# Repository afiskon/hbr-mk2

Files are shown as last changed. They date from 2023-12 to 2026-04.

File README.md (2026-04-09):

# HBR/MK2

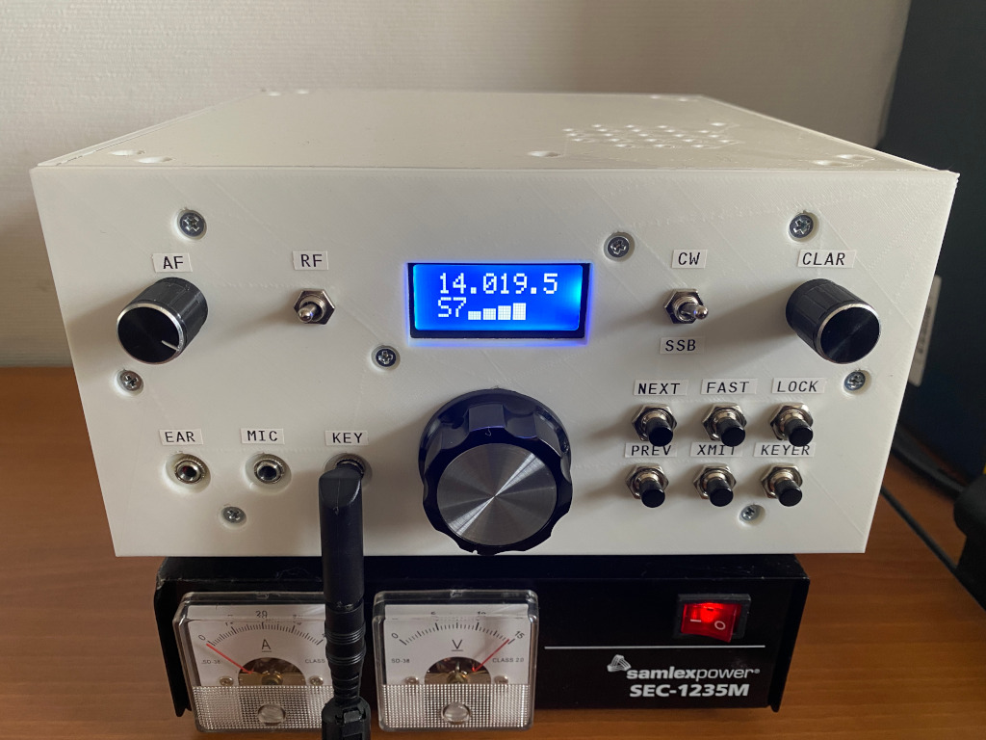
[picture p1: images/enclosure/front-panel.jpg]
HBR/MK2


All HF bands QRP CW/SSB transceiver "HomeBrew Radio, Mark 2".

* Covers 80, 40, 30, 20, 17, 15, 12 and 10 meters
* Classical single IF superheterodyne design
* Effective IF derived AGC
* Voice compression
* Supports RIT and XIT
* 10-30 WPM Elekey-B type keyer + straight key mode
* Keyer supports record and playback, programmable with paddles
* Five favorite frequencies per band (press NEXT/PREV in FAST mode)
* Class AB amplifier provides 5-10W in both CW and SSB
* Has a S-meter and a SWR meter
* Open-source firmware, schematic and 3D-printable enclosure

Links:

* Article (in Russian): https://eax.me/2024/2024-05-12-hbr-mk2-transceiver.html
* Post on Hackaday: https://hackaday.com/2024/05/13/github-hosts-ham-radio/
* Post on DXZone: https://www.dxzone.com/hbr-mk2-hf-qrp-cw-ssb-transceiver/
* Video blog on YouTube: https://www.youtube.com/playlist?list=PL6CWlCy5akj5v1Z4mPysYlqgNtCBYy-wM
* Video blog on Archive.org: https://archive.org/details/hbr-mk2-videos

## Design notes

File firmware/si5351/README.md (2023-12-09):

# stm32-si5351

HAL-based Si5351 driver for STM32.

Main respository: https://github.com/afiskon/stm32-si5351

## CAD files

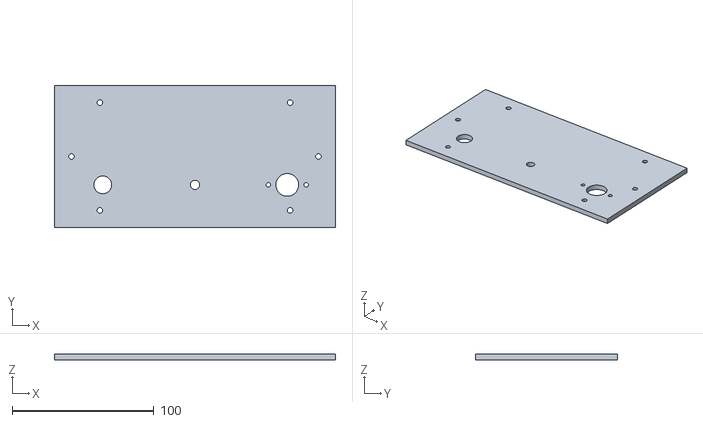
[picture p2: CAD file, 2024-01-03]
enclosure/back.stl
198.0 x 100.0 x 4.00

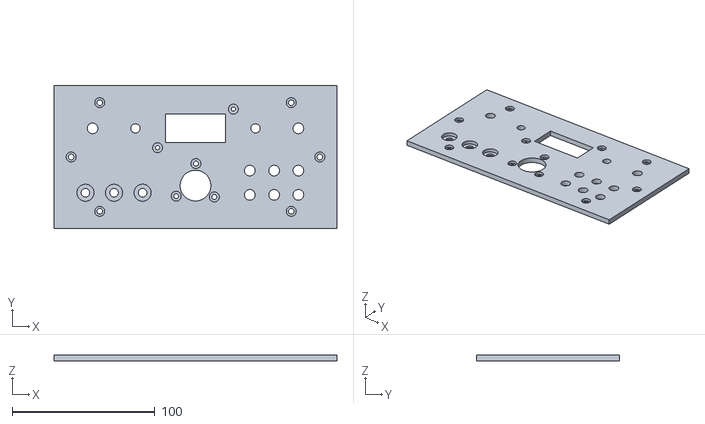
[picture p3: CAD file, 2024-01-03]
enclosure/front.stl
198.0 x 100.0 x 4.00

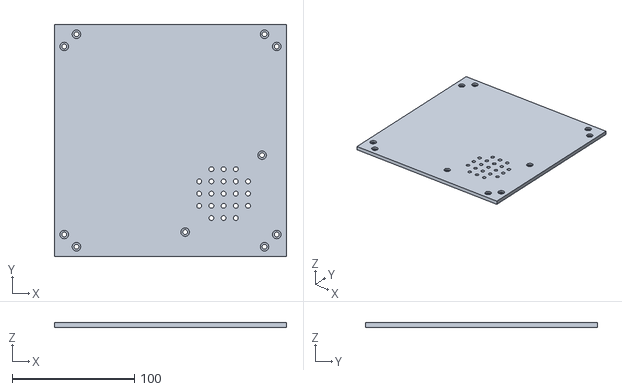
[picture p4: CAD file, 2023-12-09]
enclosure/top.stl
190.0 x 190.0 x 4.00

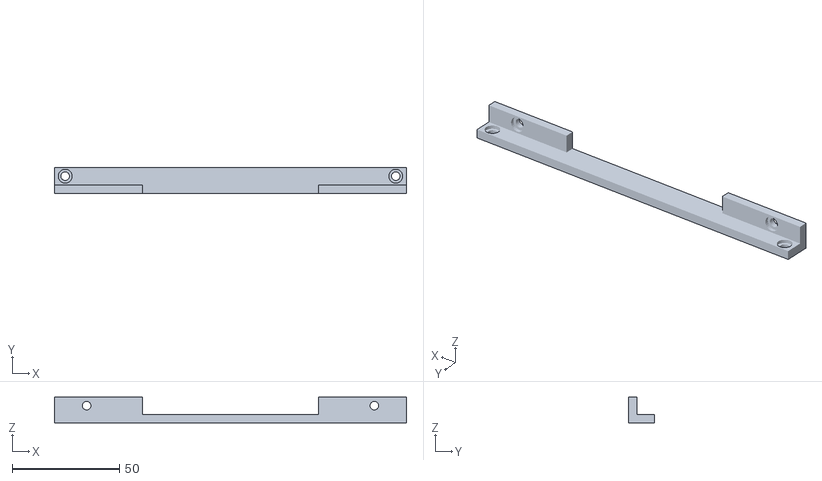
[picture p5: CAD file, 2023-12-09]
enclosure/large_angle.stl
164.0 x 12.0 x 12.0

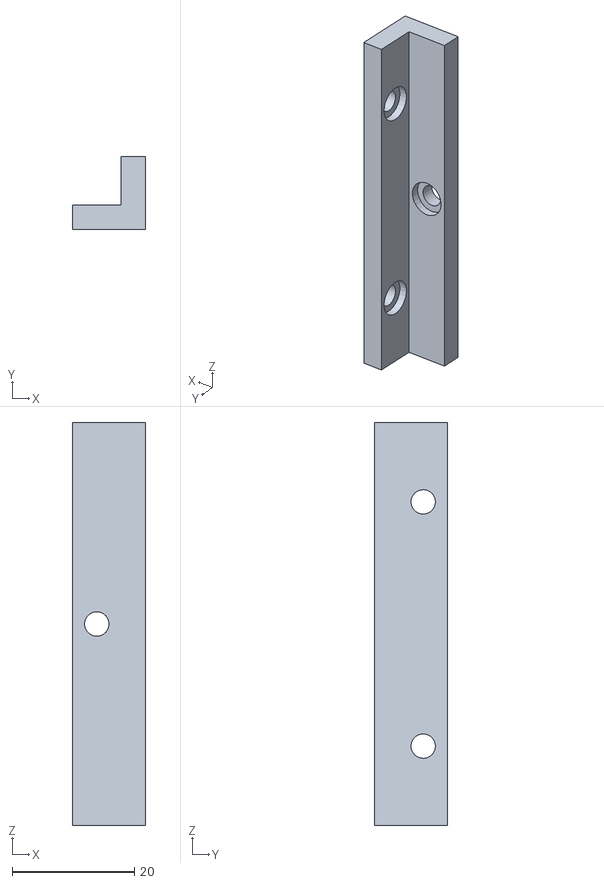
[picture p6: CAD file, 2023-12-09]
enclosure/small_angle.stl
12.0 x 12.0 x 66.0

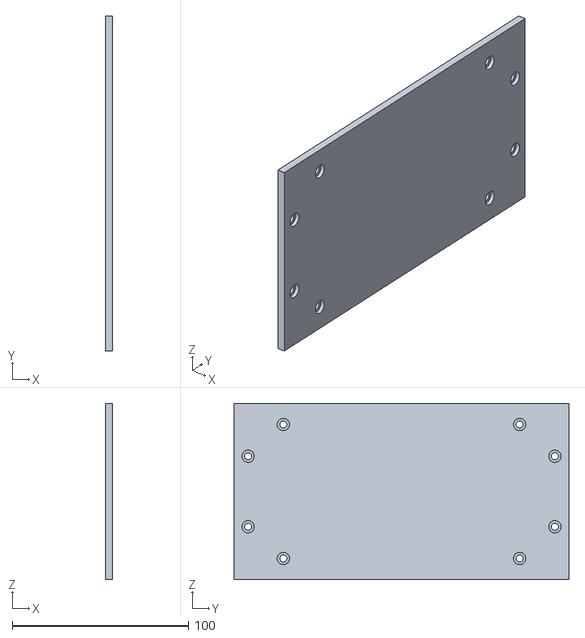
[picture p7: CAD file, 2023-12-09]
enclosure/side.stl
4.00 x 190.0 x 100.0

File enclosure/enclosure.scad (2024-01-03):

t = 4;
W = 190;
Front_W = W + t*2;
H = 100;

Angle_W = 12;
Large_Angle_L = W - 2*Angle_W - 2;
Small_Angle_L = H - 2*t - 2*Angle_W - 2;

Speaker_Dist_Between_Holes = 63;

pot_dia = 7+0.5; // volume control
jack_dia = 6; // 3.5 mm jack
jack_nut_dia = 12;
jack_nut_height = t-1.2;
button_dia = 7+0.5; // button
button_offset = 17;
toggle_dia = 6+0.5; // toggle switch
corner_dia = 7;
screw_dia = 4;
screw_offset = t*3;
screw_extra_offset = 20;
screw2_dia = 7;
screw2_height = 2;
nut_dia = 6.5;
nut_height = 1.5;
eps = 0.01;

main_enc_dia = 21+0.5;
main_enc_screws_dia = 15;
main_enc_screws_dist = 7;
main_enc_rotate_delta = 12;
main_enc_screw_dia = 3.5;
multi_enc_dia = 7+0.5; // CLAR pot

// LCD info
LCD_W = 58;
LCD_H = 32;
lcd_offset_y = 8;
lcd_offset_x = 6;
lcd_h = LCD_H - lcd_offset_x*2;
lcd_w = LCD_W - lcd_offset_y*2;

hole_dia = 3;
hole_offset_x = 1+hole_dia/2;
hole_offset_y = 1+hole_dia/2;

module so239() { // two holes
    front_d = 16;
    front_off = 18.8;
    front_hole_d = 3.2;

    rotate([0, 45, 0]) {
        translate([0, 0, 0]) rotate([90,0,0])
            cylinder(d=front_d,h=20, $fn=100, center=true);

        translate([-front_off/2, 0, -front_off/2]) rotate([90,0,0])
            cylinder(d=front_hole_d,h=20,$fn=100, center=true);

        translate([front_off/2, 0, front_off/2]) rotate([90,0,0])
            cylinder(d=front_hole_d,h=20,$fn=100, center=true);
    }
}

module speaker() {
    union() {
        translate([Speaker_Dist_Between_Holes/2, -Speaker_Dist_Between_Holes/2, 0]) {
            cylinder(d = screw_dia, h = 20, $fn = 20, center = true);
            translate([0, 0, -(t-screw2_height)/2-eps])
                cylinder(d = screw2_dia, h = screw2_height+eps, $fn = 25, center = true);
        }
                
        translate([-Speaker_Dist_Between_Holes/2, Speaker_Dist_Between_Holes/2, 0]) {
            cylinder(d = screw_dia, h = 20, $fn = 20, center = true);
            translate([0, 0, -(t-screw2_height)/2-eps])
                cylinder(d = screw2_dia, h = screw2_height+eps, $fn = 25, center = true);
        }
                
        translate([10, 20, 0]) cylinder(d = screw_dia, h = 20, $fn = 20, center = true);
        translate([0, 20, 0]) cylinder(d = screw_dia, h = 20, $fn = 20, center = true);
        translate([-10, 20, 0]) cylinder(d = screw_dia, h = 20, $fn = 20, center = true);
        
        translate([10, 10, 0]) cylinder(d = screw_dia, h = 20, $fn = 20, center = true);
        translate([10, 0, 0]) cylinder(d = screw_dia, h = 20, $fn = 20, center = true);
        translate([10, -10, 0]) cylinder(d = screw_dia, h = 20, $fn = 20, center = true);
        
        translate([20, 10, 0]) cylinder(d = screw_dia, h = 20, $fn = 20, center = true);
        translate([20, 0, 0]) cylinder(d = screw_dia, h = 20, $fn = 20, center = true);
        translate([20, -10, 0]) cylinder(d = screw_dia, h = 20, $fn = 20, center = true);

        translate([0, 0, 0]) cylinder(d = screw_dia, h = 20, $fn = 200, center = true);
        translate([0, -10, 0]) cylinder(d = screw_dia, h = 20, $fn = 20, center = true);
        translate([0, 10, 0]) cylinder(d = screw_dia, h = 20, $fn = 20, center = true);
        
        translate([-10, 10, 0]) cylinder(d = screw_dia, h = 20, $fn = 20, center = true);
        translate([-10, 0, 0]) cylinder(d = screw_dia, h = 20, $fn = 20, center = true);
        translate([-10, -10, 0]) cylinder(d = screw_dia, h = 20, $fn = 20, center = true);
        
        translate([-20, 10, 0]) cylinder(d = screw_dia, h = 20, $fn = 20, center = true);
        translate([-20, 0, 0]) cylinder(d = screw_dia, h = 20, $fn = 20, center = true);
        translate([-20, -10, 0]) cylinder(d = screw_dia, h = 20, $fn = 20, center = true); 
        
        translate([10, -20, 0]) cylinder(d = screw_dia, h = 20, $fn = 20, center = true);
        translate([0, -20, 0]) cylinder(d = screw_dia, h = 20, $fn = 20, center = true);
        translate([-10, -20, 0]) cylinder(d = screw_dia, h = 20, $fn = 20, center = true);
    }
}

module front_back_base() {
    difference() {
       cube([Front_W, H, t], center = true);
        
        // screws
        translate([-Front_W/2+screw_offset+screw_extra_offset, H/2-screw_offset, 0]) {
            cylinder(d = screw_dia, h = t*2, $fn = 25, center = true);
            translate([0, 0, (t-screw2_height)/2+eps])
                cylinder(d = screw2_dia, h = screw2_height+eps, $fn = 25, center = true);
        } 
        
        translate([-Front_W/2+screw_offset+screw_extra_offset, -H/2+screw_offset, 0]) {
            cylinder(d = screw_dia, h = t*2, $fn = 25, center = true);
            translate([0, 0, (t-screw2_height)/2+eps])
                cylinder(d = screw2_dia, h = screw2_height+eps, $fn = 25, center = true);
        }
        
        translate([Front_W/2-screw_offset-screw_extra_offset, H/2-screw_offset, 0]) {
            cylinder(d = screw_dia, h = t*2, $fn = 25, center = true);
            translate([0, 0, (t-screw2_height)/2+eps])
                cylinder(d = screw2_dia, h = screw2_height+eps, $fn = 25, center = true);
        }
        
        translate([Front_W/2-screw_offset-screw_extra_offset, -H/2+screw_offset, 0]) {
            cylinder(d = screw_dia, h = t*2, $fn = 25, center = true);
            translate([0, 0, (t-screw2_height)/2+eps])
                cylinder(d = screw2_dia, h = screw2_height+eps, $fn = 25, center = true);
        }
        
        // center screws
       translate([-Front_W/2+screw_offset, 0, 0]) {
            cylinder(d = screw_dia, h = t*2, $fn = 25, center = true);
            translate([0, 0, (t-screw2_height)/2+eps])
                cylinder(d = screw2_dia, h = screw2_height+eps, $fn = 25, center = true);
        }
        translate([Front_W/2-screw_offset, 0, 0]) {
            cylinder(d = screw_dia, h = t*2, $fn = 25, center = true);
            translate([0, 0, (t-screw2_height)/2+eps])
                cylinder(d = screw2_dia, h = screw2_height+eps, $fn = 25, center = true);
        } 
    }
}
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

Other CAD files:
enclosure/bottom.stl

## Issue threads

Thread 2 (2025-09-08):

Request for information

hanslammerts, 2025-09-08:
Hi,

Thinking of building this trx.
I'm missing some info though.

Can you please tell me what wire you used for all the coils ?
I also cannot find any info about the rotary encoder used.

Thanks, 73,
Hans
PA3CRZ

afiskon, 2025-09-09:
Thanks for your interest to the project.

Personally I used 0.3 mm thick (~ AWG 28) for small coils (e.g. BPFs) and 0.6 mm thick for larger ones (e.g. PA).

The wire gauge is not critical however.

afiskon, 2025-09-10:
@hanslammerts  If I'm not wrong, the particular model is E38S6G5-600B-G24N (took a similar one from my box of spare parts). This being said all such optical encoders are more or less the same, so there is no need to look for this particular model.

Closed 2025-09-09.

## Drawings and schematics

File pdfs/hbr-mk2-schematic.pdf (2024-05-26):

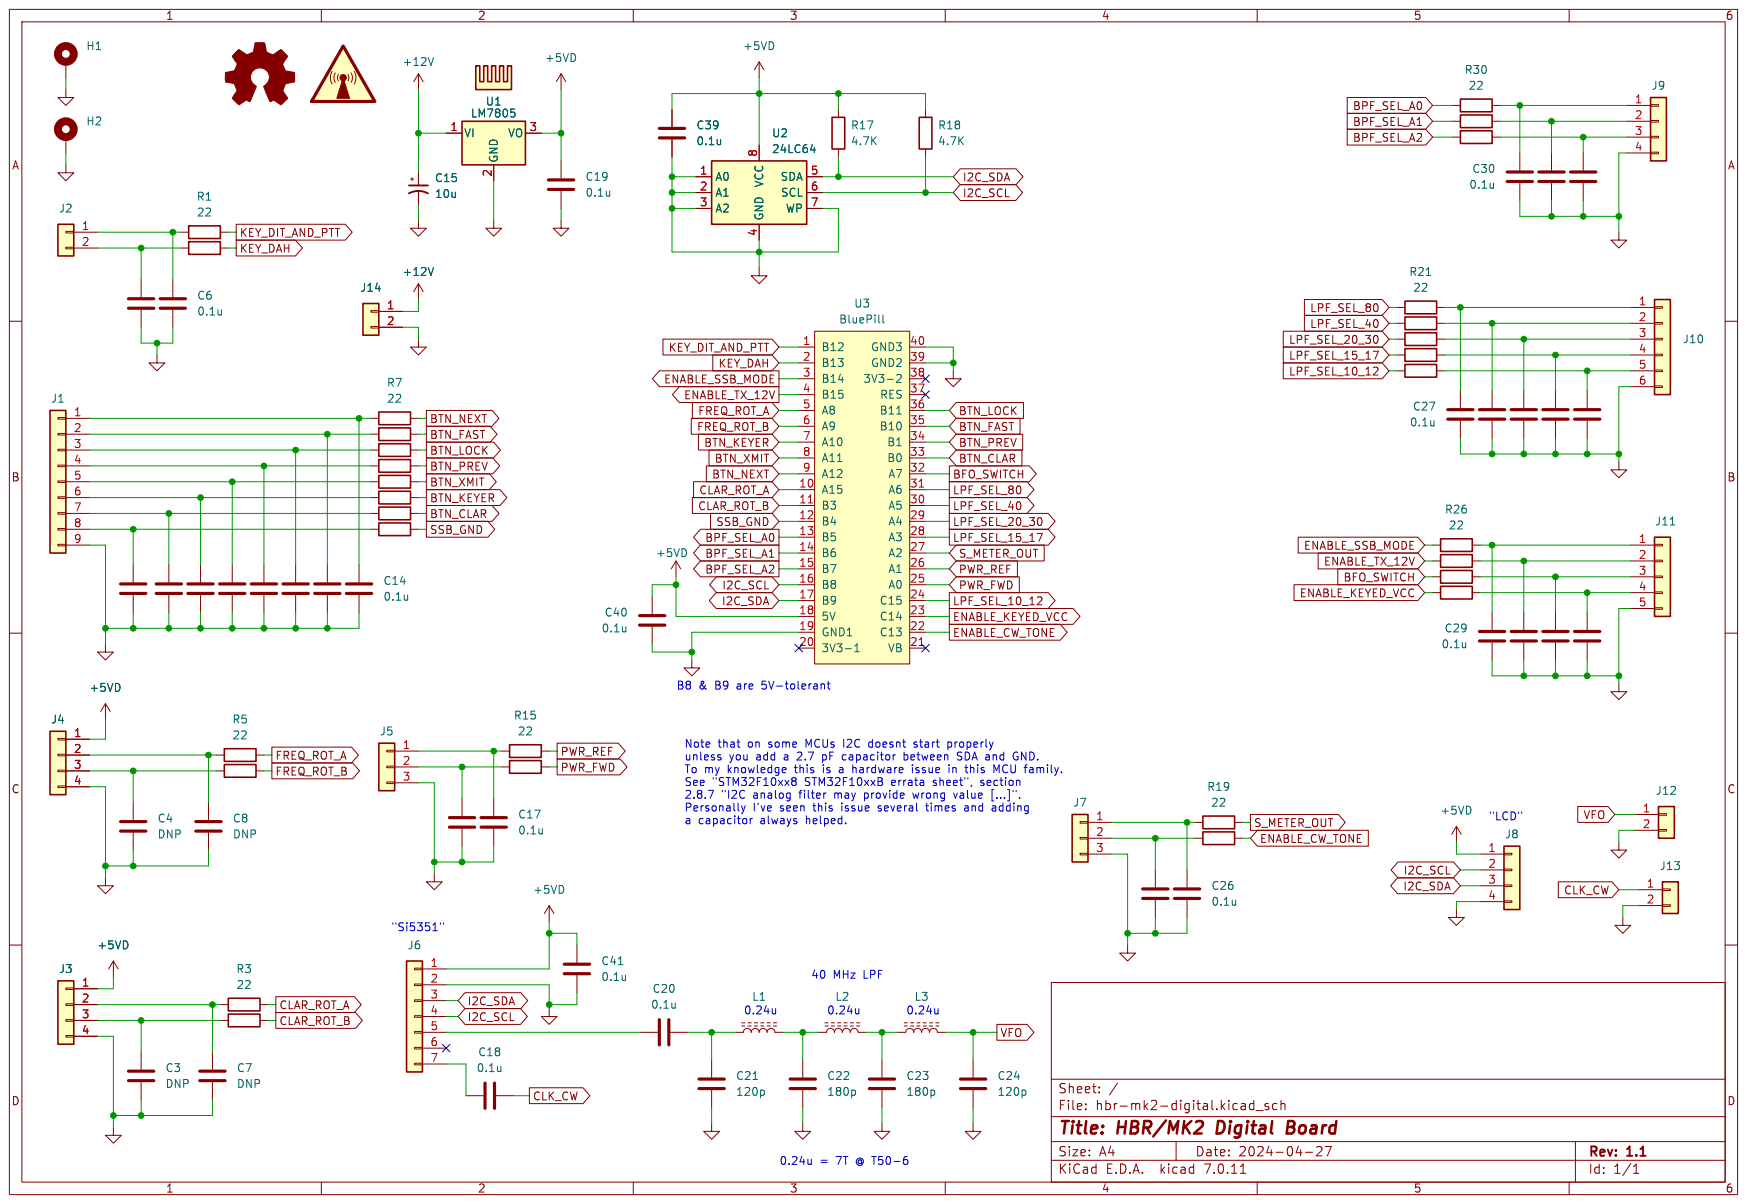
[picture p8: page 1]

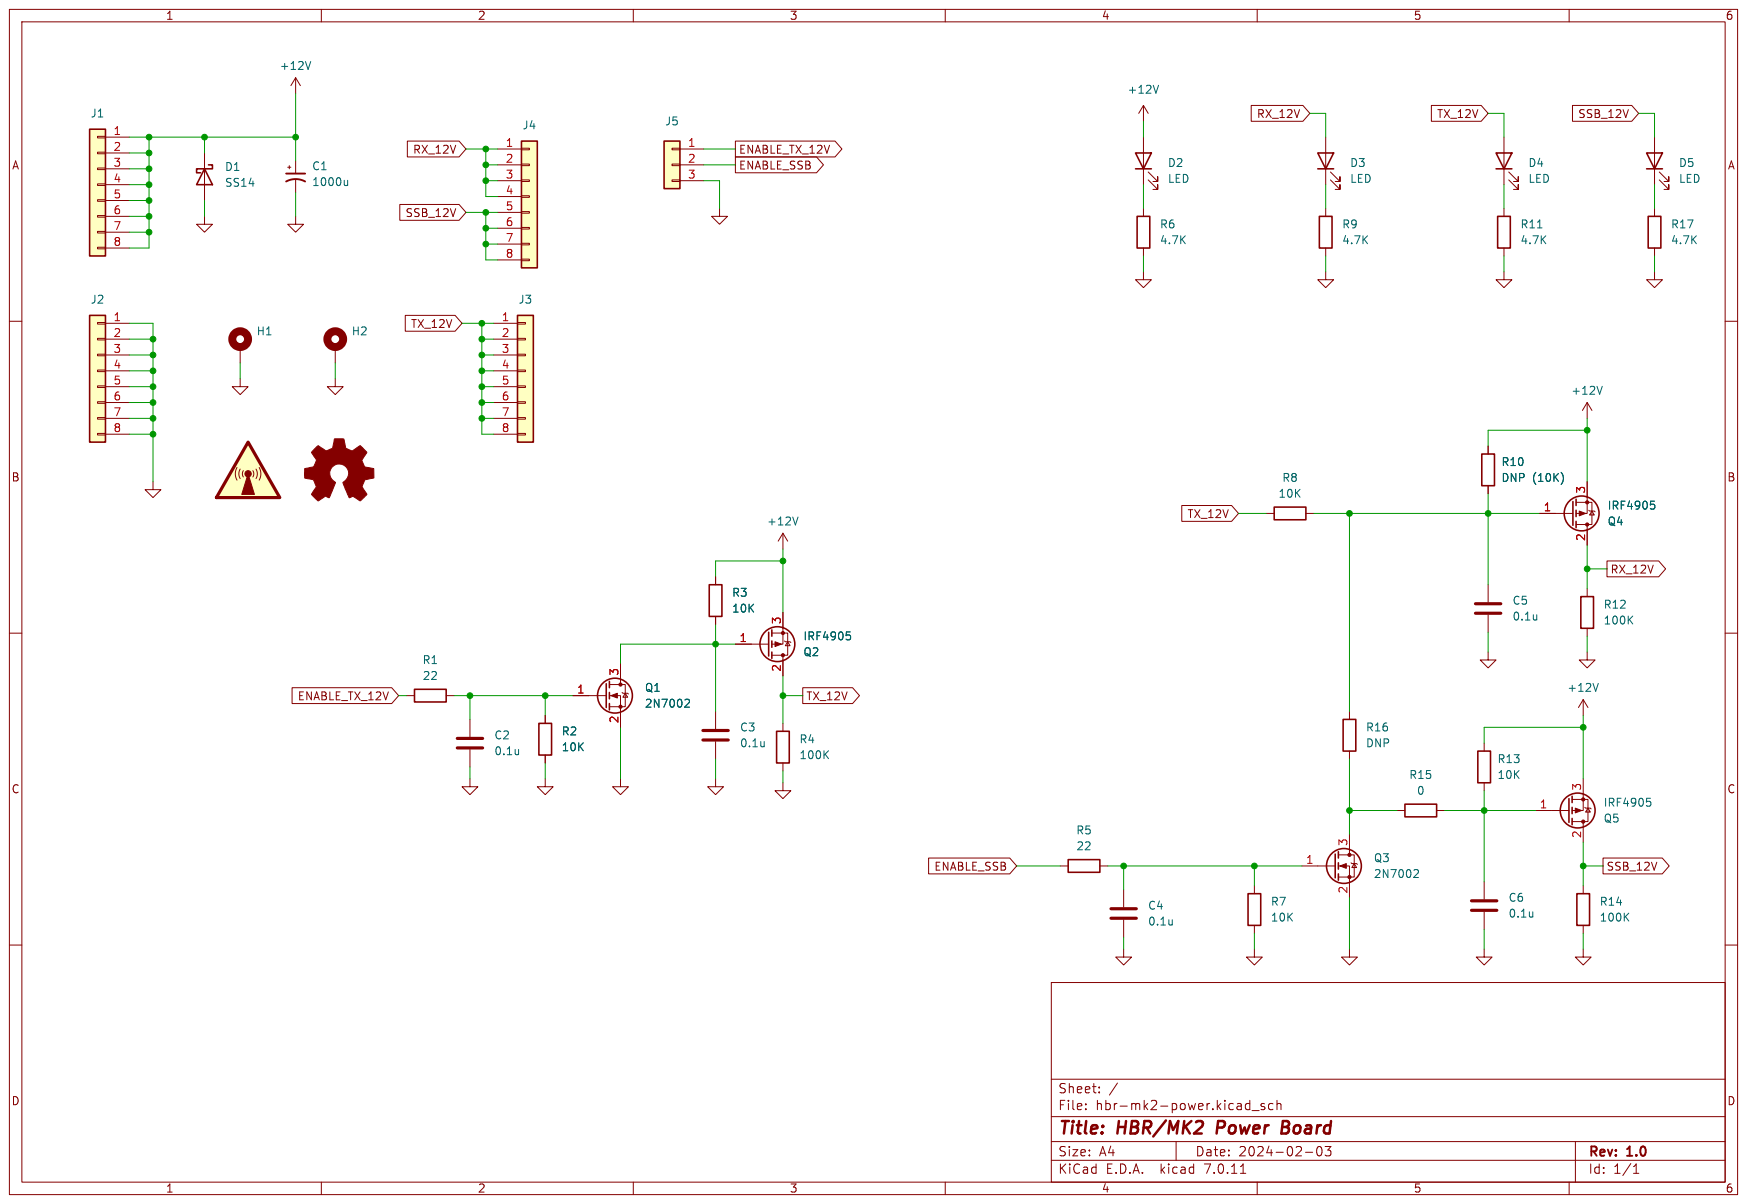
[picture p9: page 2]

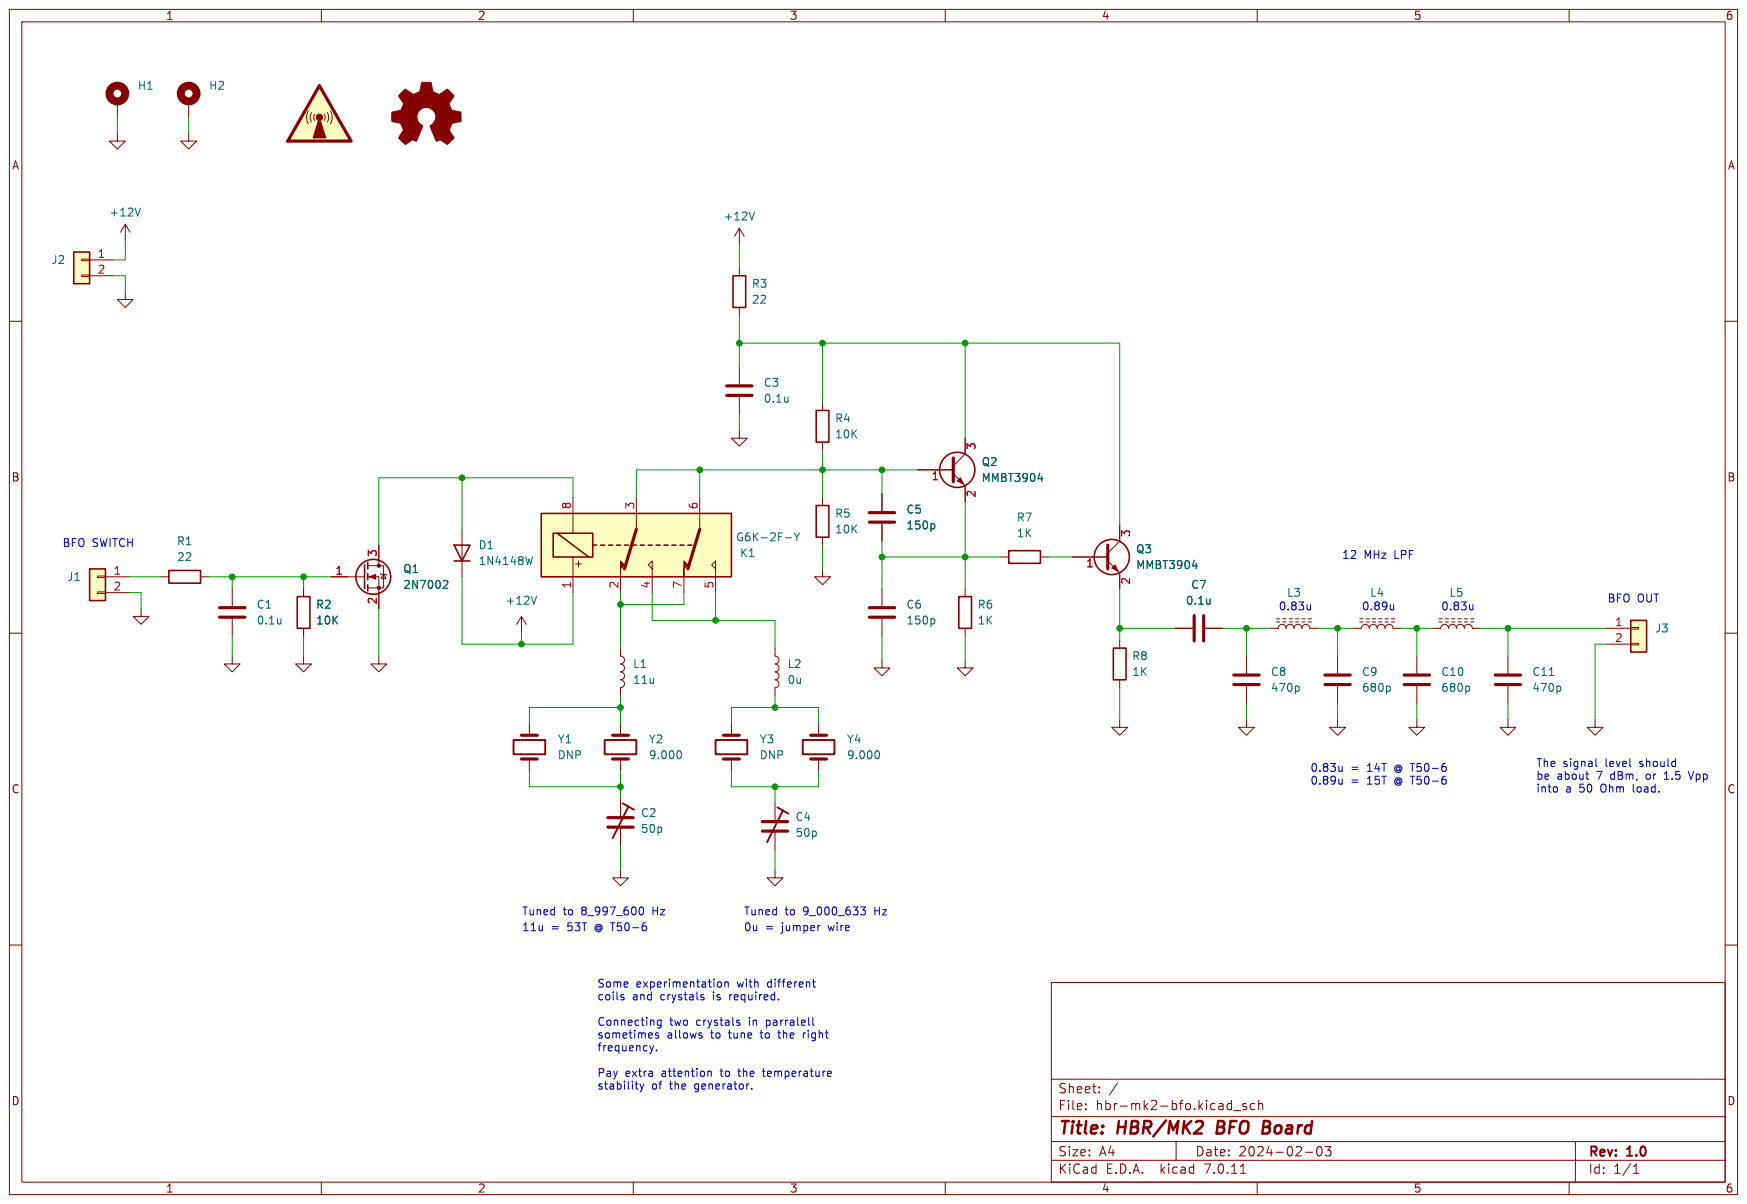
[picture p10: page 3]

be about 7 dBm, or 1.5 Vpp
into a 50 Ohm load.

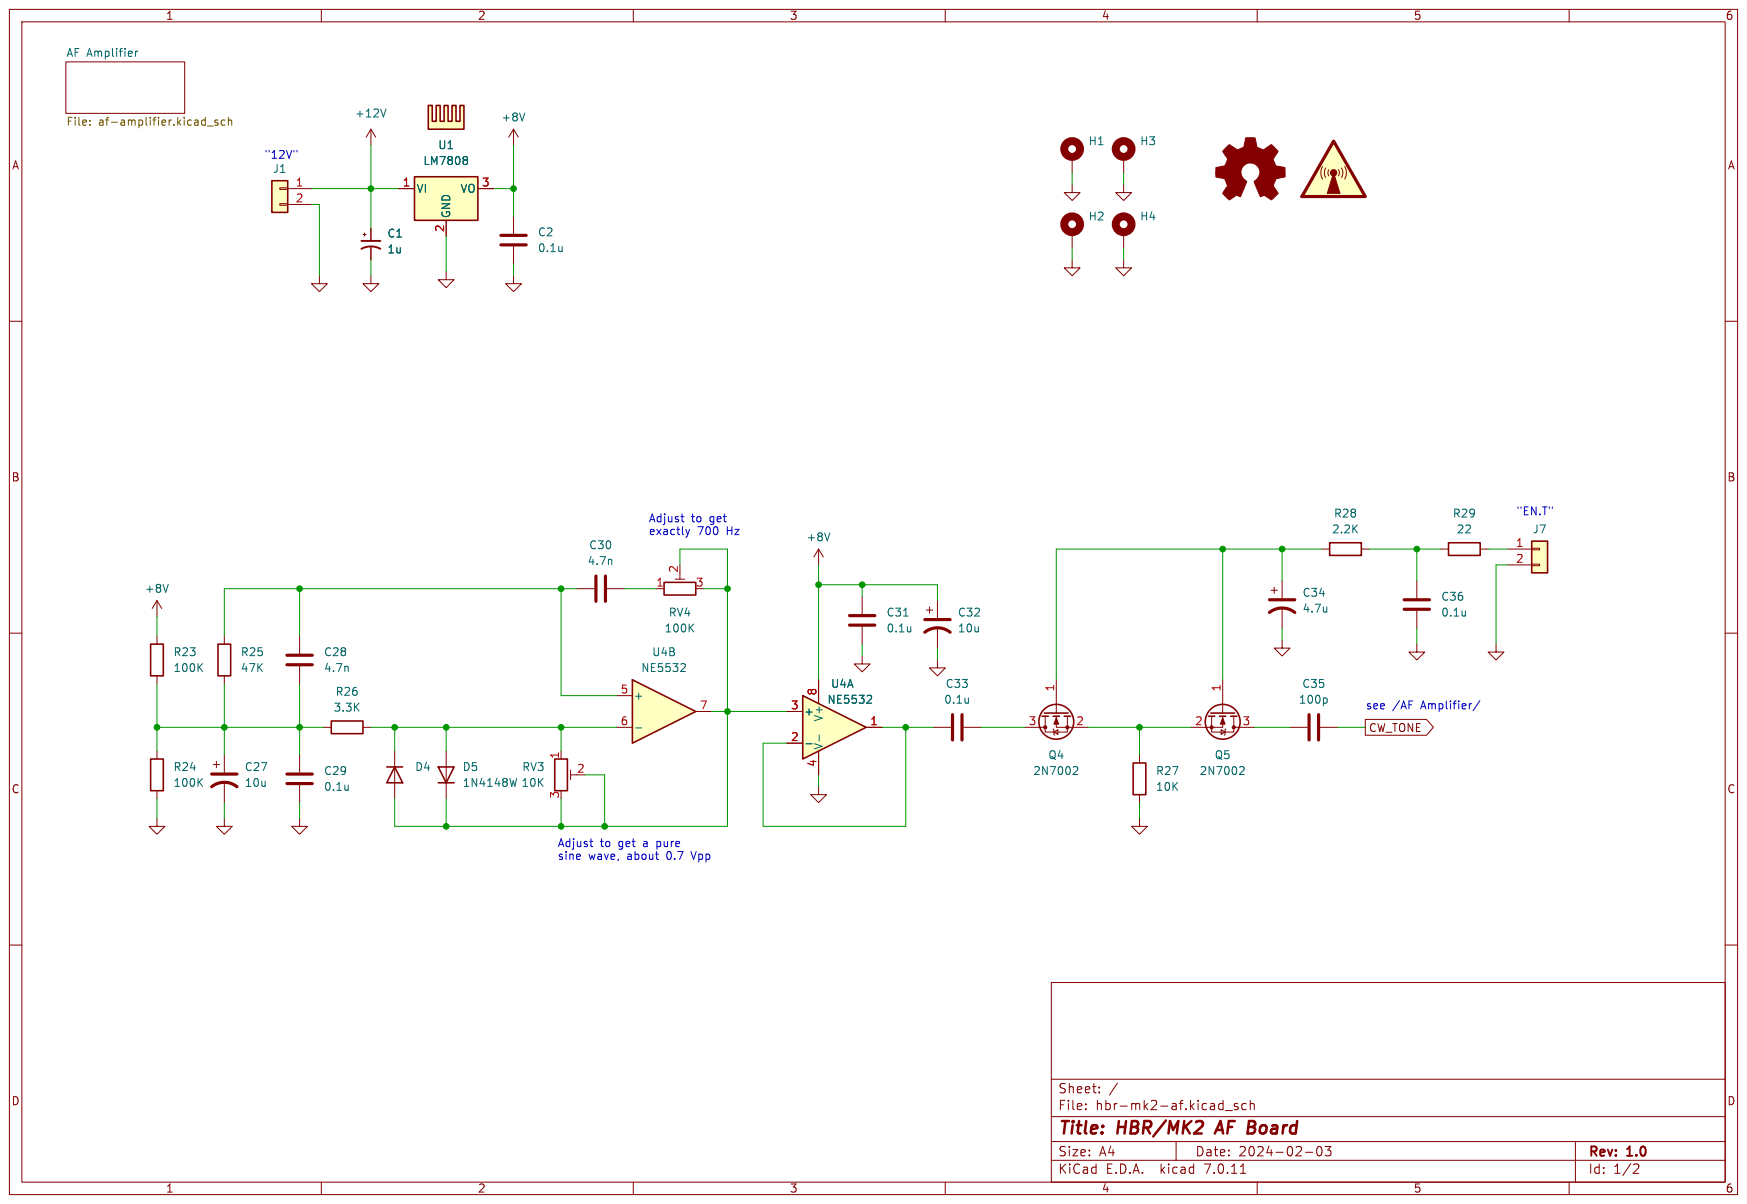
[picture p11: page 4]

Adjust to get a pure
sine wave, about 0.7 Vpp

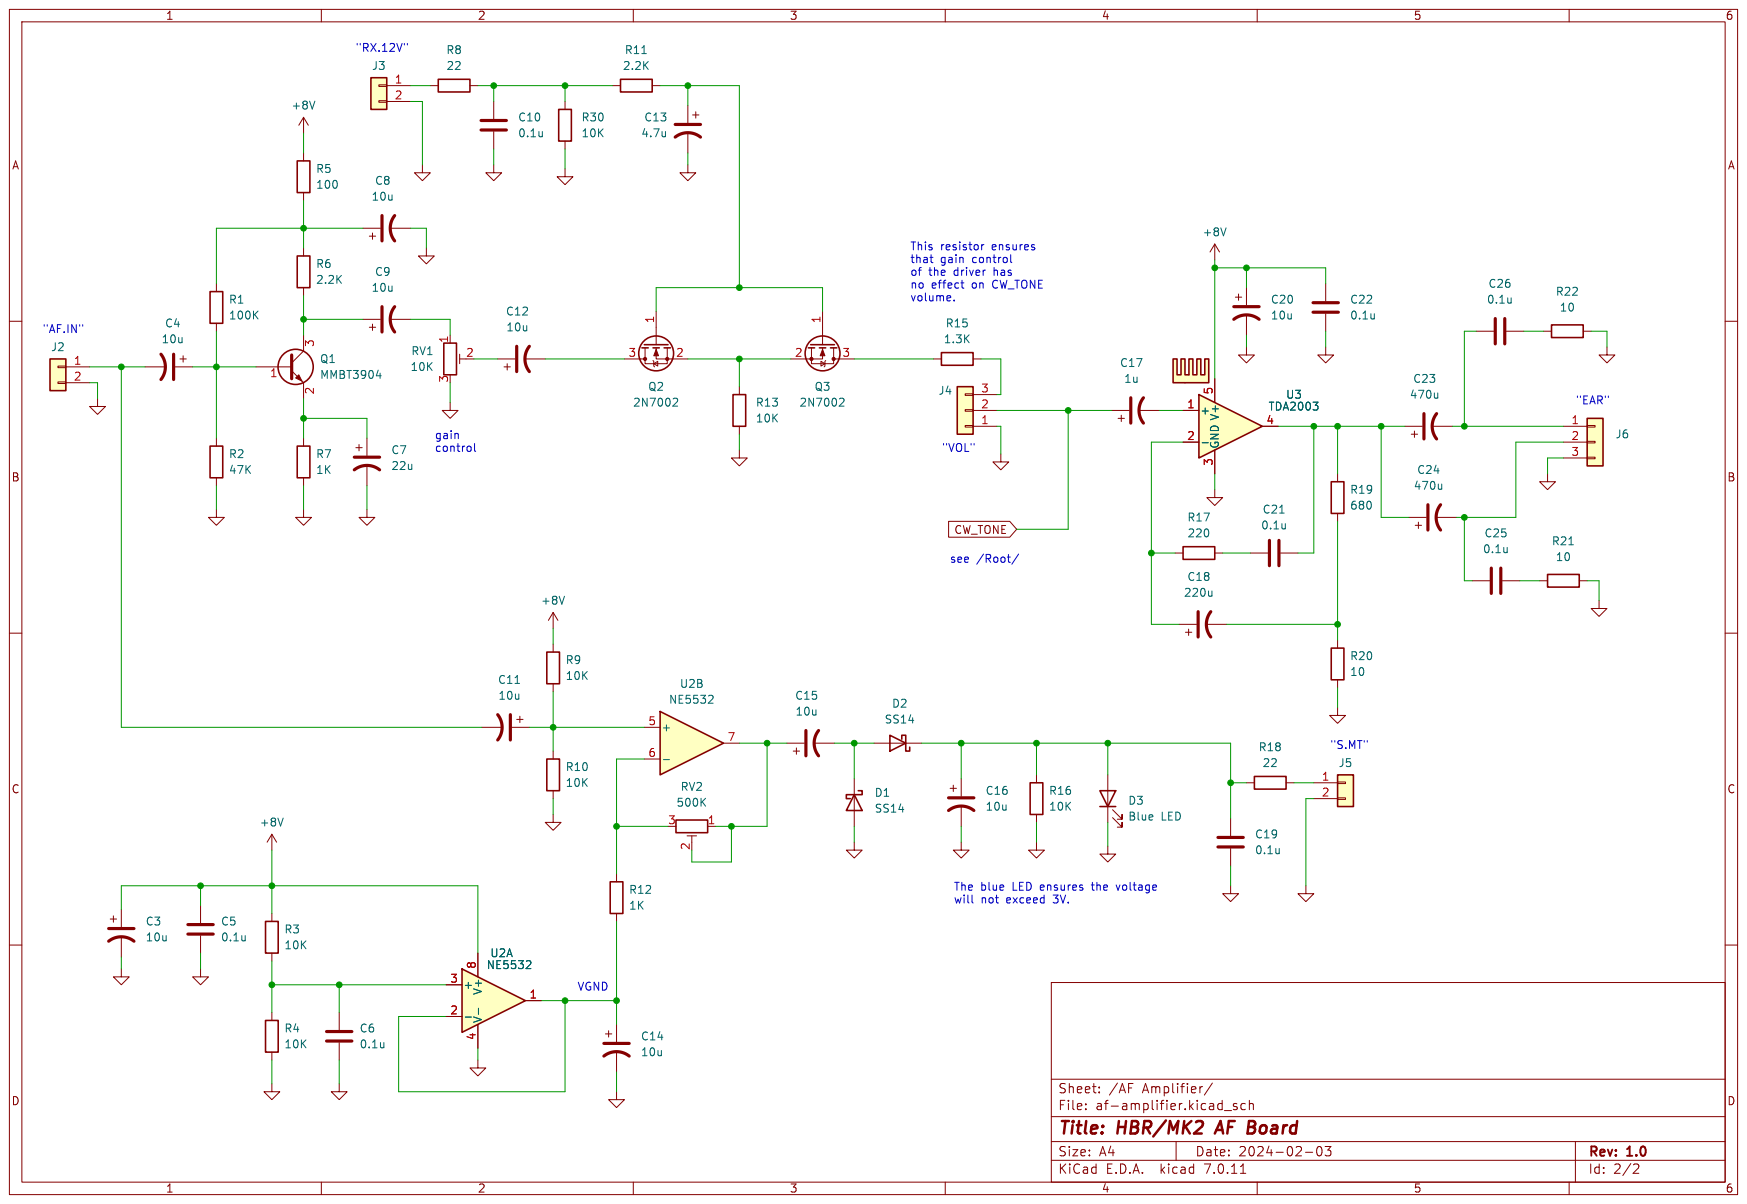
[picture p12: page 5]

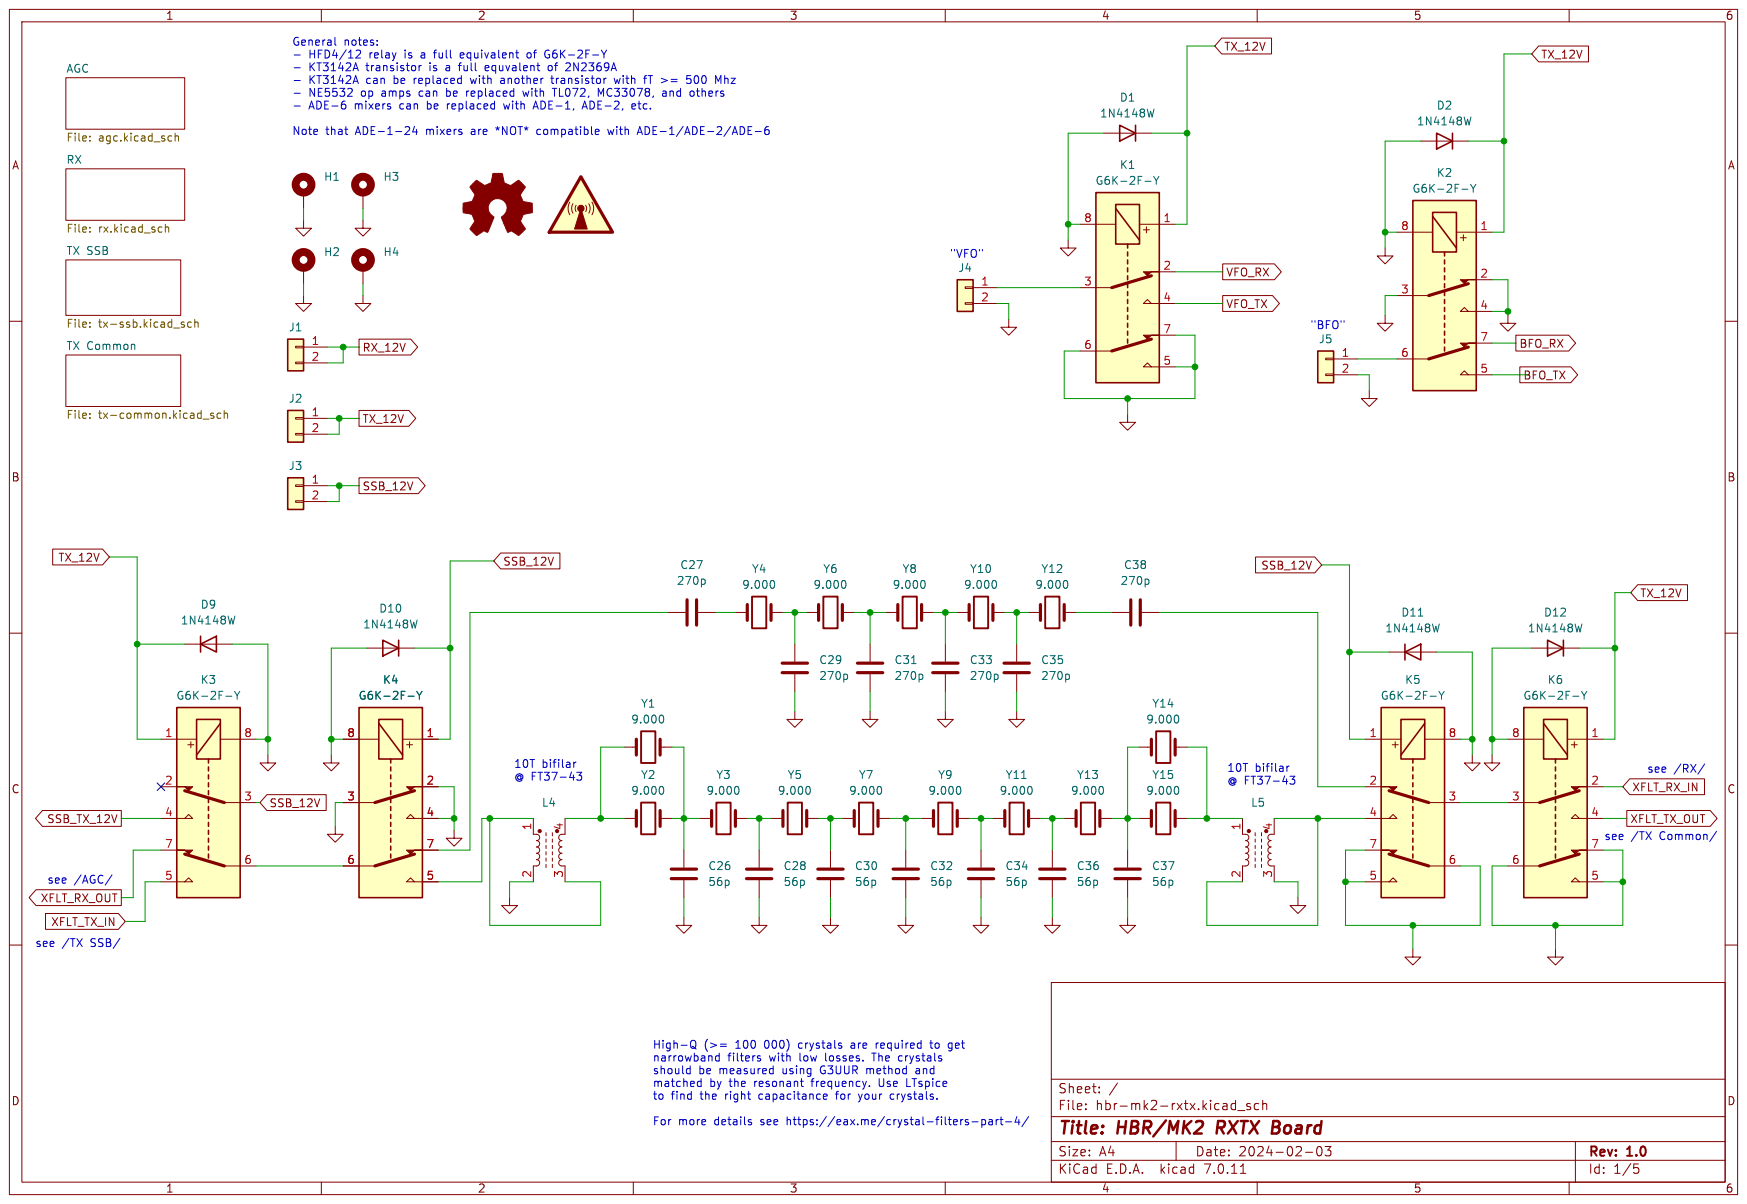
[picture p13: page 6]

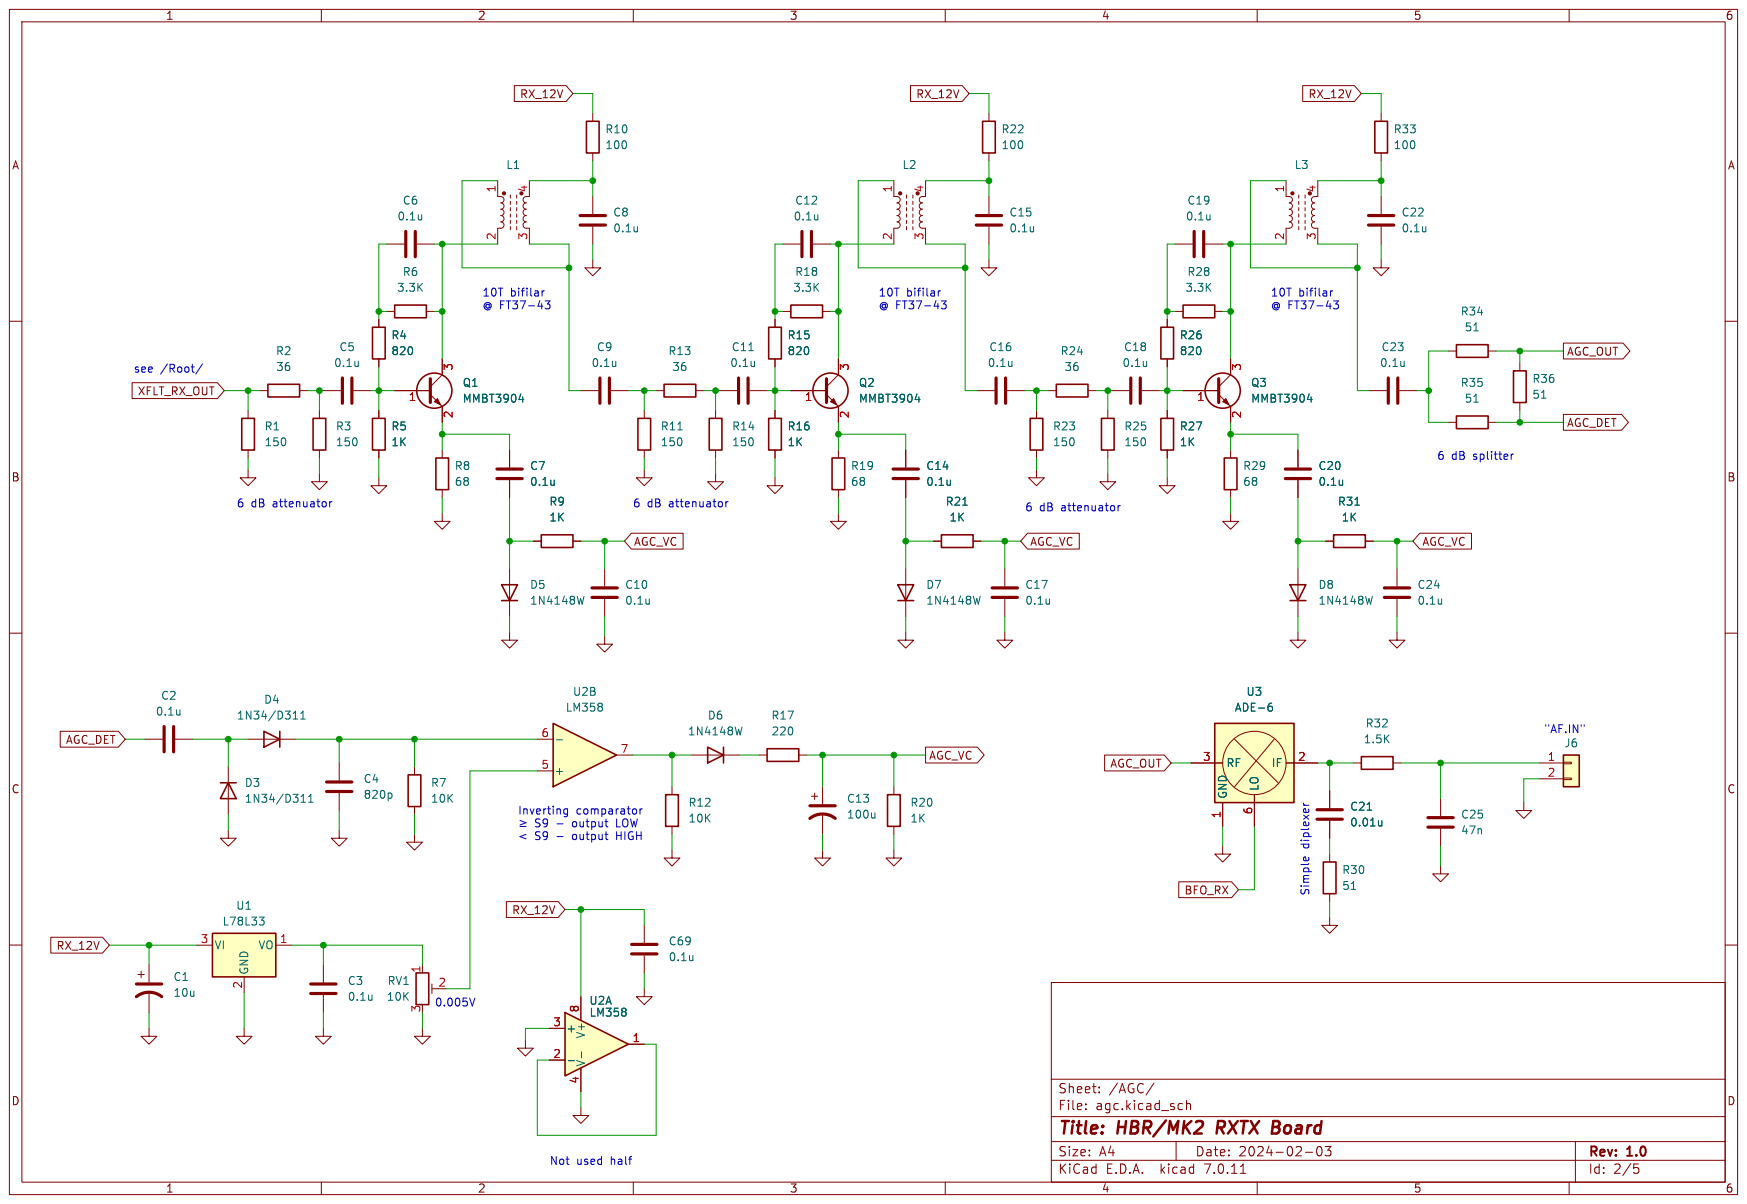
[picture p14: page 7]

6 dB attenuator

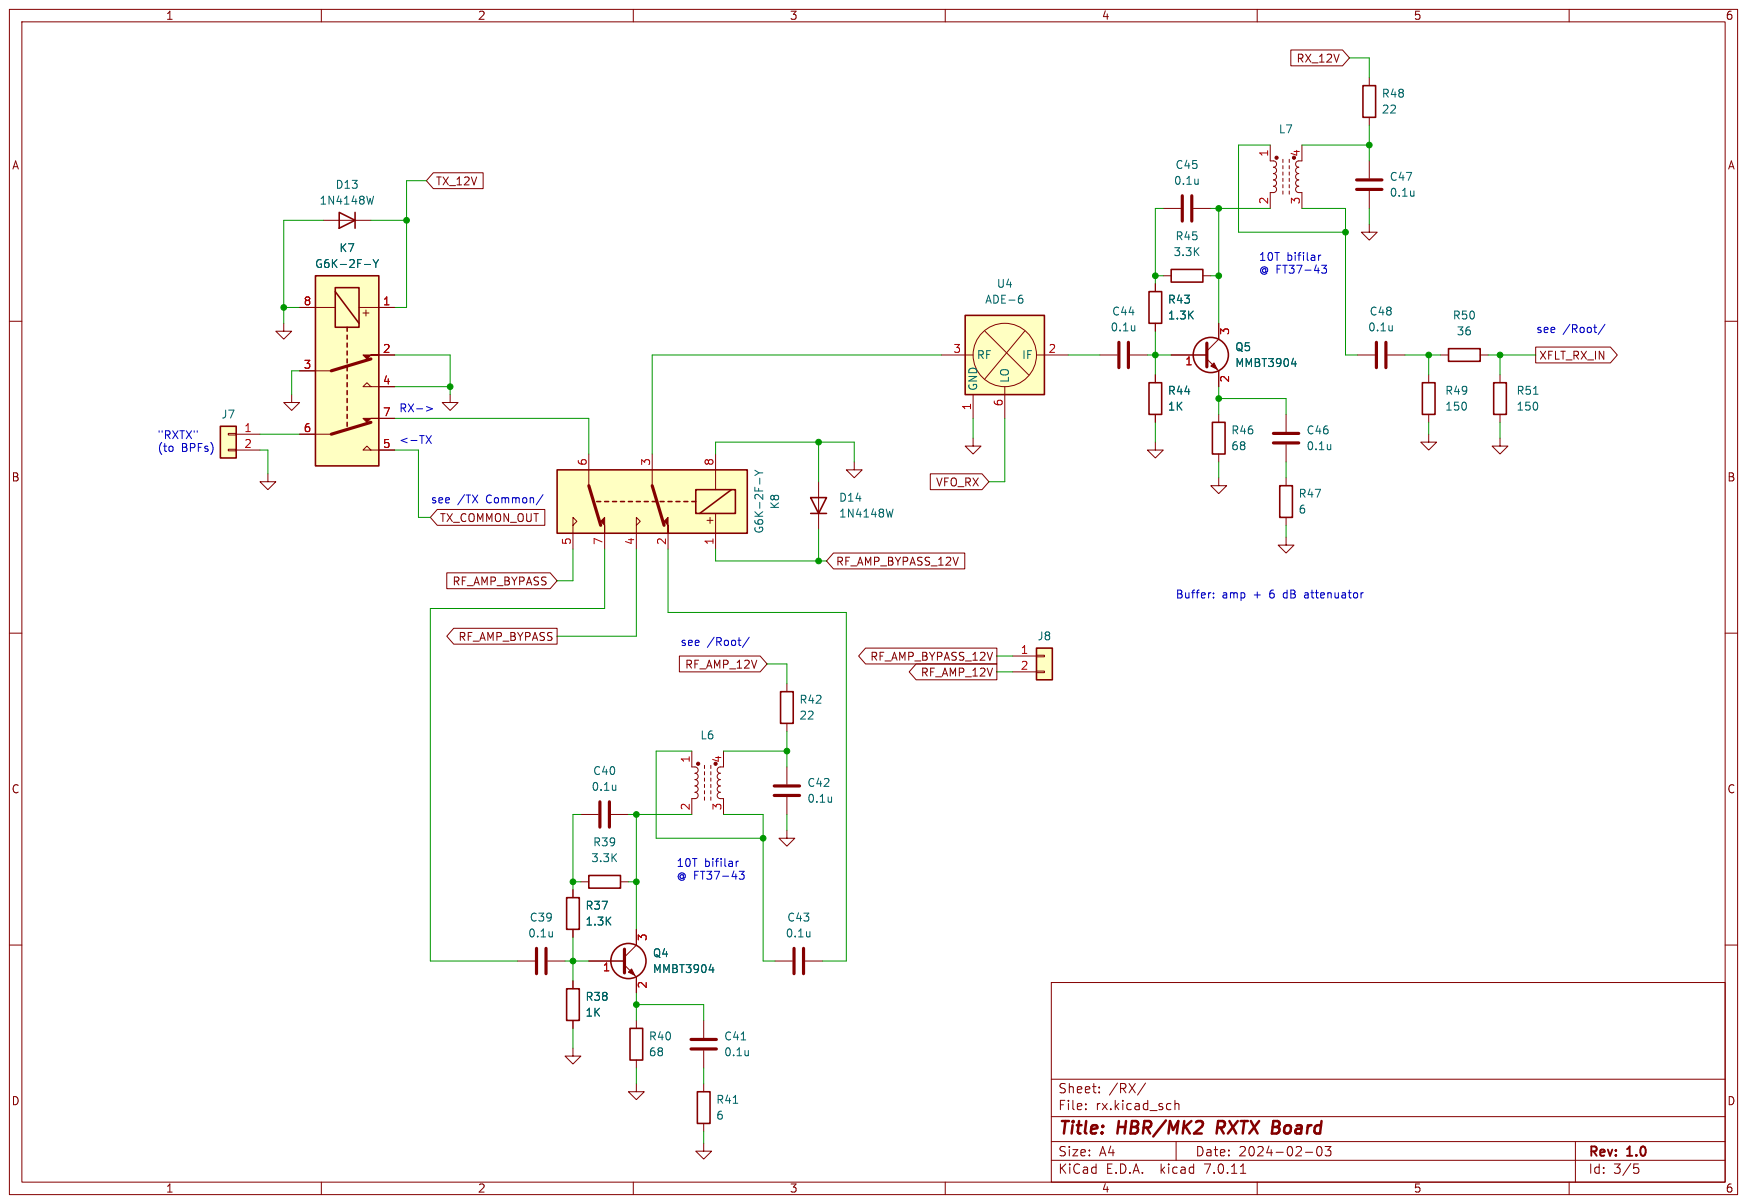
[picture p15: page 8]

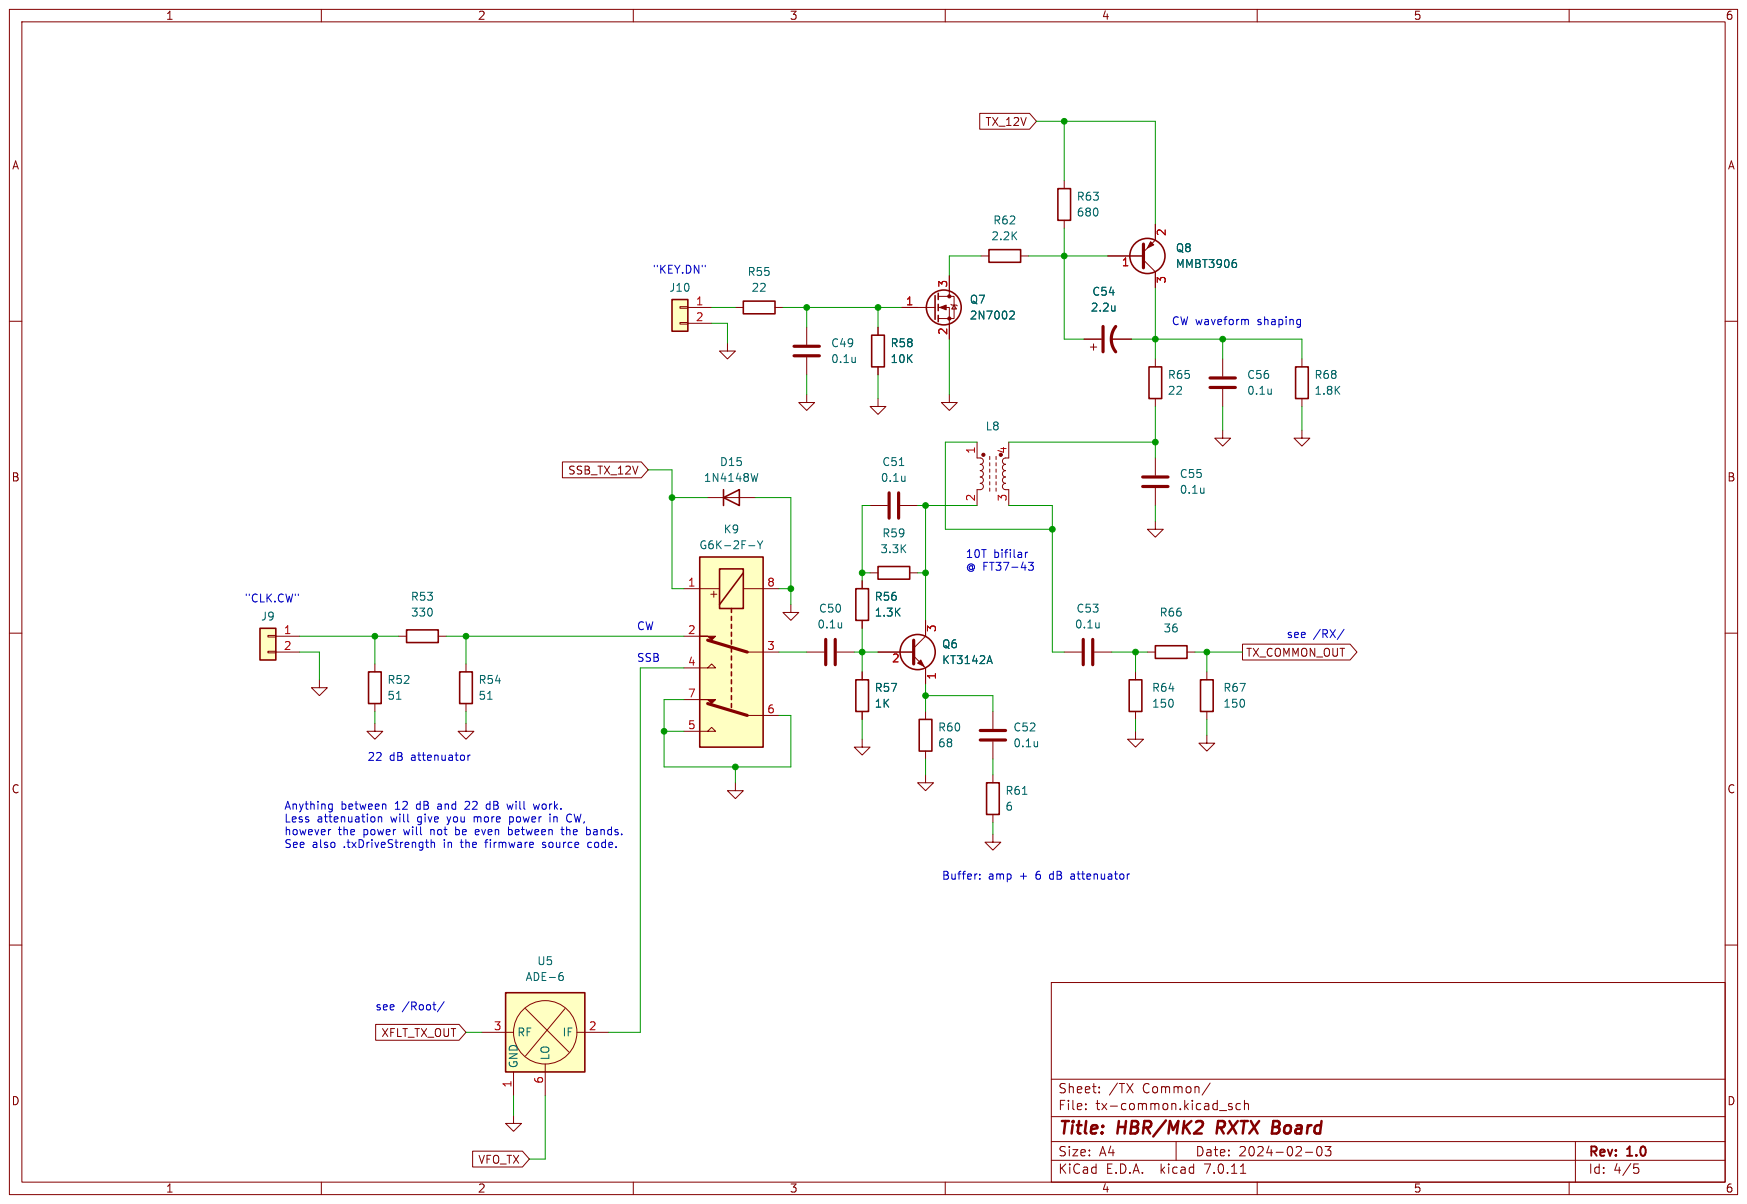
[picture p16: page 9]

however the power will not be even between the bands.

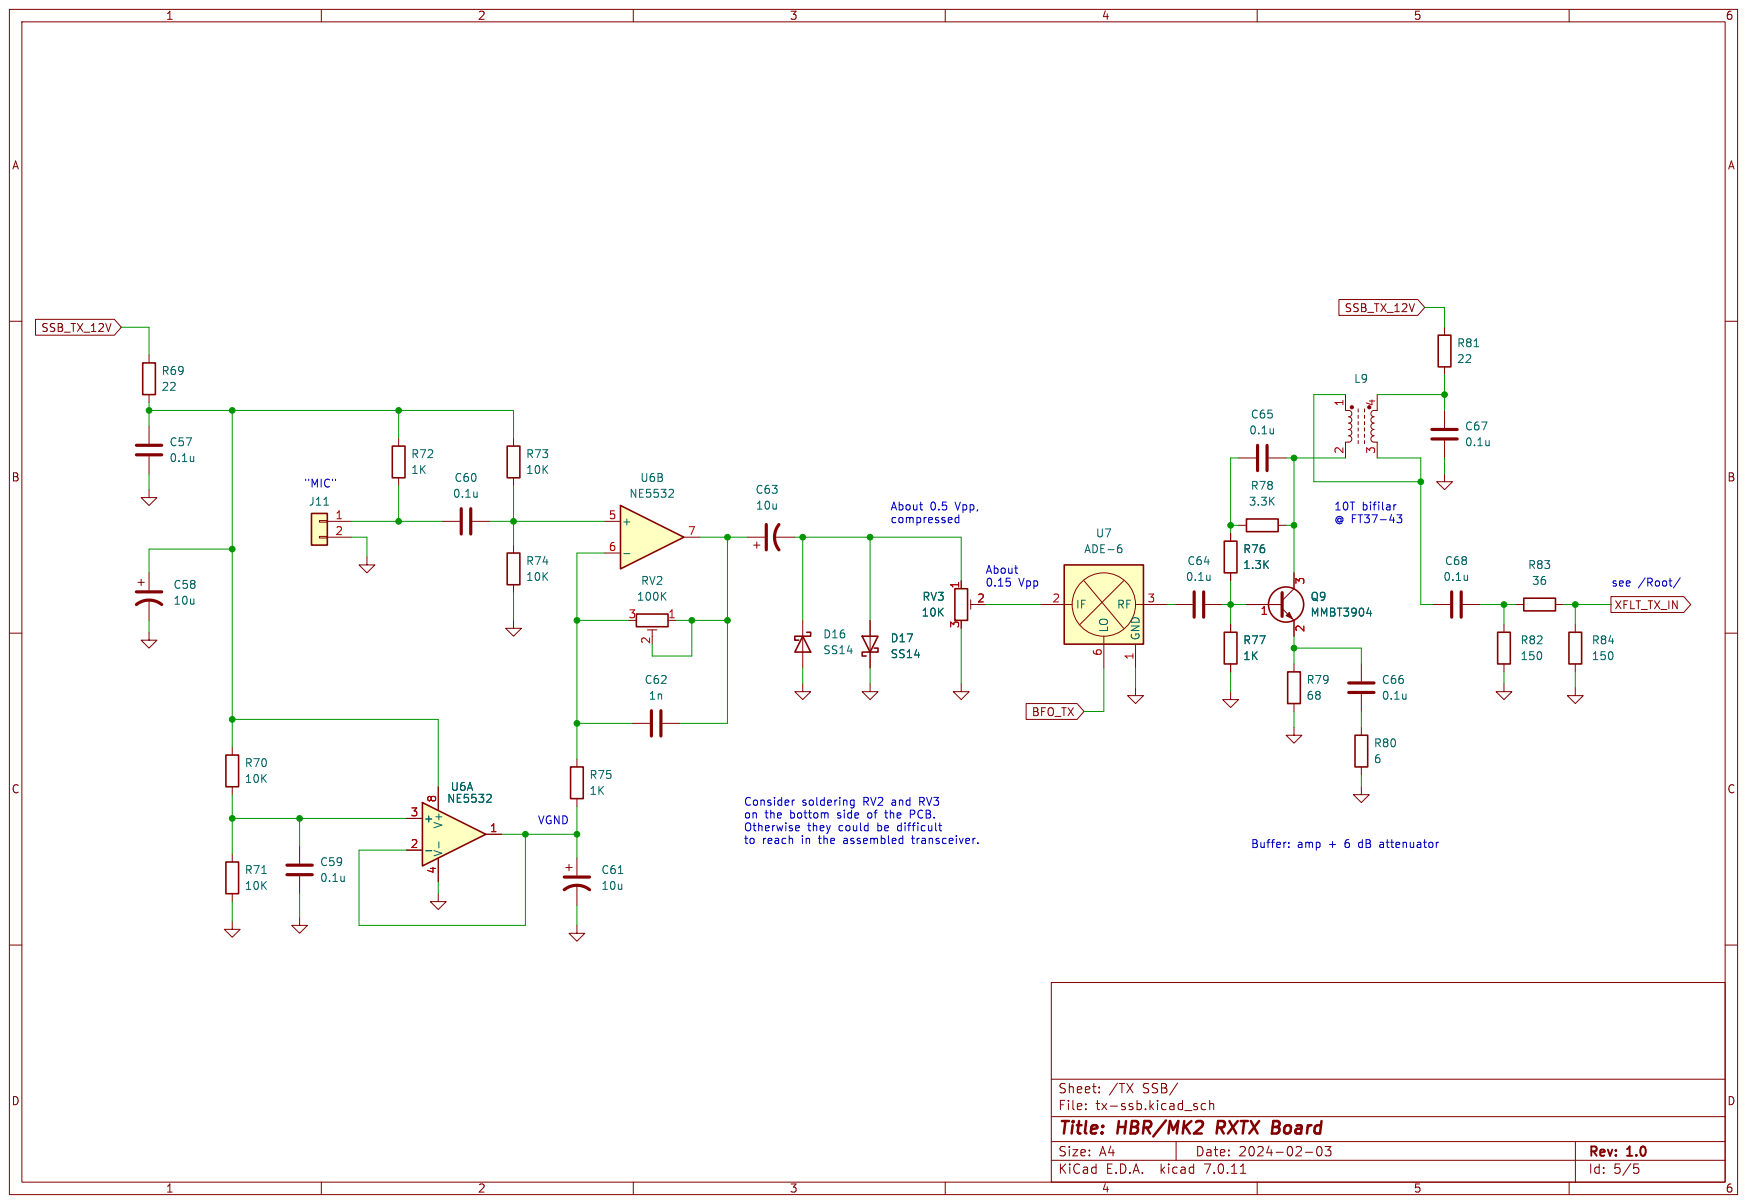
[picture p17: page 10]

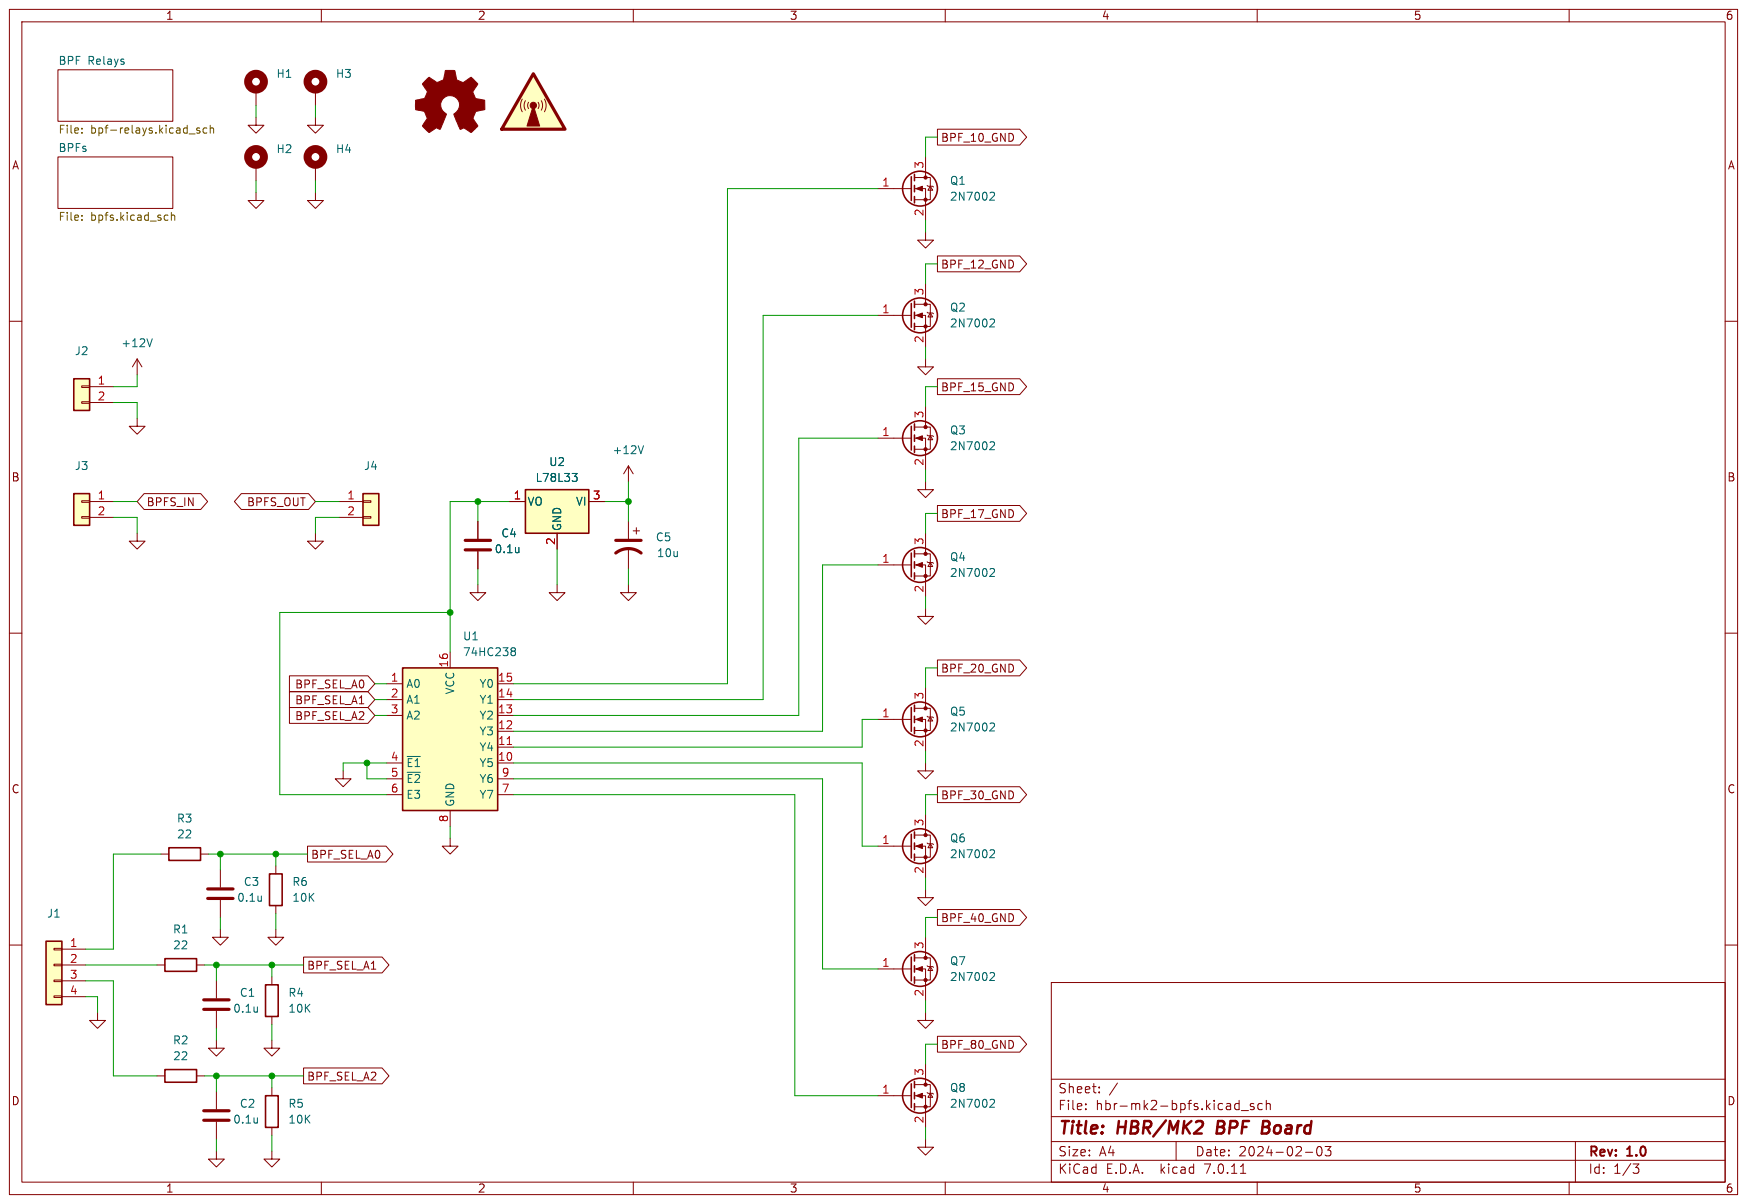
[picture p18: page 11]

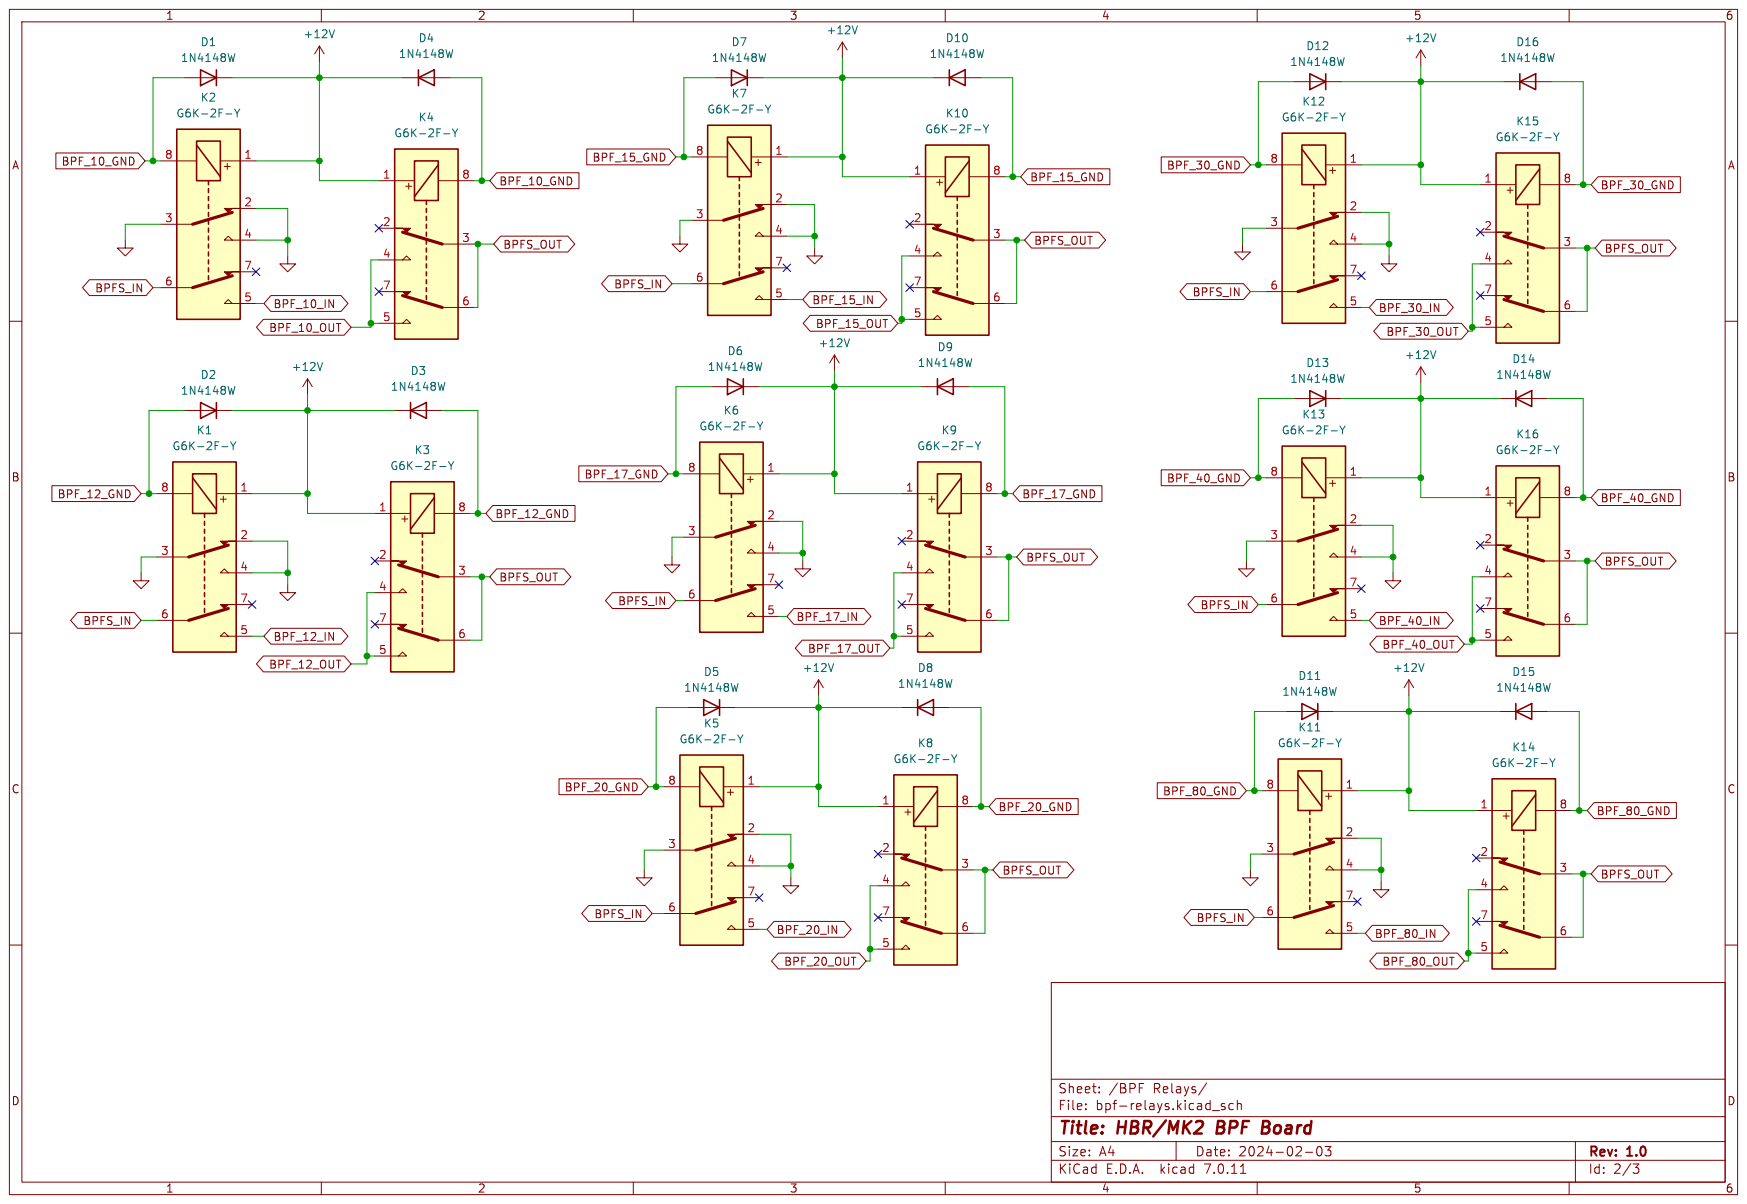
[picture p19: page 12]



RX path, PA bypass



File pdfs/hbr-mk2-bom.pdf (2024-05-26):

Qty Value; Footprint; Capacitor_SMD:CP_Elec_10x10.5; Capacitor_SMD:CP_Elec_4x5.4; Capacitor_SMD:CP_Elec_5x5.4; Capacitor_SMD:CP_Elec_6.3x7.7; Capacitor_SMD:CP_Elec_8x10.5; Capacitor_SMD:C_0805_2012Metric_Pad1.18x1.45mm_HandSolder; Capacitor_THT:CP_Radial_D13.0mm_P5.00mm; Capacitor_THT:CP_Radial_D5.0mm_P2.50mm; Si5351 Module; Connector_PinHeader_2.54mm:PinHeader_1x07_P2.54mm_Vertical; Crystal:Crystal_HC49-U_Vertical; Diode_SMD:D_SMA_Handsoldering; Diode_SMD:D_SOD-123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

My_Library:C_Trim_THD_L7.0mm_W6.5mm_P5.00mm; Package_DIP:DIP-4_W10.16mm; Package_DIP:DIP-4_W7.62mm; Package_SO:SO-16_5.3x10.2mm_P1.27mm; Package_SO:SO-8_5.3x6.2mm_P1.27mm; Package_SO:SOIC-8_5.23x5.23mm_P1.27mm; NE5532 (TL072,MC33078) Package_SO:SOIC-8_5.23x5.23mm_P1.27mm; Package_TO_SOT_SMD:SOT-23; MMBT3904; MMBT3906; Package_TO_SOT_THT:TO-18-3; RD15HVF1; Package_TO_SOT_THT:TO-220-3_Horizontal_TabDown; IRF4905; Package_TO_SOT_THT:TO-220-3_Vertical; TDA2003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


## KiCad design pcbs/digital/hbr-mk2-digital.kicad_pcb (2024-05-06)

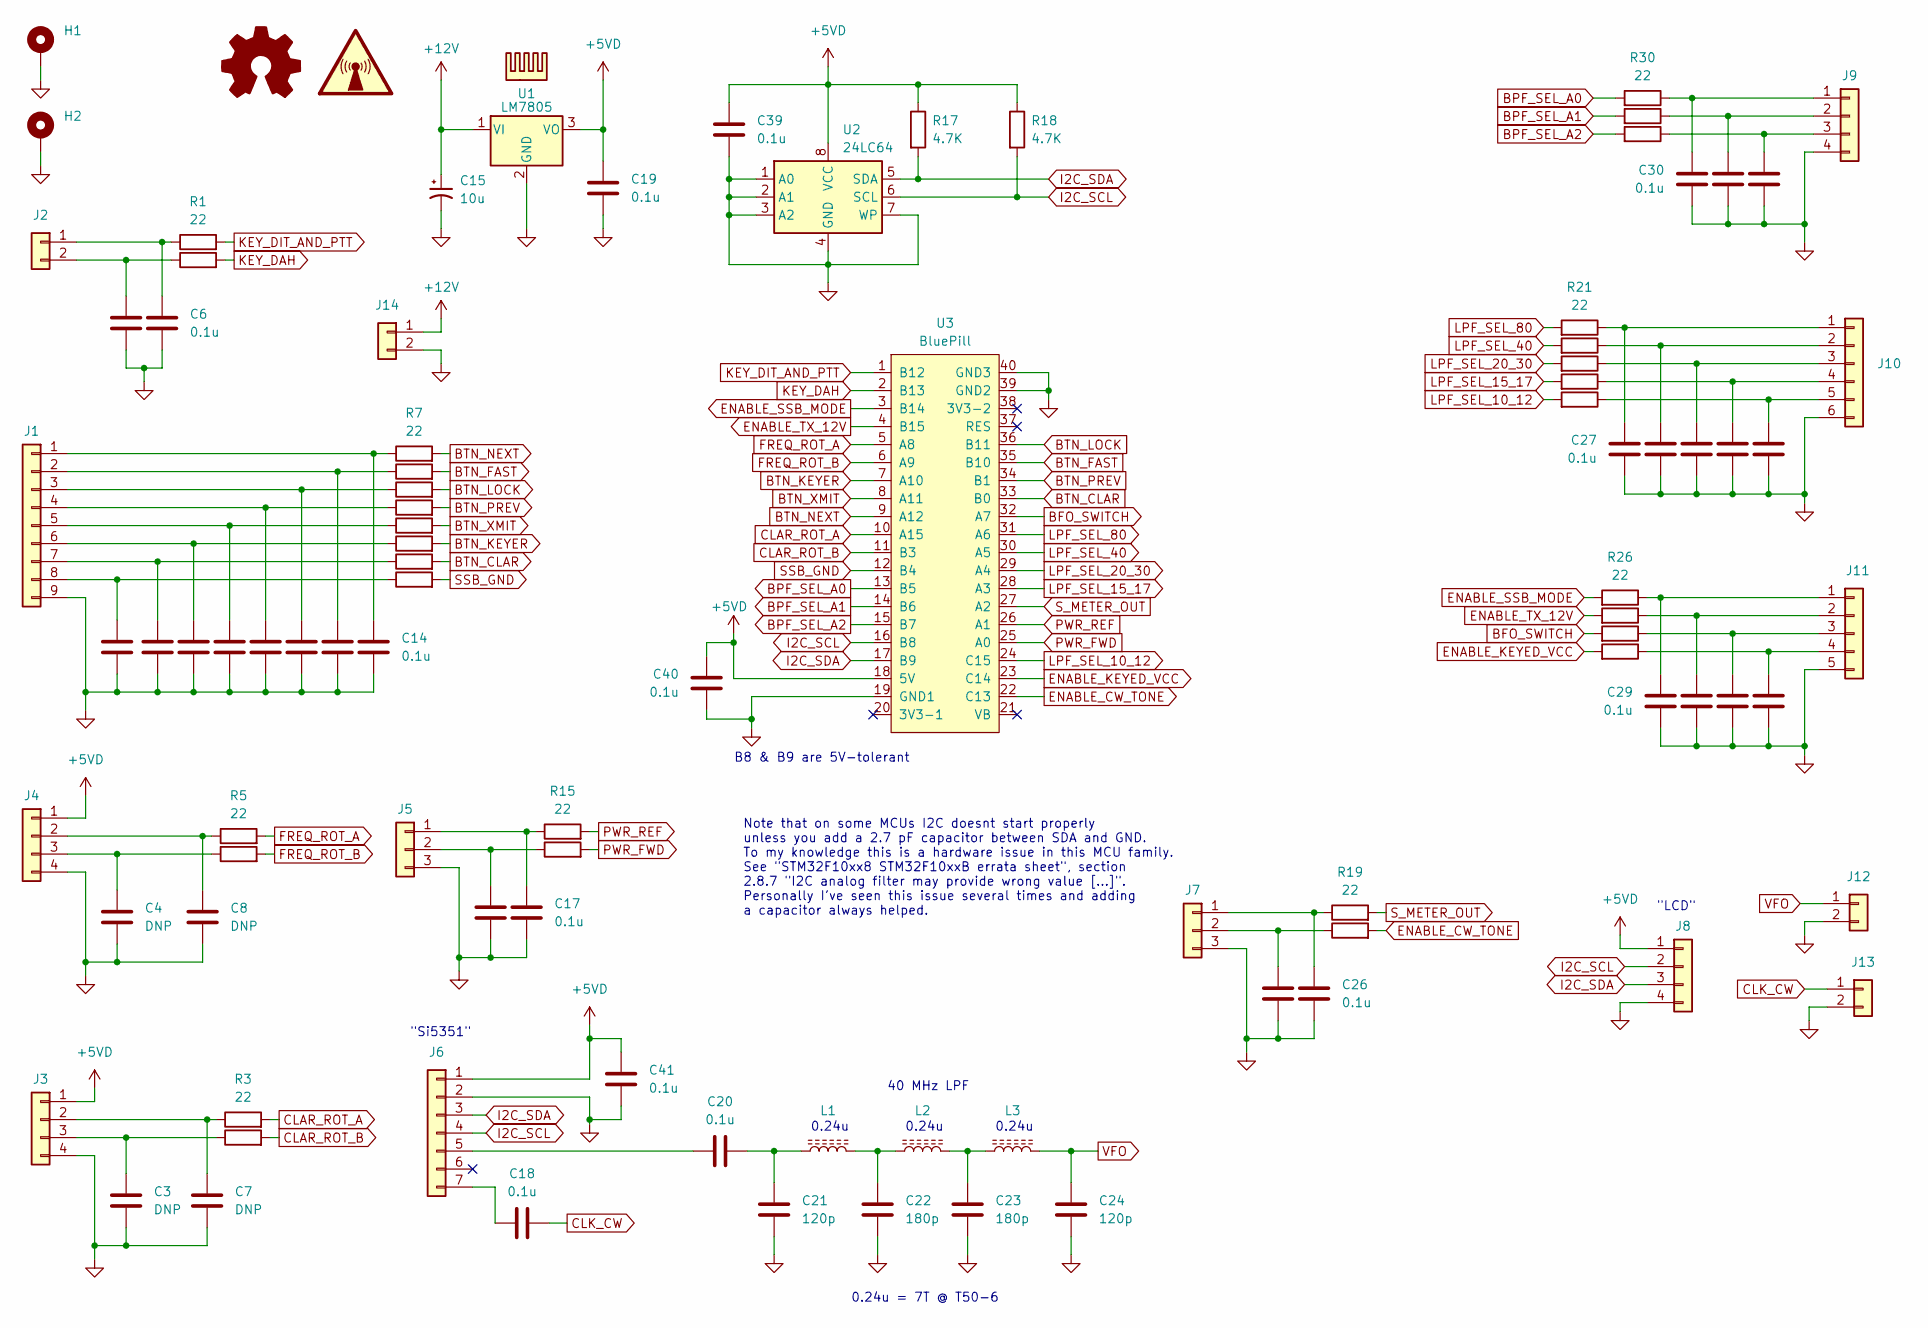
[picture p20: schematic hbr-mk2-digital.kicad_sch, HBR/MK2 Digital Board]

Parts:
C1, C2, C5, C6, C9, C10, C11, C12, C13, C14, C16, C17, C18, C19, C20, C25, C26, C27, C28, C29, C30, C31, C32, C33, C34, C35, C36, C37, C38, C39, C40, C41: 0.1u; C_0805_2012Metric_Pad1.18x1.45mm_HandSolder
C3, C4, C7, C8: DNP; C_0805_2012Metric_Pad1.18x1.45mm_HandSolder
C15: 10u; CP_Radial_D5.0mm_P2.50mm
C21, C24: 120p; C_0805_2012Metric_Pad1.18x1.45mm_HandSolder
C22, C23: 180p; C_0805_2012Metric_Pad1.18x1.45mm_HandSolder
H1, H2: MountingHole_Pad; MountingHole_3.5mm_Pad_Via
HS1: Heatsink
J1: Conn_01x09; PinHeader_1x09_P2.54mm_Vertical
J2, J12, J13, J14: Conn_01x02; PinHeader_1x02_P2.54mm_Vertical
J3, J4, J8, J9: Conn_01x04; PinHeader_1x04_P2.54mm_Vertical
J5, J7: Conn_01x03; PinHeader_1x03_P2.54mm_Vertical
J6: Conn_01x07; PinHeader_1x07_P2.54mm_Vertical
J10: Conn_01x06; PinHeader_1x06_P2.54mm_Vertical
J11: Conn_01x05; PinHeader_1x05_P2.54mm_Vertical
L1, L2, L3: T50-6; L_Toroid_Vertical_L13.0mm_W6.5mm_P5.60mm
R1, R2, R3, R4, R5, R6, R7, R8, R9, R10, R11, R12, R13, R14, R15, R16, R19, R20, R21, R22, R23, R24, R25, R26, R27, R28, R29, R30, R31, R32: 22; R_0805_2012Metric_Pad1.20x1.40mm_HandSolder
R17, R18: 4.7K; R_0805_2012Metric_Pad1.20x1.40mm_HandSolder
SYM1: Logo_Open_Hardware_Small; OSHW-Logo2_9.8x8mm_SilkScreen
SYM2: SYM_Radio_Waves_Large; KiCad-Logo2_5mm_SilkScreen
U1: LM7805; TO-220-3_Vertical
U2: 24LC64; SO-8_5.3x6.2mm_P1.27mm
U3: BluePill

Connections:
+5VD: C19.1, C39.1, C40.1, C41.1, J3.1, J4.1, J6.1, J8.1, R17.1, R18.1, U1.3 (VO), U2.8 (VCC), U3.18 (5V)
+12V: C15.1, J14.1, U1.1 (VI)
BFO_SWITCH: R28.2, U3.32 (A7)
BPF_SEL_A0: R30.2, U3.13 (B5)
BPF_SEL_A1: R31.2, U3.14 (B6)
BPF_SEL_A2: R32.2, U3.15 (B7)
BTN_CLAR: R13.2, U3.33 (B0)
BTN_FAST: R8.2, U3.35 (B10)
BTN_KEYER: R12.2, U3.7 (A10)
BTN_LOCK: R9.2, U3.36 (B11)
BTN_NEXT: R7.2, U3.9 (A12)
BTN_PREV: R10.2, U3.34 (B1)
BTN_XMIT: R11.2, U3.8 (A11)
CLAR_ROT_A: R3.2, U3.10 (A15)
CLAR_ROT_B: R4.2, U3.11 (B3)
CLK_CW: C18.2, J13.1
ENABLE_CW_TONE: R20.2, U3.22 (C13)
ENABLE_KEYED_VCC: R29.2, U3.23 (C14)
ENABLE_SSB_MODE: R26.2, U3.3 (B14)
ENABLE_TX_12V: R27.2, U3.4 (B15)
FREQ_ROT_A: R5.2, U3.5 (A8)
FREQ_ROT_B: R6.2, U3.6 (A9)
GND: C1.2, C2.2, C3.2, C4.2, C5.2, C6.2, C7.2, C8.2, C9.2, C10.2, C11.2, C12.2, C13.2, C14.2, C15.2, C16.2, C17.2, C19.2, C21.2, C22.2, C23.2, C24.2, C25.2, C26.2, C27.2, C28.2, C29.2, C30.2, C31.2, C32.2, C33.2, C34.2, C35.2, C36.2, C37.2, C38.2, C39.2, C40.2, C41.2, H1.1, H2.1, J1.9, J3.4, J4.4, J5.3, J6.2, J7.3, J8.4, J9.4, J10.6, J11.5, J12.2, J13.2, J14.2, U1.2 (GND), U2.1 (A0), U2.2 (A1), U2.3 (A2), U2.4 (GND), U2.7 (WP), U3.19 (GND1), U3.39 (GND2), U3.40 (GND3)
I2C_SCL: J6.4, J8.2, R18.2, U2.6 (SCL), U3.16 (B8)
I2C_SDA: J6.3, J8.3, R17.2, U2.5 (SDA), U3.17 (B9)
KEY_DAH: R2.2, U3.2 (B13)
KEY_DIT_AND_PTT: R1.2, U3.1 (B12)
LPF_SEL_10_12: R25.2, U3.24 (C15)
LPF_SEL_15_17: R24.2, U3.28 (A3)
LPF_SEL_20_30: R23.2, U3.29 (A4)
LPF_SEL_40: R22.2, U3.30 (A5)
LPF_SEL_80: R21.2, U3.31 (A6)
unnamed: C20.2, C21.1, L1.1
unnamed: C22.1, L1.2, L2.1
unnamed: C23.1, L2.2, L3.1
unnamed: C14.1, J1.1, R7.1
unnamed: C13.1, J1.2, R8.1
unnamed: C12.1, J1.3, R9.1
unnamed: C11.1, J1.4, R10.1
unnamed: C10.1, J1.5, R11.1
unnamed: C9.1, J1.6, R12.1
unnamed: C5.1, J1.7, R13.1
unnamed: C1.1, J1.8, R14.1
unnamed: C6.1, J2.1, R1.1
unnamed: C2.1, J2.2, R2.1
unnamed: C7.1, J3.2, R3.1
unnamed: C3.1, J3.3, R4.1
unnamed: C8.1, J4.2, R5.1
unnamed: C4.1, J4.3, R6.1
unnamed: C17.1, J5.1, R15.1
unnamed: C16.1, J5.2, R16.1
unnamed: C20.1, J6.5
unnamed: C18.1, J6.7
unnamed: C26.1, J7.1, R19.1
unnamed: C25.1, J7.2, R20.1
unnamed: C30.1, J9.1, R30.1
unnamed: C33.1, J9.2, R31.1
unnamed: C36.1, J9.3, R32.1
unnamed: C27.1, J10.1, R21.1
unnamed: C28.1, J10.2, R22.1
unnamed: C31.1, J10.3, R23.1
unnamed: C34.1, J10.4, R24.1
unnamed: C37.1, J10.5, R25.1
unnamed: C29.1, J11.1, R26.1
unnamed: C32.1, J11.2, R27.1
unnamed: C35.1, J11.3, R28.1
unnamed: C38.1, J11.4, R29.1
PWR_FWD: R16.2, U3.25 (A0)
PWR_REF: R15.2, U3.26 (A1)
SSB_GND: R14.2, U3.12 (B4)
S_METER_OUT: R19.2, U3.27 (A2)
VFO: C24.1, J12.1, L3.2

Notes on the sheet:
0.24u = 7T @ T50-6
0.24u
40 MHz LPF
"Si5351"
"LCD"
B8 & B9 are 5V-tolerant
Note that on some MCUs I2C doesnt start properly unless you add a 2.7 pF capacitor between SDA and GND. To my knowledge this is a hardware issue in this MCU family. See "STM32F10xx8 STM32F10xxB errata sheet", section 2.8.7 "I2C analog filter may provide wrong value [...]". Personally I've seen this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

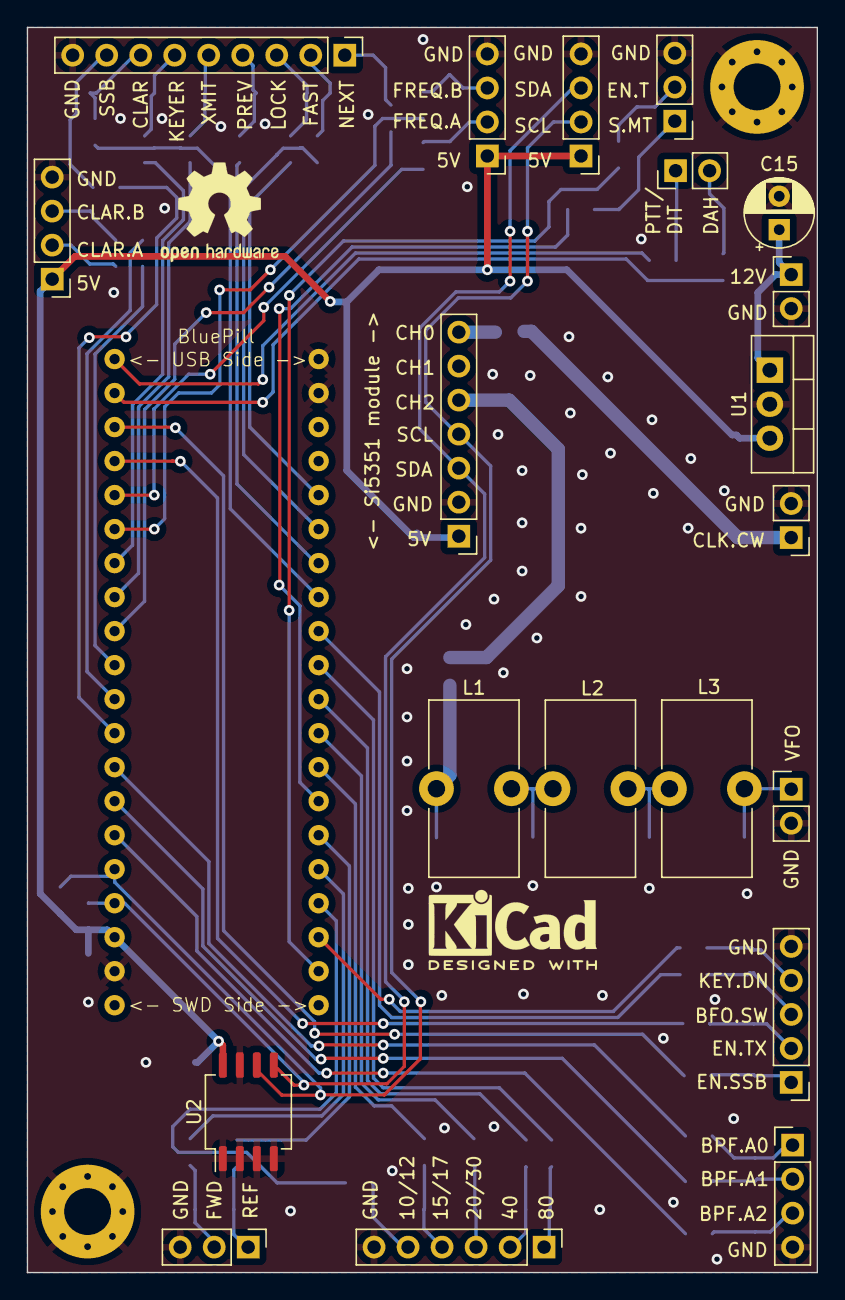
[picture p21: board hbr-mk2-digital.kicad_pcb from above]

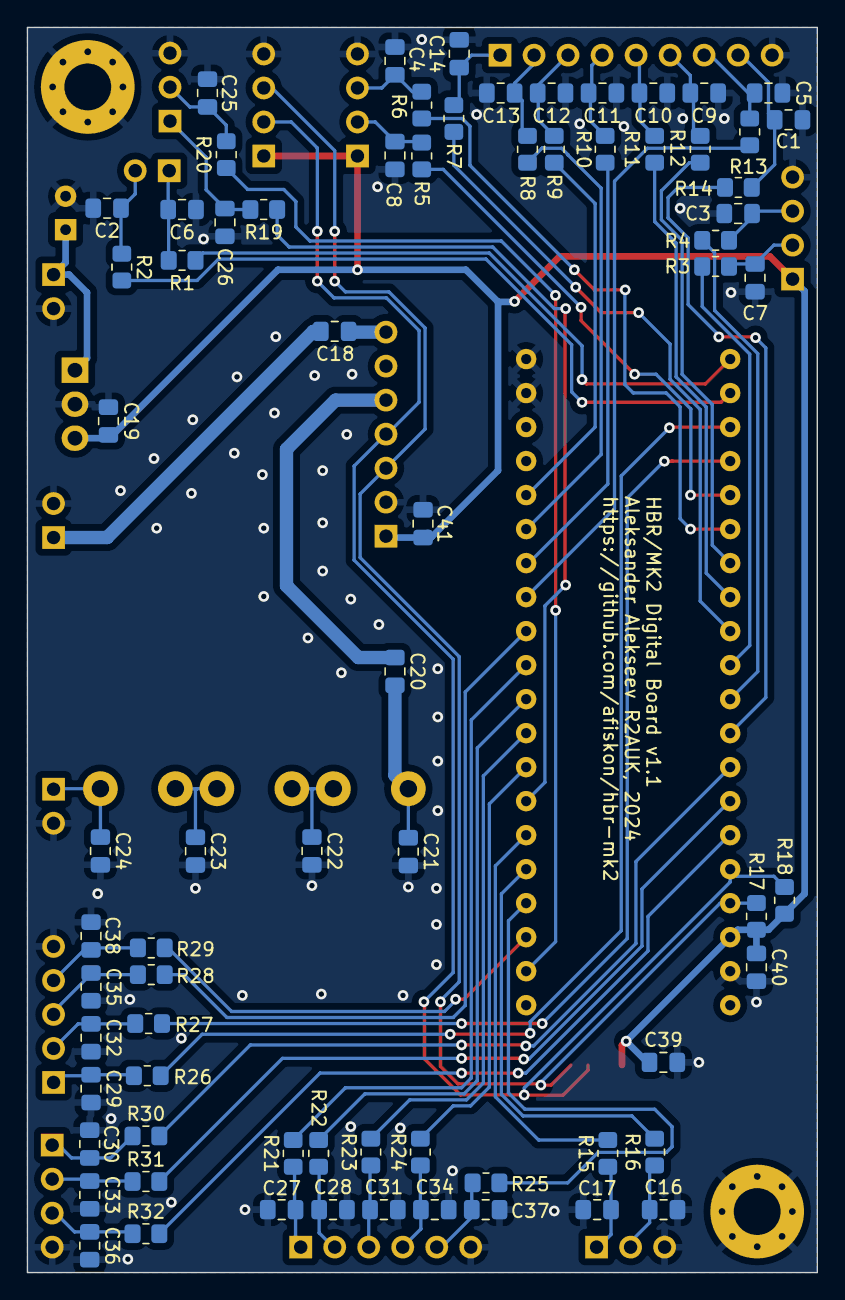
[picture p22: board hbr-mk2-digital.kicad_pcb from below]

Board: 2 copper layers, 59.0 x 93.0 mm, 97 parts (72 on the bottom side), 72 nets.

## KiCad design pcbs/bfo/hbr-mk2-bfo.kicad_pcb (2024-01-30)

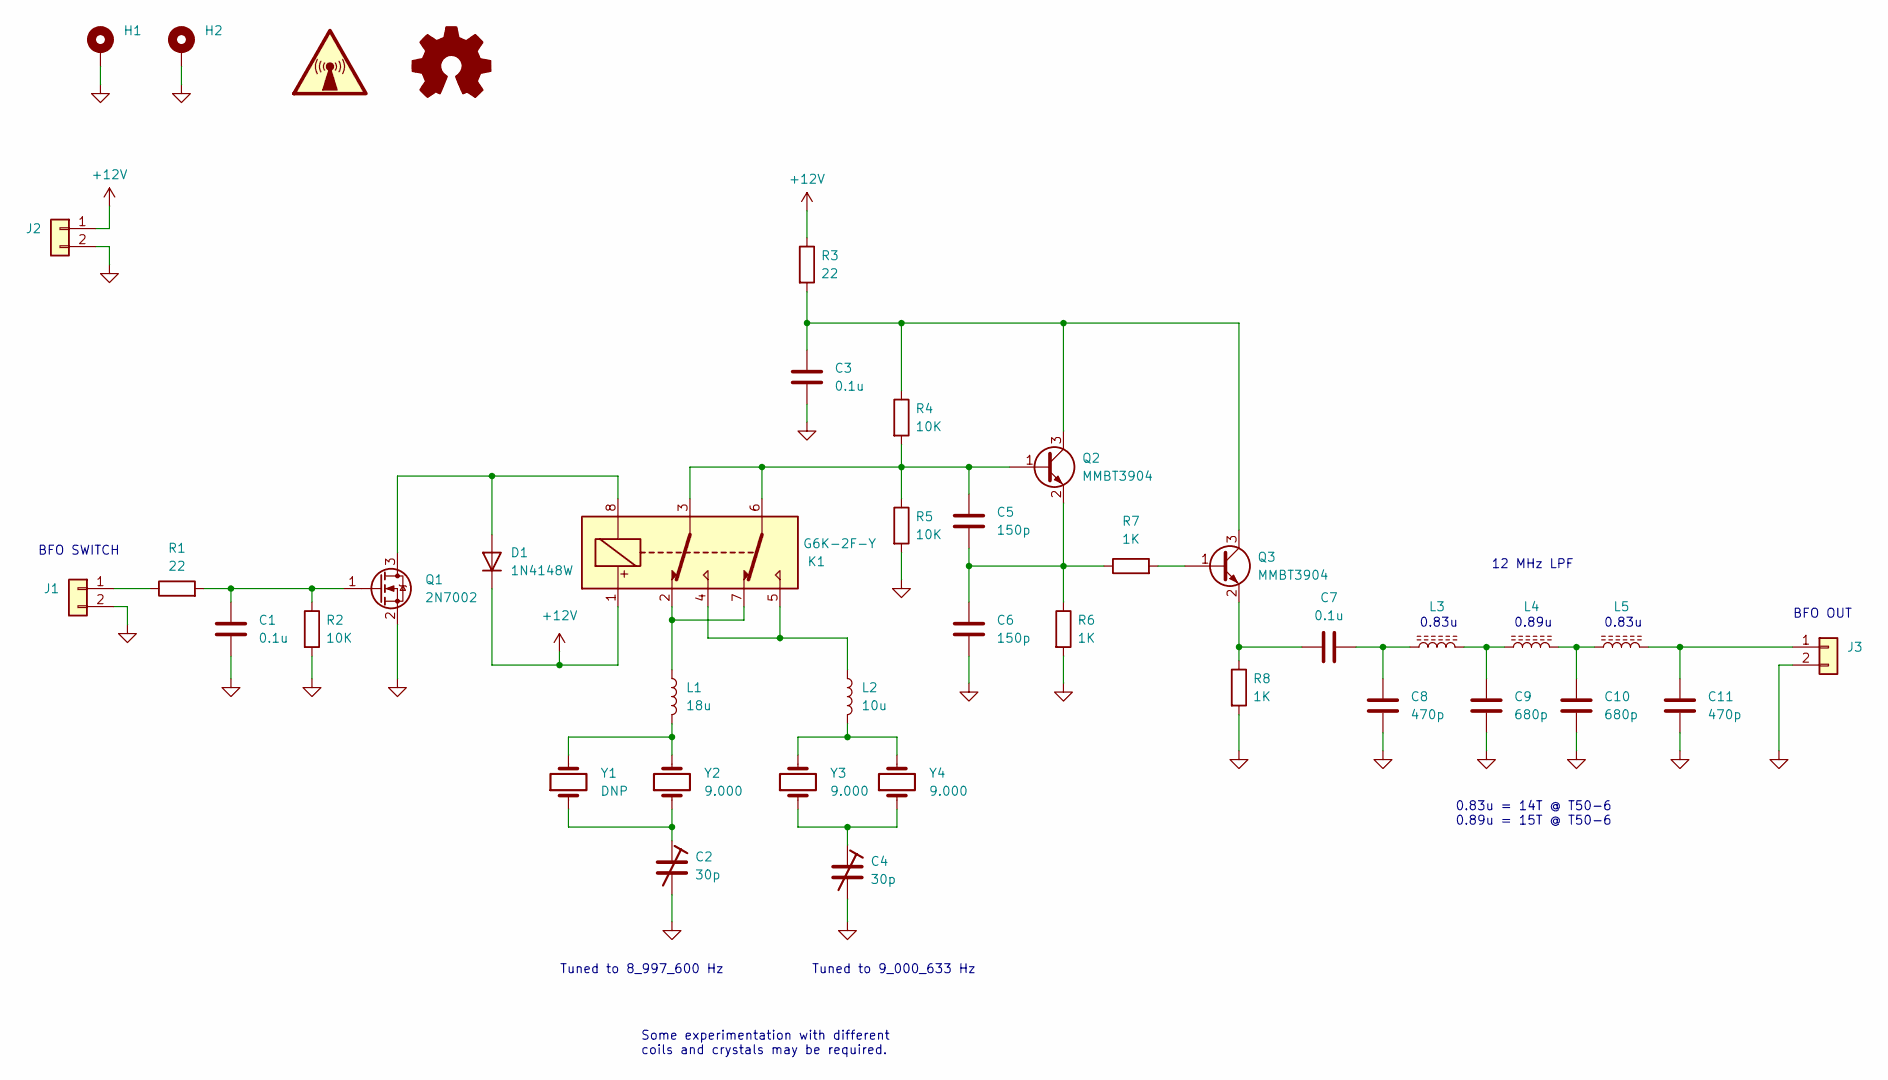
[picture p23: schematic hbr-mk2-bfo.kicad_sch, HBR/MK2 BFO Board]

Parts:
C1, C3, C7: 0.1u; C_0805_2012Metric_Pad1.18x1.45mm_HandSolder
C2, C4: 30p; C_Trim_THD_L7.0mm_W6.5mm_P5.00mm
C5, C6: 150p; C_0805_2012Metric_Pad1.18x1.45mm_HandSolder
C8, C11: 470p; C_0805_2012Metric_Pad1.18x1.45mm_HandSolder
C9, C10: 680p; C_0805_2012Metric_Pad1.18x1.45mm_HandSolder
D1: 1N4148W; D_SOD-123
H1, H2: MountingHole_Pad; MountingHole_3.5mm_Pad_Via
J1, J2, J3: Conn_01x02; PinHeader_1x02_P2.54mm_Vertical
K1: G6K-2F-Y; Relay_DPDT_Omron_G6K-2F-Y
L1: 18u; L_Axial_L7.0mm_D3.3mm_P12.70mm_Horizontal_Fastron_MICC
L2: 10u; L_Axial_L7.0mm_D3.3mm_P12.70mm_Horizontal_Fastron_MICC
L3, L4, L5: T50-6; L_Toroid_Vertical_L13.0mm_W6.5mm_P5.60mm
Q1: 2N7002; SOT-23
Q2, Q3: MMBT3904; SOT-23
R1, R3: 22; R_0805_2012Metric_Pad1.20x1.40mm_HandSolder
R2, R4, R5: 10K; R_0805_2012Metric_Pad1.20x1.40mm_HandSolder
R6, R7, R8: 1K; R_0805_2012Metric_Pad1.20x1.40mm_HandSolder
SYM1: SYM_Radio_Waves_Large; KiCad-Logo2_5mm_SilkScreen
SYM2: Logo_Open_Hardware_Small; OSHW-Logo2_9.8x8mm_SilkScreen
Y1: DNP; Crystal_HC49-U_Vertical
Y2, Y3, Y4: 9.000; Crystal_HC49-U_Vertical

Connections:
+12V: D1.1 (K), J2.1, K1.1, R3.1
GND: C1.2, C2.2, C3.2, C4.2, C6.2, C8.2, C9.2, C10.2, C11.2, H1.1, H2.1, J1.2, J2.2, J3.2, Q1.2 (S), R2.2, R5.2, R6.2, R8.2
unnamed: C2.1, Y1.1, Y2.1
unnamed: C4.1, Y3.1, Y4.1
unnamed: C7.2, C8.1, L3.1
unnamed: C9.1, L3.2, L4.1
unnamed: C10.1, L4.2, L5.1
unnamed: D1.2 (A), K1.8, Q1.3 (D)
unnamed: J1.1, R1.1
unnamed: C11.1, J3.1, L5.2
unnamed: K1.2, K1.7, L1.1
unnamed: K1.4, K1.5, L2.1
unnamed: L1.2, Y1.2, Y2.2
unnamed: L2.2, Y3.2, Y4.2
unnamed: C1.1, Q1.1 (G), R1.2, R2.1
unnamed: C5.1, K1.3, K1.6, Q2.1 (B), R4.2, R5.1
unnamed: C3.1, Q2.3 (C), Q3.3 (C), R3.2, R4.1
unnamed: C5.2, C6.1, Q2.2 (E), R6.1, R7.1
unnamed: Q3.1 (B), R7.2
unnamed: C7.1, Q3.2 (E), R8.1

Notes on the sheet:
BFO SWITCH
Some experimentation with different coils and crystals may be required.
0.83u
Tuned to 9_000_633 Hz
0.89u
Tuned to 8_997_600 Hz
12 MHz LPF
0.83u = 14T @ T50-6 0.89u = 15T @ T50-6
BFO OUT

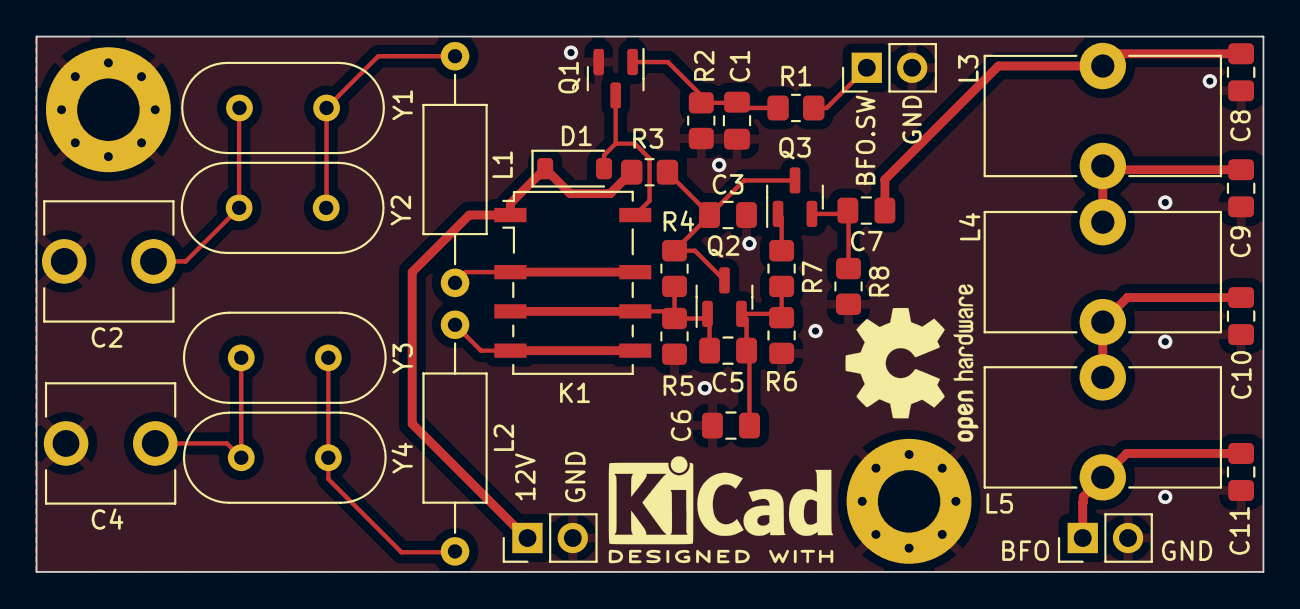
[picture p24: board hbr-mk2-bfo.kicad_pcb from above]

Board: 2 copper layers, 68.8 x 30.0 mm, 40 parts (0 on the bottom side), 20 nets.

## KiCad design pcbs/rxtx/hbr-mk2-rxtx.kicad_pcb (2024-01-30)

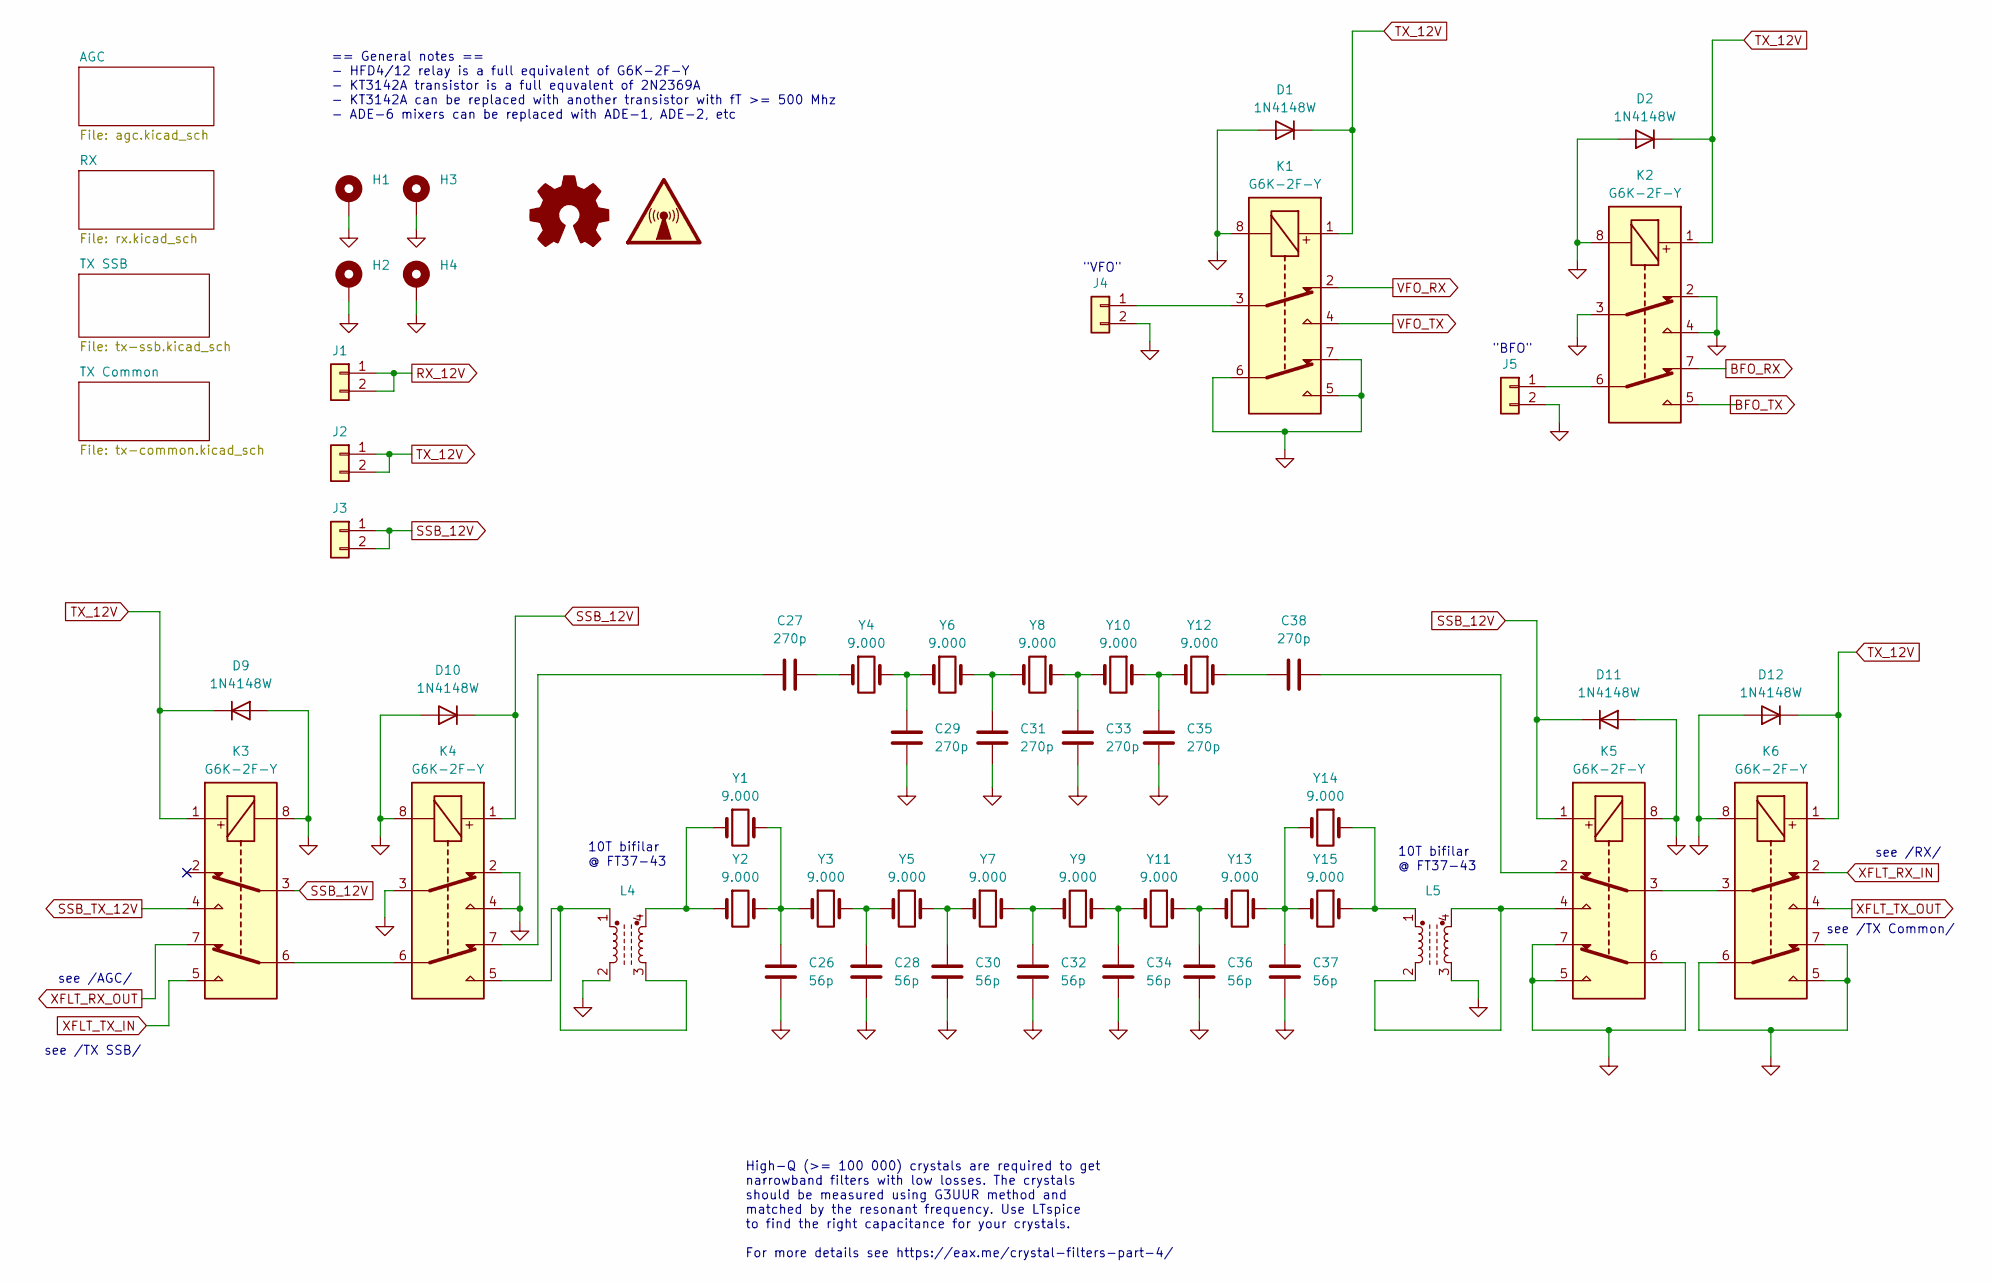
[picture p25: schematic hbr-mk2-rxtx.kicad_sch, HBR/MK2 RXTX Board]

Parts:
C26, C28, C30, C32, C34, C36, C37: 56p; C_0805_2012Metric_Pad1.18x1.45mm_HandSolder
C27, C29, C31, C33, C35, C38: 270p; C_0805_2012Metric_Pad1.18x1.45mm_HandSolder
D1, D2, D9, D10, D11, D12: 1N4148W; D_SOD-123
H1, H2, H3, H4: MountingHole_Pad; MountingHole_3.5mm_Pad_Via
J1, J2, J3, J4, J5: Conn_01x02; PinHeader_1x02_P2.54mm_Vertical
K1, K2, K3, K4, K5, K6: G6K-2F-Y; Relay_DPDT_Omron_G6K-2F-Y
L4, L5: FT37-43; DIP-4_W7.62mm
SYM1: Logo_Open_Hardware_Small; OSHW-Logo2_9.8x8mm_SilkScreen
SYM2: SYM_Radio_Waves_Large; KiCad-Logo2_5mm_SilkScreen
Y1, Y2, Y3, Y4, Y5, Y6, Y7, Y8, Y9, Y10, Y11, Y12, Y13, Y14, Y15: 9.000; Crystal_HC49-U_Vertical

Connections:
BFO_RX: K2.7; also elsewhere on the board
BFO_TX: K2.5; also elsewhere on the board
GND: C26.2, C28.2, C29.2, C30.2, C31.2, C32.2, C33.2, C34.2, C35.2, C36.2, C37.2, D1.2 (A), D2.2 (A), D9.2 (A), D10.2 (A), D11.2 (A), D12.2 (A), H1.1, H2.1, H3.1, H4.1, J4.2, J5.2, K1.5, K1.6, K1.7, K1.8, K2.2, K2.3, K2.4, K2.8, K3.8, K4.2, K4.3, K4.4, K4.8, K5.5, K5.6, K5.7, K5.8, K6.5, K6.6, K6.7, K6.8, L4.2, L5.3; also elsewhere on the board
unnamed: C26.1, Y1.2, Y2.2, Y3.1
unnamed: C27.1, K4.7
unnamed: C27.2, Y4.1
unnamed: C28.1, Y3.2, Y5.1
unnamed: C29.1, Y4.2, Y6.1
unnamed: C30.1, Y5.2, Y7.1
unnamed: C31.1, Y6.2, Y8.2
unnamed: C32.1, Y7.2, Y9.2
unnamed: C33.1, Y8.1, Y10.2
unnamed: C34.1, Y9.1, Y11.2
unnamed: C35.1, Y10.1, Y12.2
unnamed: C36.1, Y11.1, Y13.2
unnamed: C37.1, Y13.1, Y14.2, Y15.2
unnamed: C38.1, Y12.1
unnamed: C38.2, K5.2
unnamed: J4.1, K1.3
unnamed: J5.1, K2.6
unnamed: K3.6, K4.6
unnamed: K4.5, L4.1, L4.3
unnamed: K5.3, K6.3
unnamed: K5.4, L5.2, L5.4
unnamed: L4.4, Y1.1, Y2.1
unnamed: L5.1, Y14.1, Y15.1
RX_12V: J1.1, J1.2; also elsewhere on the board
SSB_12V: D10.1 (K), D11.1 (K), J3.1, J3.2, K3.3, K4.1, K5.1
SSB_TX_12V: K3.4; also elsewhere on the board
TX_12V: D1.1 (K), D2.1 (K), D9.1 (K), D12.1 (K), J2.1, J2.2, K1.1, K2.1, K3.1, K6.1; also elsewhere on the board
VFO_RX: K1.2; also elsewhere on the board
VFO_TX: K1.4; also elsewhere on the board
XFLT_RX_IN: K6.2; also elsewhere on the board
XFLT_RX_OUT: K3.7; also elsewhere on the board
XFLT_TX_IN: K3.5; also elsewhere on the board
XFLT_TX_OUT: K6.4; also elsewhere on the board

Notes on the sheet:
10T bifilar @ FT37-43
High-Q (>= 100 000) crystals are required to get narrowband filters with low losses. The crystals should be measured using G3UUR method and matched by the resonant frequency. Use LTspice to find the right capacitance for your crystals. For more details see https://eax.me/crystal-filters-part-4/
see /TX SSB/
== General notes == - HFD4/12 relay is a full equivalent of G6K-2F-Y - KT3142A transistor is a full equvalent of 2N2369A - KT3142A can be replaced with another transistor with fT >= 500 Mhz - ADE-6 mixers can be replaced with ADE-1, ADE-2, etc
see /RX/
see /AGC/
see /TX Common/
"VFO"
"BFO"

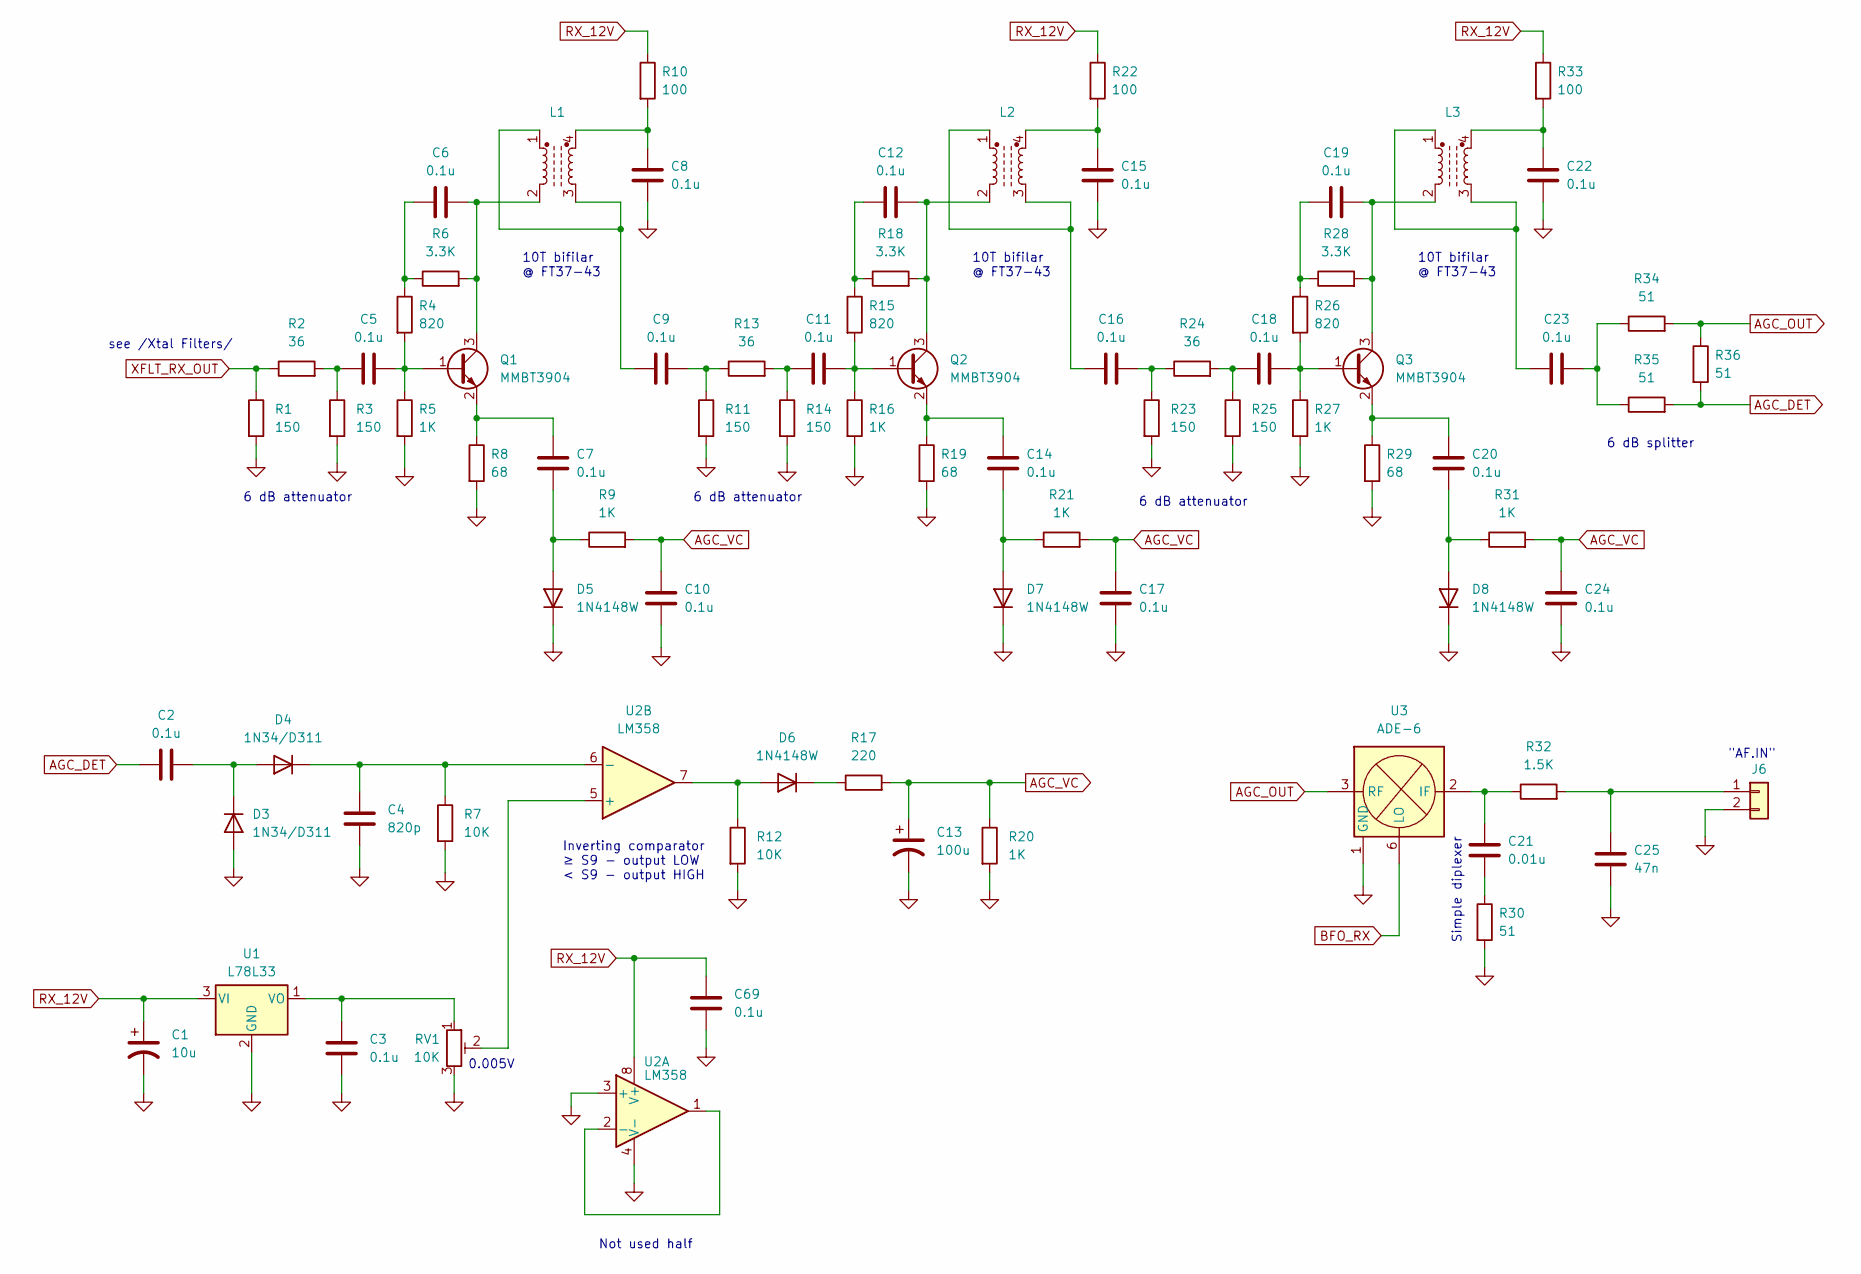
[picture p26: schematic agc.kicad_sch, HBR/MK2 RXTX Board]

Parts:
C1: 10u; CP_Elec_4x5.4
C2, C3, C5, C6, C7, C8, C9, C10, C11, C12, C14, C15, C16, C17, C18, C19, C20, C22, C23, C24, C69: 0.1u; C_0805_2012Metric_Pad1.18x1.45mm_HandSolder
C4: 820p; C_0805_2012Metric_Pad1.18x1.45mm_HandSolder
C13: 100u; CP_Elec_6.3x7.7
C21: 0.01u; C_0805_2012Metric_Pad1.18x1.45mm_HandSolder
C25: 47n; C_0805_2012Metric_Pad1.18x1.45mm_HandSolder
D3, D4: 1N34/D311; D_DO-34_SOD68_P2.54mm_Vertical_AnodeUp
D5, D6, D7, D8: 1N4148W; D_SOD-123
J6: Conn_01x02; PinHeader_1x02_P2.54mm_Vertical
L1, L2, L3: FT37-43; DIP-4_W7.62mm
Q1, Q2, Q3: MMBT3904; SOT-23
R1, R3, R11, R14, R23, R25: 150; R_0805_2012Metric_Pad1.20x1.40mm_HandSolder
R2, R13, R24: 36; R_0805_2012Metric_Pad1.20x1.40mm_HandSolder
R4, R15, R26: 820; R_0805_2012Metric_Pad1.20x1.40mm_HandSolder
R5, R9, R16, R20, R21, R27, R31: 1K; R_0805_2012Metric_Pad1.20x1.40mm_HandSolder
R6, R18, R28: 3.3K; R_0805_2012Metric_Pad1.20x1.40mm_HandSolder
R7, R12: 10K; R_0805_2012Metric_Pad1.20x1.40mm_HandSolder
R8, R19, R29: 68; R_0805_2012Metric_Pad1.20x1.40mm_HandSolder
R10, R22, R33: 100; R_0805_2012Metric_Pad1.20x1.40mm_HandSolder
R17: 220; R_0805_2012Metric_Pad1.20x1.40mm_HandSolder
R30, R34, R35, R36: 51; R_0805_2012Metric_Pad1.20x1.40mm_HandSolder
R32: 1.5K; R_0805_2012Metric_Pad1.20x1.40mm_HandSolder
RV1: 10K; Potentiometer_Bourns_3296W_Vertical
U1: L78L33; TO-92_HandSolder
U2: LM358; SOIC-8_5.23x5.23mm_P1.27mm
U3: ADE-6; Mini-Circuits_CD542_LandPatternPL-052

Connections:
AGC_DET: C2.1, R35.2, R36.2
AGC_OUT: R34.2, R36.1, U3.3 (RF)
AGC_VC: C10.2, C13.1, C17.2, C24.2, R9.2, R17.2, R20.1, R21.2, R31.2
BFO_RX: U3.6 (LO); also elsewhere on the board
GND: C1.2, C3.1, C4.1, C8.1, C10.1, C13.2, C15.1, C17.1, C22.1, C24.1, C25.1, C69.1, D3.2 (A), D5.1 (K), D7.1 (K), D8.1 (K), J6.2, R1.2, R3.2, R5.2, R7.2, R8.2, R11.2, R12.2, R14.2, R16.2, R19.2, R20.2, R23.2, R25.2, R27.2, R29.2, R30.2, RV1.3, U1.2 (GND), U2.3 (+), U2.4 (V-), U3.1 (GND), U3.4 (GND), U3.5 (GND); also elsewhere on the board
unnamed: C5.1, R2.2, R3.1
unnamed: C6.1, R4.1, R6.1
unnamed: C8.2, L1.4, R10.2
unnamed: C9.1, L1.1, L1.3
unnamed: C9.2, R11.1, R13.1
unnamed: C11.1, R13.2, R14.1
unnamed: C12.1, R15.1, R18.1
unnamed: C15.2, L2.4, R22.2
unnamed: C16.1, L2.1, L2.3
unnamed: C16.2, R23.1, R24.1
unnamed: C18.1, R24.2, R25.1
unnamed: C19.1, R26.1, R28.1
unnamed: C21.1, R30.1
unnamed: C22.2, L3.4, R33.2
unnamed: C23.1, L3.1, L3.3
unnamed: C23.2, R34.1, R35.1
unnamed: C2.2, D3.1 (K), D4.2 (A)
unnamed: C4.2, D4.1 (K), R7.1, U2.6 (-)
unnamed: C7.1, D5.2 (A), R9.1
unnamed: D6.2 (A), R12.1, U2.7
unnamed: D6.1 (K), R17.1
unnamed: C14.1, D7.2 (A), R21.1
unnamed: C20.1, D8.2 (A), R31.1
unnamed: C25.2, J6.1, R32.2
unnamed: C5.2, Q1.1 (B), R4.2, R5.1
unnamed: C6.2, L1.2, Q1.3 (C), R6.2
unnamed: C7.2, Q1.2 (E), R8.1
unnamed: C11.2, Q2.1 (B), R15.2, R16.1
unnamed: C12.2, L2.2, Q2.3 (C), R18.2
unnamed: C14.2, Q2.2 (E), R19.1
unnamed: C18.2, Q3.1 (B), R26.2, R27.1
unnamed: C19.2, L3.2, Q3.3 (C), R28.2
unnamed: C20.2, Q3.2 (E), R29.1
unnamed: C3.2, RV1.1, U1.1 (VO)
unnamed: U2.1, U2.2 (-)
unnamed: RV1.2, U2.5 (+)
unnamed: C21.2, R32.1, U3.2 (IF)
RX_12V: C1.1, C69.2, R10.1, R22.1, R33.1, U1.3 (VI), U2.8 (V+); also elsewhere on the board
XFLT_RX_OUT: R1.1, R2.1; also elsewhere on the board

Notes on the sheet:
Inverting comparator ≥ S9 - output LOW < S9 - output HIGH
6 dB attenuator
0.005V
see /Xtal Filters/
6 dB splitter
Simple diplexer
10T bifilar @ FT37-43
Not used half
"AF.IN"

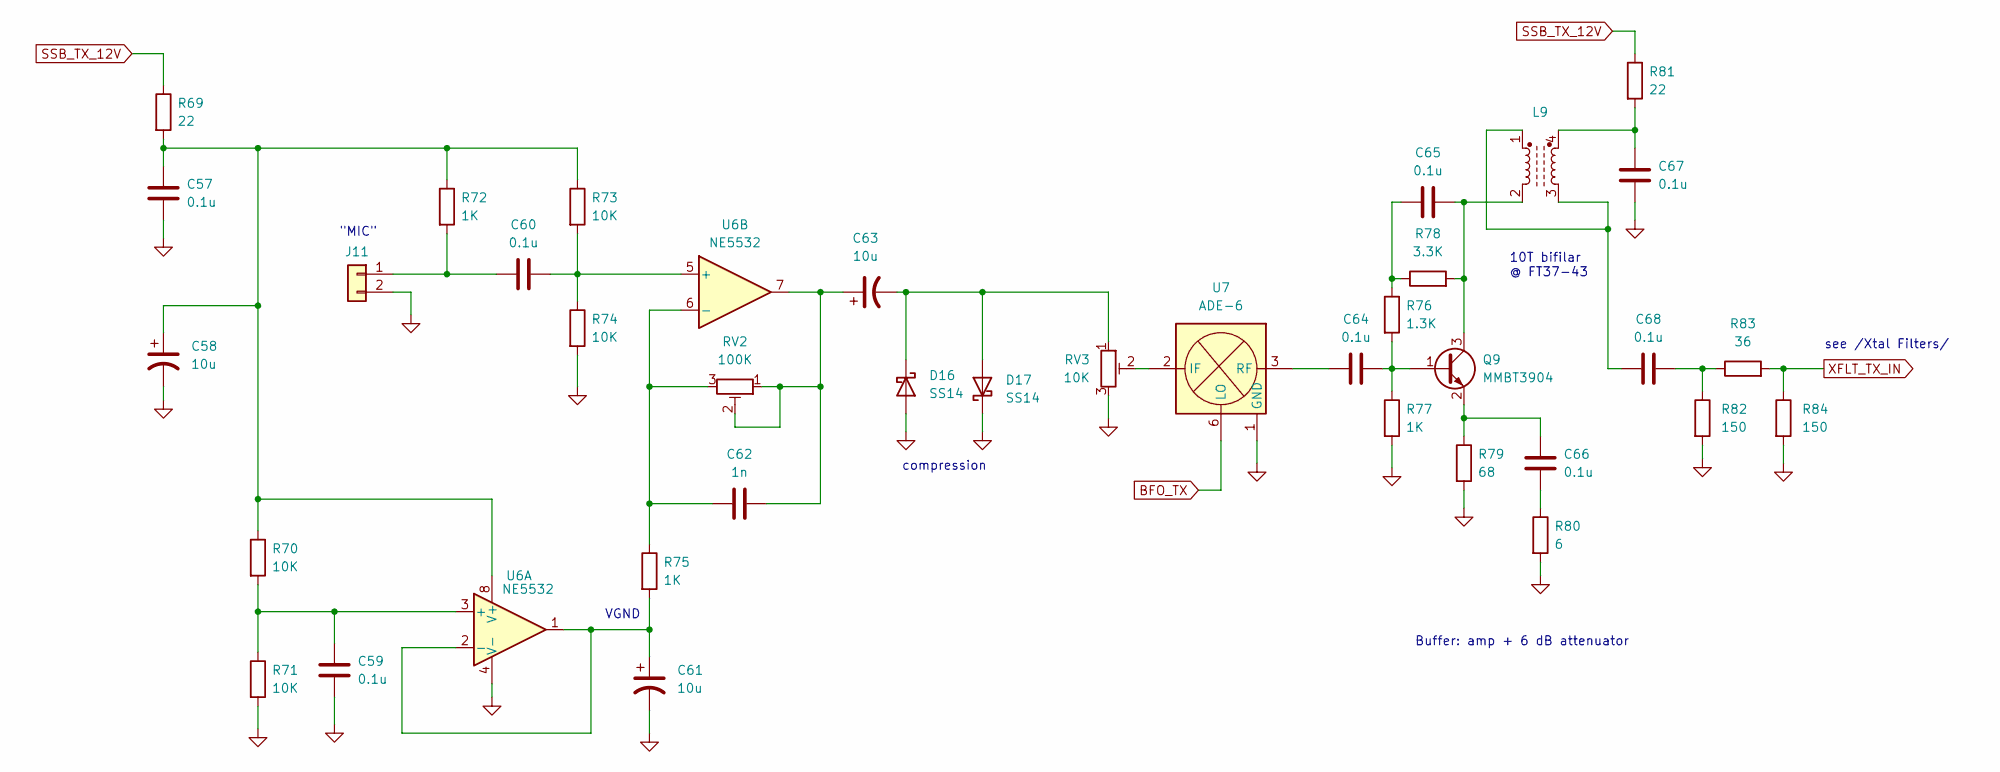
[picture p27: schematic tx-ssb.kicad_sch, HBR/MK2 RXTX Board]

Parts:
C57, C59, C60, C64, C65, C66, C67, C68: 0.1u; C_0805_2012Metric_Pad1.18x1.45mm_HandSolder
C58, C61, C63: 10u; CP_Elec_4x5.4
C62: 1n; C_0805_2012Metric_Pad1.18x1.45mm_HandSolder
D16, D17: SS14; D_SMA_Handsoldering
J11: Conn_01x02; PinHeader_1x02_P2.54mm_Vertical
L9: FT37-43; DIP-4_W7.62mm
Q9: MMBT3904; SOT-23
R69, R81: 22; R_0805_2012Metric_Pad1.20x1.40mm_HandSolder
R70, R71, R73, R74: 10K; R_0805_2012Metric_Pad1.20x1.40mm_HandSolder
R72, R75, R77: 1K; R_0805_2012Metric_Pad1.20x1.40mm_HandSolder
R76: 1.3K; R_0805_2012Metric_Pad1.20x1.40mm_HandSolder
R78: 3.3K; R_0805_2012Metric_Pad1.20x1.40mm_HandSolder
R79: 68; R_0805_2012Metric_Pad1.20x1.40mm_HandSolder
R80: 6; R_0805_2012Metric_Pad1.20x1.40mm_HandSolder
R82, R84: 150; R_0805_2012Metric_Pad1.20x1.40mm_HandSolder
R83: 36; R_0805_2012Metric_Pad1.20x1.40mm_HandSolder
RV2: 100K; Potentiometer_Bourns_3296W_Vertical
RV3: 10K; Potentiometer_Bourns_3296W_Vertical
U6: NE5532; SOIC-8_5.23x5.23mm_P1.27mm
U7: ADE-6; Mini-Circuits_CD542_LandPatternPL-052

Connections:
BFO_TX: U7.6 (LO); also elsewhere on the board
GND: C57.2, C58.2, C59.2, C61.2, C67.1, D16.2 (A), D17.1 (K), J11.2, R71.2, R74.2, R77.2, R79.2, R80.2, R82.2, R84.2, RV3.3, U6.4 (V-), U7.1 (GND), U7.4 (GND), U7.5 (GND); also elsewhere on the board
unnamed: C62.2, C63.1, RV2.1, RV2.2, U6.7
unnamed: C65.1, R76.1, R78.1
unnamed: C66.1, R80.1
unnamed: C67.2, L9.4, R81.2
unnamed: C68.1, L9.1, L9.3
unnamed: C68.2, R82.1, R83.1
unnamed: C63.2, D16.1 (K), D17.2 (A), RV3.1
unnamed: C60.1, J11.1, R72.2
unnamed: C64.2, Q9.1 (B), R76.2, R77.1
unnamed: C65.2, L9.2, Q9.3 (C), R78.2
unnamed: C66.2, Q9.2 (E), R79.1
unnamed: C59.1, R70.2, R71.1, U6.3 (+)
unnamed: C61.1, R75.2, U6.1, U6.2 (-)
unnamed: C60.2, R73.2, R74.1, U6.5 (+)
unnamed: C62.1, R75.1, RV2.3, U6.6 (-)
unnamed: C57.1, C58.1, R69.2, R70.1, R72.1, R73.1, U6.8 (V+)
unnamed: RV3.2, U7.2 (IF)
unnamed: C64.1, U7.3 (RF)
SSB_TX_12V: R69.1, R81.1; also elsewhere on the board
XFLT_TX_IN: R83.2, R84.1; also elsewhere on the board

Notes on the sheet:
see /Xtal Filters/
10T bifilar @ FT37-43
Buffer: amp + 6 dB attenuator
VGND
"MIC"
compression

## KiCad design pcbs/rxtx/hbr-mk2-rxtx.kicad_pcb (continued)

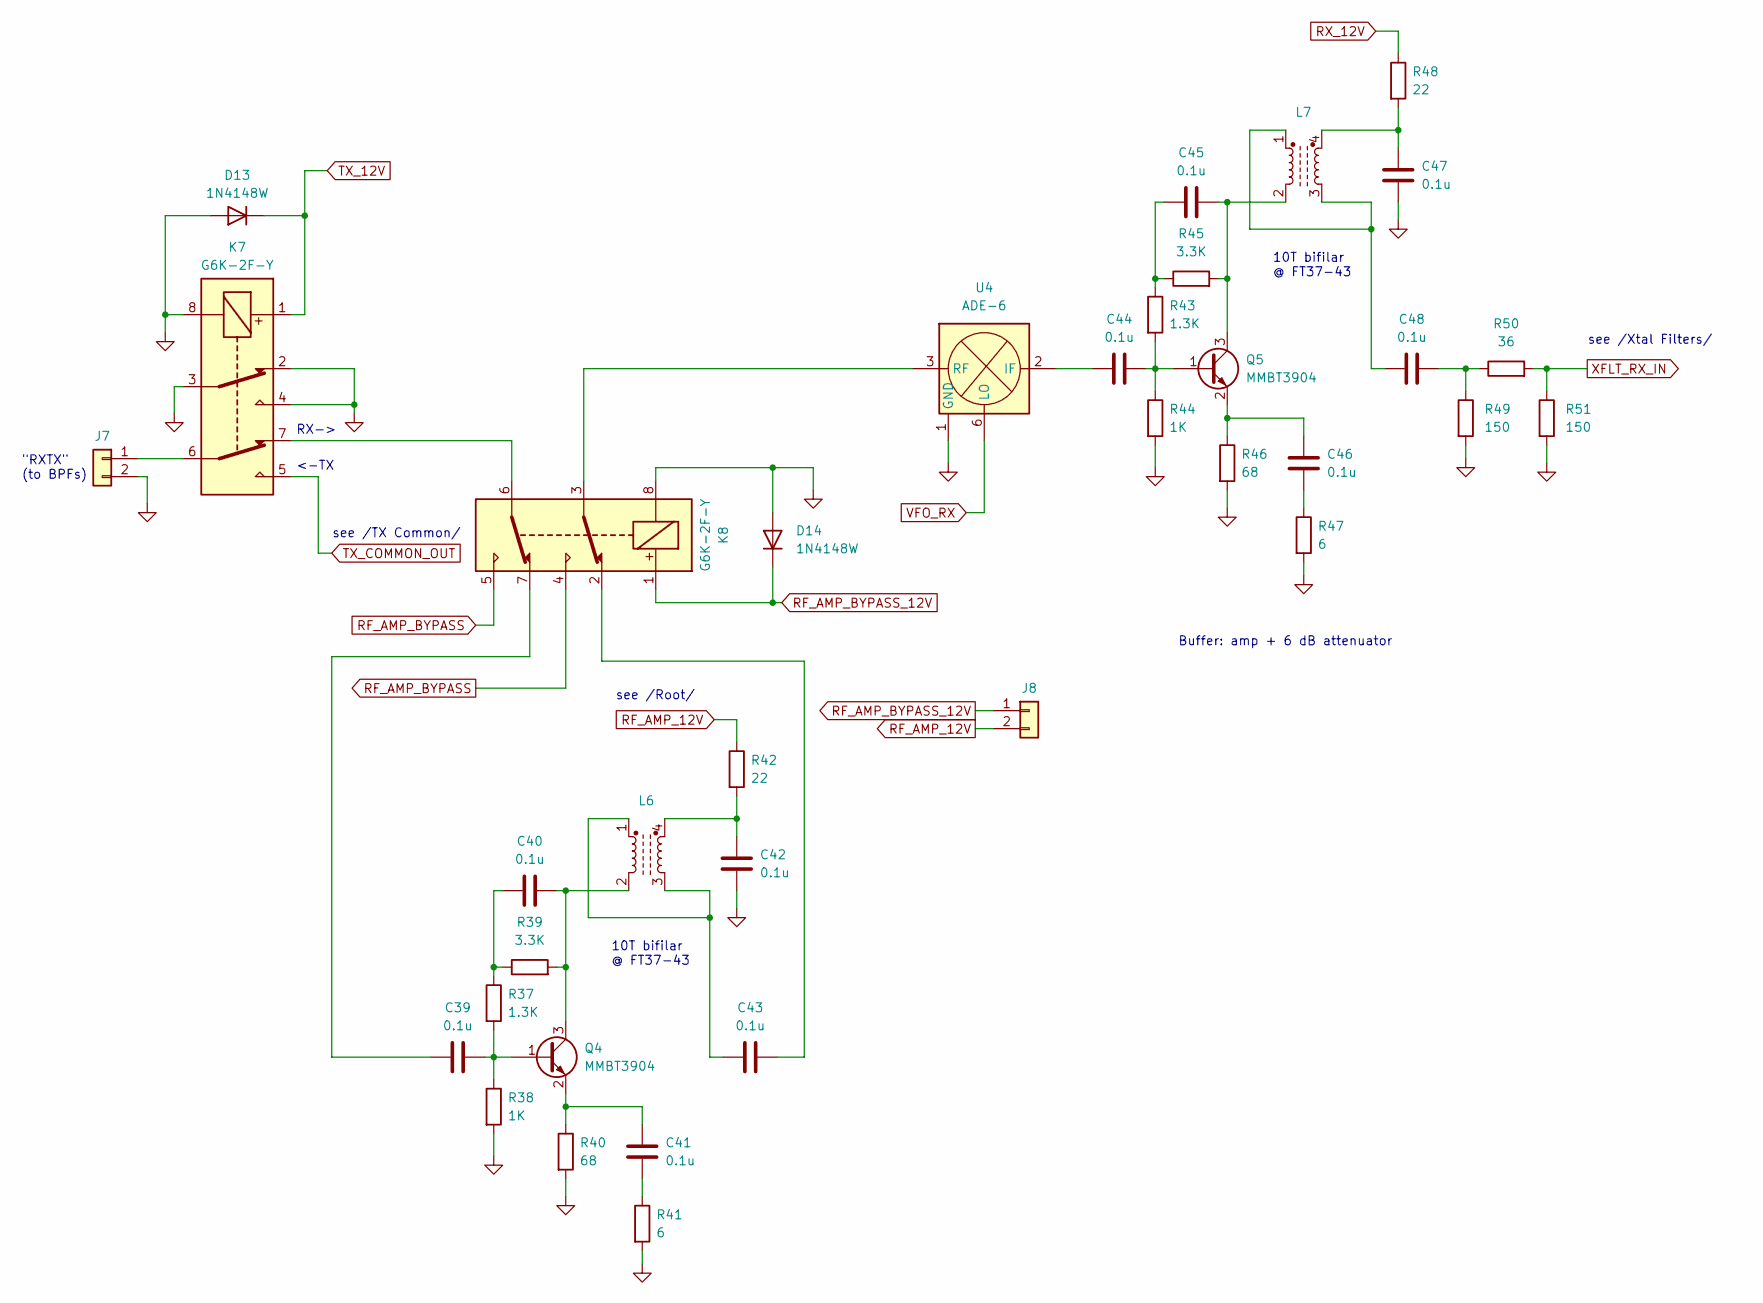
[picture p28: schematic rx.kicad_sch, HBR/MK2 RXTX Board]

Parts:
C39, C40, C41, C42, C43, C44, C45, C46, C47, C48: 0.1u; C_0805_2012Metric_Pad1.18x1.45mm_HandSolder
D13, D14: 1N4148W; D_SOD-123
J7, J8: Conn_01x02; PinHeader_1x02_P2.54mm_Vertical
K7, K8: G6K-2F-Y; Relay_DPDT_Omron_G6K-2F-Y
L6, L7: FT37-43; DIP-4_W7.62mm
Q4, Q5: MMBT3904; SOT-23
R37, R43: 1.3K; R_0805_2012Metric_Pad1.20x1.40mm_HandSolder
R38, R44: 1K; R_0805_2012Metric_Pad1.20x1.40mm_HandSolder
R39, R45: 3.3K; R_0805_2012Metric_Pad1.20x1.40mm_HandSolder
R40, R46: 68; R_0805_2012Metric_Pad1.20x1.40mm_HandSolder
R41, R47: 6; R_0805_2012Metric_Pad1.20x1.40mm_HandSolder
R42, R48: 22; R_0805_2012Metric_Pad1.20x1.40mm_HandSolder
R49, R51: 150; R_0805_2012Metric_Pad1.20x1.40mm_HandSolder
R50: 36; R_0805_2012Metric_Pad1.20x1.40mm_HandSolder
U4: ADE-6; Mini-Circuits_CD542_LandPatternPL-052

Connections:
GND: C42.1, C47.1, D13.2 (A), D14.2 (A), J7.2, K7.2, K7.3, K7.4, K7.8, K8.8, R38.2, R40.2, R41.2, R44.2, R46.2, R47.2, R49.2, R51.2, U4.1 (GND), U4.4 (GND), U4.5 (GND); also elsewhere on the board
unnamed: C39.1, K8.7
unnamed: C40.1, R37.1, R39.1
unnamed: C41.1, R41.1
unnamed: C42.2, L6.4, R42.2
unnamed: C43.1, L6.1, L6.3
unnamed: C43.2, K8.2
unnamed: C45.1, R43.1, R45.1
unnamed: C46.1, R47.1
unnamed: C47.2, L7.4, R48.2
unnamed: C48.1, L7.1, L7.3
unnamed: C48.2, R49.1, R50.1
unnamed: J7.1, K7.6
unnamed: K7.7, K8.6
unnamed: C39.2, Q4.1 (B), R37.2, R38.1
unnamed: C40.2, L6.2, Q4.3 (C), R39.2
unnamed: C41.2, Q4.2 (E), R40.1
unnamed: C44.2, Q5.1 (B), R43.2, R44.1
unnamed: C45.2, L7.2, Q5.3 (C), R45.2
unnamed: C46.2, Q5.2 (E), R46.1
unnamed: C44.1, U4.2 (IF)
unnamed: K8.3, U4.3 (RF)
RF_AMP_12V: J8.2, R42.1
RF_AMP_BYPASS: K8.4, K8.5
RF_AMP_BYPASS_12V: D14.1 (K), J8.1, K8.1
RX_12V: R48.1; also elsewhere on the board
TX_12V: D13.1 (K), K7.1; also elsewhere on the board
TX_COMMON_OUT: K7.5; also elsewhere on the board
VFO_RX: U4.6 (LO); also elsewhere on the board
XFLT_RX_IN: R50.2, R51.1; also elsewhere on the board

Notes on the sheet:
see /Xtal Filters/
10T bifilar @ FT37-43
"RXTX" (to BPFs)
RX->
see /TX Common/
see /Root/
Buffer: amp + 6 dB attenuator
<-TX

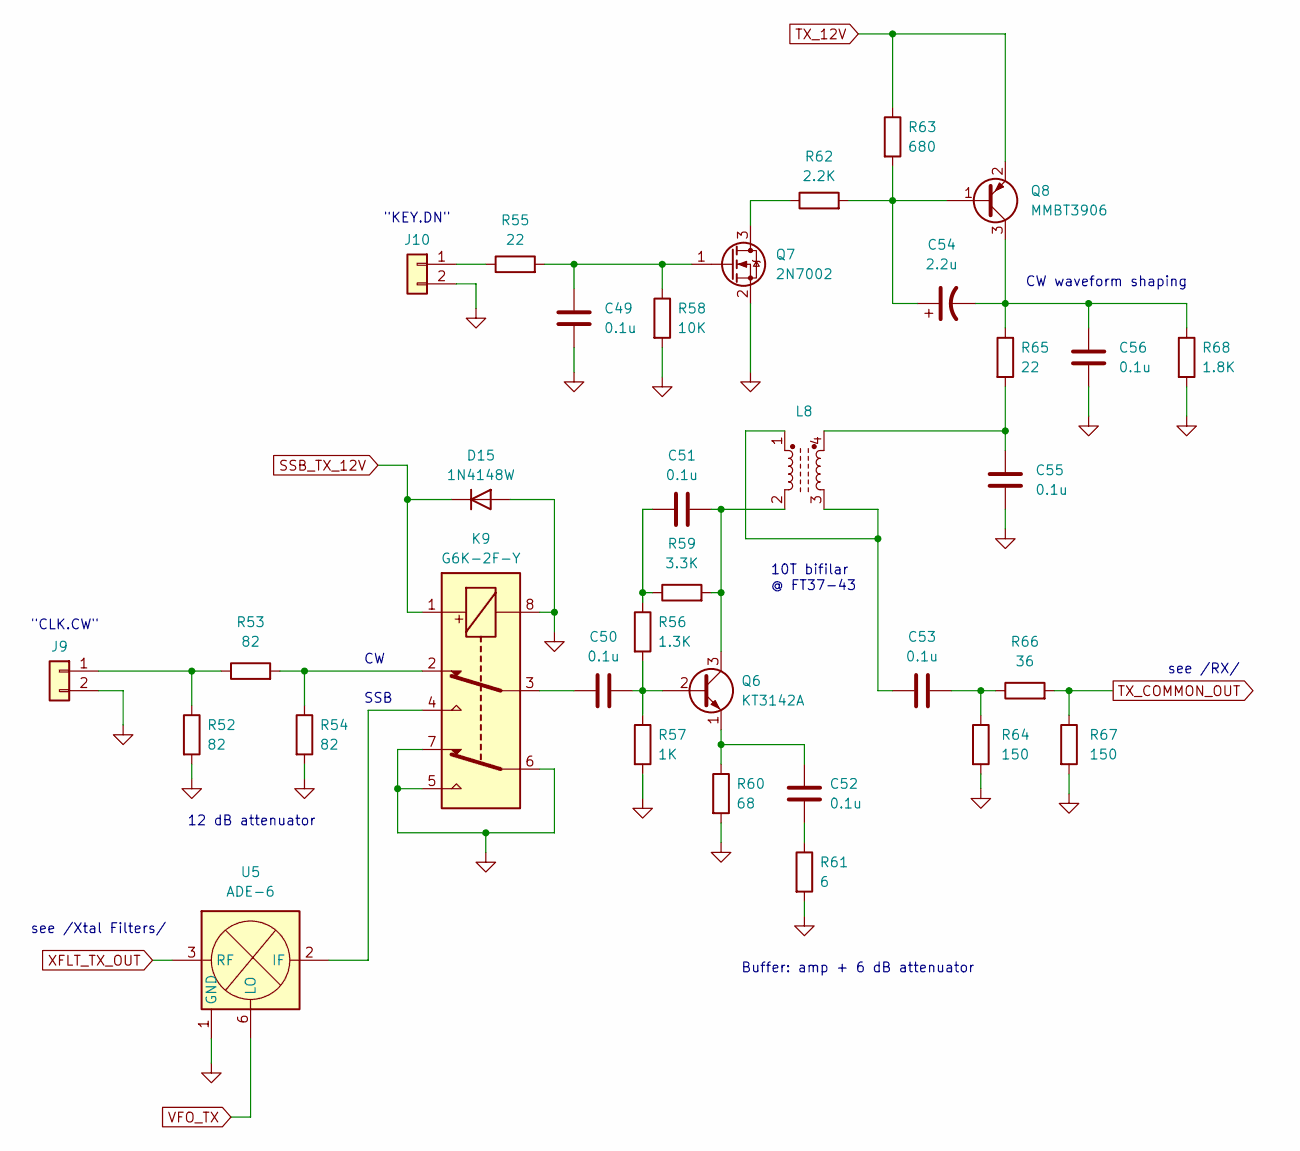
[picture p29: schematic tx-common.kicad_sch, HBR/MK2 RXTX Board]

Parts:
C49, C50, C51, C52, C53, C55, C56: 0.1u; C_0805_2012Metric_Pad1.18x1.45mm_HandSolder
C54: 2.2u; CP_Elec_4x5.4
D15: 1N4148W; D_SOD-123
J9, J10: Conn_01x02; PinHeader_1x02_P2.54mm_Vertical
K9: G6K-2F-Y; Relay_DPDT_Omron_G6K-2F-Y
L8: FT37-43; DIP-4_W7.62mm
Q6: KT3142A; TO-18-3
Q7: 2N7002; SOT-23
Q8: MMBT3906; SOT-23
R52, R53, R54: 82; R_0805_2012Metric_Pad1.20x1.40mm_HandSolder
R55, R65: 22; R_0805_2012Metric_Pad1.20x1.40mm_HandSolder
R56: 1.3K; R_0805_2012Metric_Pad1.20x1.40mm_HandSolder
R57: 1K; R_0805_2012Metric_Pad1.20x1.40mm_HandSolder
R58: 10K; R_0805_2012Metric_Pad1.20x1.40mm_HandSolder
R59: 3.3K; R_0805_2012Metric_Pad1.20x1.40mm_HandSolder
R60: 68; R_0805_2012Metric_Pad1.20x1.40mm_HandSolder
R61: 6; R_0805_2012Metric_Pad1.20x1.40mm_HandSolder
R62: 2.2K; R_0805_2012Metric_Pad1.20x1.40mm_HandSolder
R63: 680; R_0805_2012Metric_Pad1.20x1.40mm_HandSolder
R64, R67: 150; R_0805_2012Metric_Pad1.20x1.40mm_HandSolder
R66: 36; R_0805_2012Metric_Pad1.20x1.40mm_HandSolder
R68: 1.8K; R_0805_2012Metric_Pad1.20x1.40mm_HandSolder
U5: ADE-6; Mini-Circuits_CD542_LandPatternPL-052

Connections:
GND: C49.2, C55.2, C56.2, D15.2 (A), J9.2, J10.2, K9.5, K9.6, K9.7, K9.8, Q7.2 (S), R52.2, R54.2, R57.2, R58.2, R60.2, R61.2, R64.2, R67.2, R68.2, U5.1 (GND), U5.4 (GND), U5.5 (GND); also elsewhere on the board
unnamed: C50.1, K9.3
unnamed: C51.1, R56.1, R59.1
unnamed: C52.1, R61.1
unnamed: C53.1, L8.1, L8.3
unnamed: C53.2, R64.1, R66.1
unnamed: C55.1, L8.4, R65.2
unnamed: J9.1, R52.1, R53.1
unnamed: J10.1, R55.1
unnamed: K9.2, R53.2, R54.1
unnamed: C50.2, Q6.2 (B), R56.2, R57.1
unnamed: C51.2, L8.2, Q6.3 (C), R59.2
unnamed: C52.2, Q6.1 (E), R60.1
unnamed: Q7.3 (D), R62.1
unnamed: C49.1, Q7.1 (G), R55.2, R58.1
unnamed: C54.1, Q8.1 (B), R62.2, R63.2
unnamed: C54.2, C56.1, Q8.3 (C), R65.1, R68.1
unnamed: K9.4, U5.2 (IF)
SSB_TX_12V: D15.1 (K), K9.1; also elsewhere on the board
TX_12V: Q8.2 (E), R63.1; also elsewhere on the board
TX_COMMON_OUT: R66.2, R67.1; also elsewhere on the board
VFO_TX: U5.6 (LO); also elsewhere on the board
XFLT_TX_OUT: U5.3 (RF); also elsewhere on the board

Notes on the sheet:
"KEY.DN"
"CLK.CW"
SSB
12 dB attenuator
see /Xtal Filters/
see /RX/
Buffer: amp + 6 dB attenuator
10T bifilar @ FT37-43
CW waveform shaping

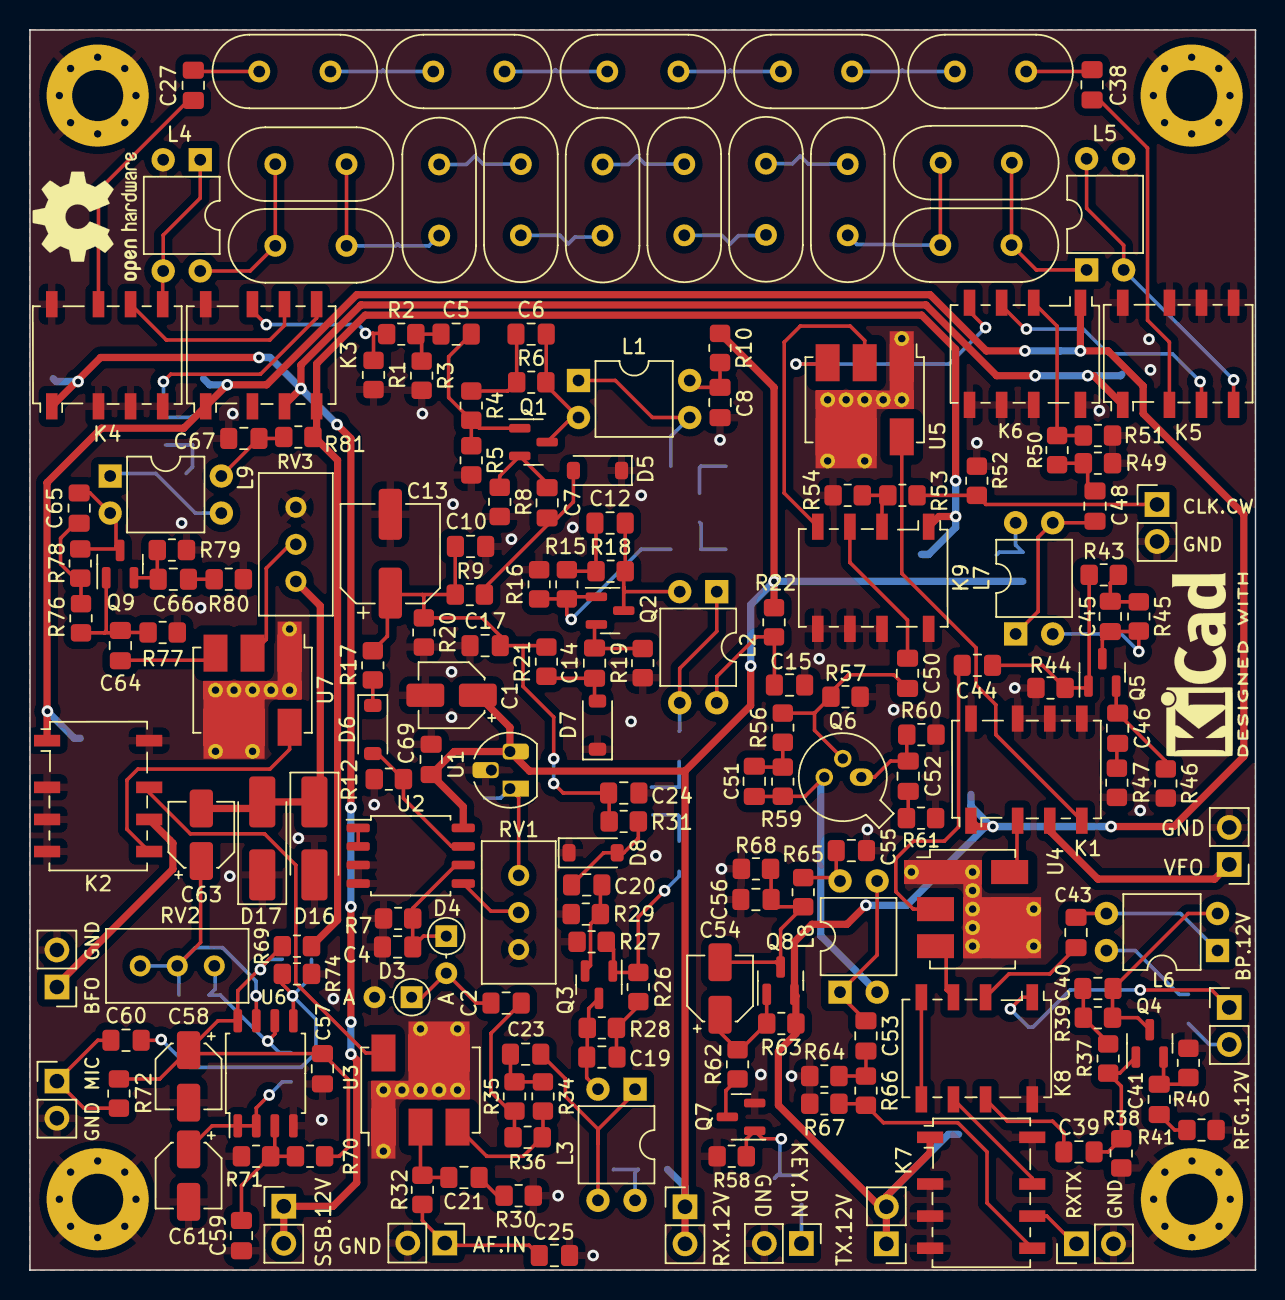
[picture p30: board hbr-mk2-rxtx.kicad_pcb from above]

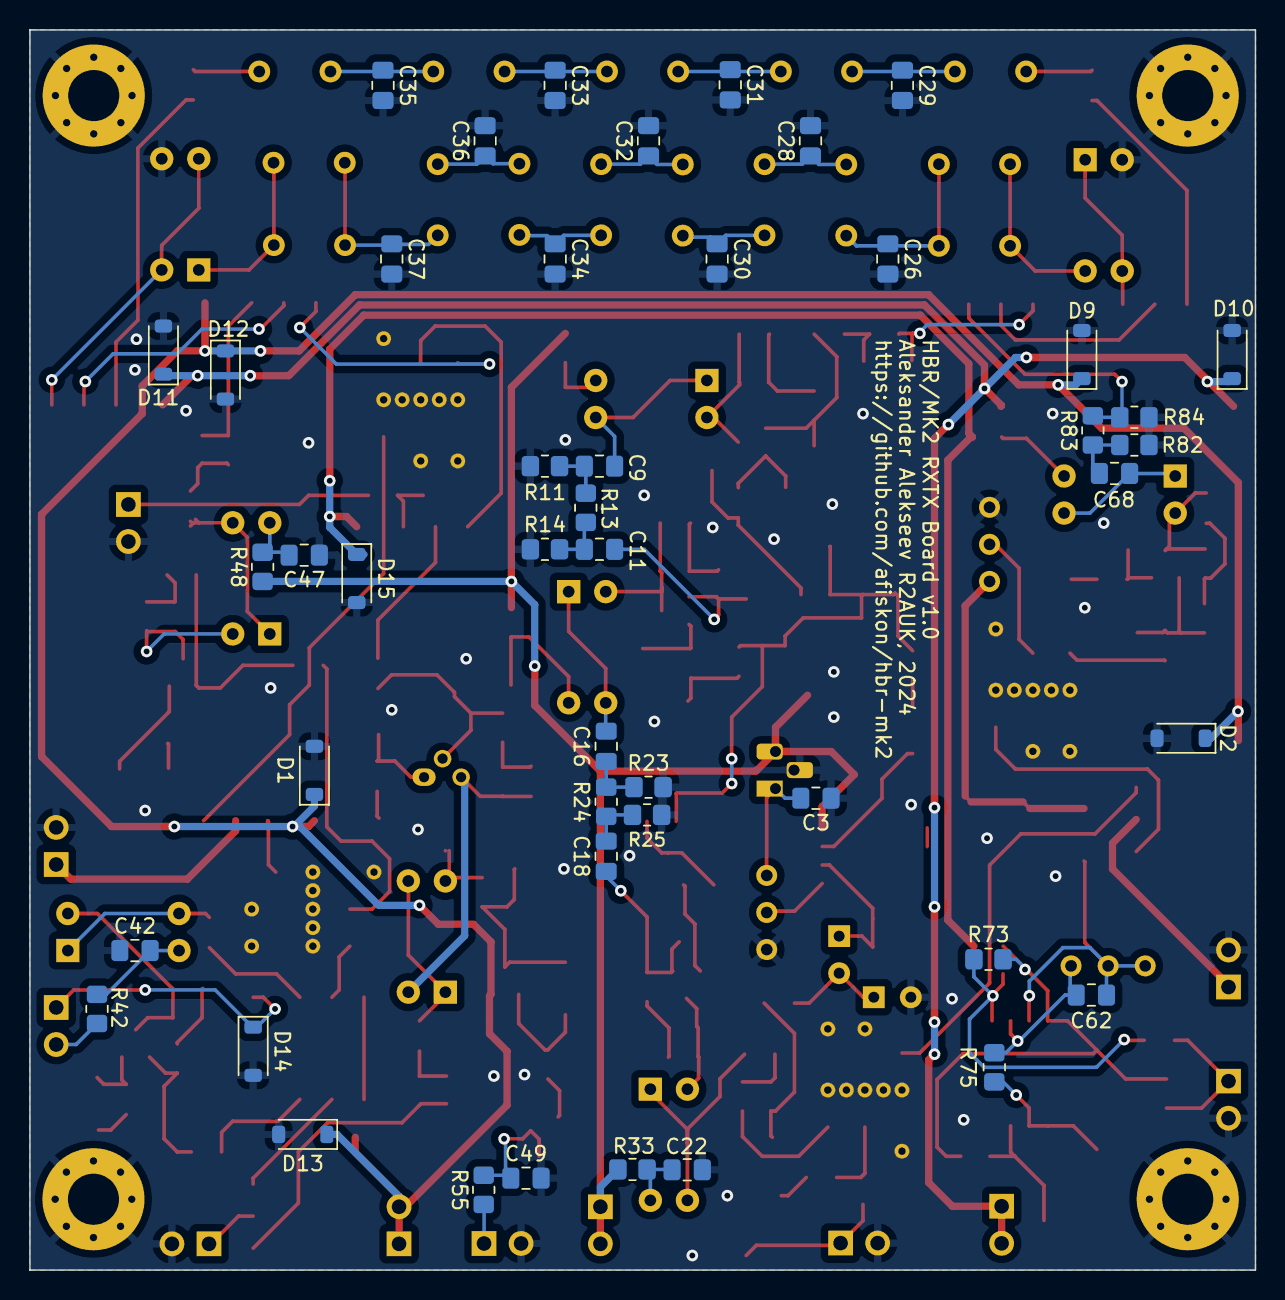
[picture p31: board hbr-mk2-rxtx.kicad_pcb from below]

Board: 2 copper layers, 84.0 x 85.0 mm, 239 parts (46 on the bottom side), 136 nets.

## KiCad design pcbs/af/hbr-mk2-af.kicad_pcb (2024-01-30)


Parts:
C1: 1u; CP_Elec_4x5.4
C2, C29, C31, C33, C36: 0.1u; C_0805_2012Metric_Pad1.18x1.45mm_HandSolder
C27, C32: 10u; CP_Elec_4x5.4
C28, C30: 4.7n; C_0805_2012Metric_Pad1.18x1.45mm_HandSolder
C34: 4.7u; CP_Elec_4x5.4
C35: 100p; C_0805_2012Metric_Pad1.18x1.45mm_HandSolder
D4, D5: 1N4148W; D_SOD-123
H1, H2, H3, H4: MountingHole_Pad; MountingHole_3.5mm_Pad_Via
HS2: Heatsink
J1, J7: Conn_01x02; PinHeader_1x02_P2.54mm_Vertical
Q4, Q5: 2N7002; SOT-23
R23, R24: 100K; R_0805_2012Metric_Pad1.20x1.40mm_HandSolder
R25: 47K; R_0805_2012Metric_Pad1.20x1.40mm_HandSolder
R26: 3.3K; R_0805_2012Metric_Pad1.20x1.40mm_HandSolder
R27: 10K; R_0805_2012Metric_Pad1.20x1.40mm_HandSolder
R28: 2.2K; R_0805_2012Metric_Pad1.20x1.40mm_HandSolder
R29: 22; R_0805_2012Metric_Pad1.20x1.40mm_HandSolder
RV3: 10K; Potentiometer_Bourns_3296W_Vertical
RV4: 100K; Potentiometer_Bourns_3296W_Vertical
SYM1: Logo_Open_Hardware_Small; OSHW-Logo2_9.8x8mm_SilkScreen
SYM2: SYM_Radio_Waves_Large; KiCad-Logo2_5mm_SilkScreen
U1: LM7808; TO-220-3_Vertical
U4: NE5532; SOIC-8_5.23x5.23mm_P1.27mm

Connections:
+8V: C2.1, C31.1, C32.1, R23.1, U1.3 (VO), U4.8 (V+); also elsewhere on the board
+12V: C1.1, J1.1, U1.1 (VI)
CW_TONE: C35.2; also elsewhere on the board
GND: C1.2, C2.2, C27.2, C29.2, C31.2, C32.2, C34.2, C36.2, H1.1, H2.1, H3.1, H4.1, J1.2, J7.2, R24.2, R27.2, U1.2 (GND), U4.4 (V-); also elsewhere on the board
unnamed: C27.1, C28.2, C29.1, R23.2, R24.1, R25.2, R26.1
unnamed: C30.2, RV4.1
unnamed: C36.1, R28.2, R29.1
unnamed: D4.2 (A), D5.1 (K), RV3.2, RV3.3, RV4.2, RV4.3, U4.3 (+), U4.7
unnamed: D4.1 (K), D5.2 (A), R26.2, RV3.1, U4.6 (-)
unnamed: J7.1, R29.2
unnamed: C33.2, Q4.3 (D)
unnamed: C34.1, Q4.1 (G), Q5.1 (G), R28.1
unnamed: Q4.2 (S), Q5.2 (S), R27.1
unnamed: C35.1, Q5.3 (D)
unnamed: C33.1, U4.1, U4.2 (-)
unnamed: C28.1, C30.1, R25.1, U4.5 (+)

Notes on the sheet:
Adjust to get a pure sine wave, about 7 Vpp
Adjust to get exactly 700 Hz
see /AF Amplifier/
"12V"
"EN.T"


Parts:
C3, C4, C8, C9, C11, C12, C14, C15, C16, C20: 10u; CP_Elec_4x5.4
C5, C6, C10, C19, C21, C22, C25, C26: 0.1u; C_0805_2012Metric_Pad1.18x1.45mm_HandSolder
C7: 22u; CP_Elec_5x5.4
C13: 4.7u; CP_Elec_4x5.4
C17: 1u; CP_Elec_4x5.4
C18: 220u; CP_Elec_8x10.5
C23, C24: 470u; CP_Elec_10x10.5
D1, D2: SS14; D_SMA_Handsoldering
D3: Blue LED; LED_0805_2012Metric_Pad1.15x1.40mm_HandSolder
HS1: Heatsink
J2, J3, J5: Conn_01x02; PinHeader_1x02_P2.54mm_Vertical
J4, J6: Conn_01x03; PinHeader_1x03_P2.54mm_Vertical
Q1: MMBT3904; SOT-23
Q2, Q3: 2N7002; SOT-23
R1: 100K; R_0805_2012Metric_Pad1.20x1.40mm_HandSolder
R2: 47K; R_0805_2012Metric_Pad1.20x1.40mm_HandSolder
R3, R4, R9, R10, R13, R16, R30: 10K; R_0805_2012Metric_Pad1.20x1.40mm_HandSolder
R5: 100; R_0805_2012Metric_Pad1.20x1.40mm_HandSolder
R6, R11: 2.2K; R_0805_2012Metric_Pad1.20x1.40mm_HandSolder
R7, R12: 1K; R_0805_2012Metric_Pad1.20x1.40mm_HandSolder
R8, R18: 22; R_0805_2012Metric_Pad1.20x1.40mm_HandSolder
R14: DNP
R15: 1.3K; R_0805_2012Metric_Pad1.20x1.40mm_HandSolder
R17: 220; R_0805_2012Metric_Pad1.20x1.40mm_HandSolder
R19: 680; R_0805_2012Metric_Pad1.20x1.40mm_HandSolder
R20, R21, R22: 10; R_0805_2012Metric_Pad1.20x1.40mm_HandSolder
RV1: 10K; Potentiometer_Bourns_3296W_Vertical
RV2: 500K; Potentiometer_Bourns_3296W_Vertical
U2: NE5532; SOIC-8_5.23x5.23mm_P1.27mm
U3: TDA2003; TO-220-5_P3.4x3.7mm_StaggerOdd_Lead3.8mm_Vertical

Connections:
+8V: C3.1, C5.1, C20.1, C22.1, R3.1, R5.1, R9.1, U2.8 (V+), U3.5 (V+); also elsewhere on the board
CW_TONE: C17.1, J4.2; also elsewhere on the board
GND: C3.2, C5.2, C6.2, C7.2, C8.2, C10.2, C13.2, C14.2, C16.2, C19.2, C20.2, C22.2, D1.2 (A), D3.1 (K), J2.2, J3.2, J4.1, J5.2, J6.3, R2.2, R4.2, R7.2, R10.2, R13.2, R16.2, R20.2, R21.2, R22.2, R30.2, RV1.3, U2.4 (V-), U3.3 (GND); also elsewhere on the board
unnamed: C8.1, R1.1, R5.2, R6.1
unnamed: C9.2, RV1.1
unnamed: C10.1, R8.1, R11.2, R30.1
unnamed: C12.1, RV1.2
unnamed: C15.1, RV2.1, RV2.2, U2.7
unnamed: C18.2, R19.2, R20.1
unnamed: C21.1, R17.2
unnamed: C21.2, C23.1, C24.1, R19.1, U3.4
unnamed: C25.2, R21.1
unnamed: C26.2, R22.1
unnamed: C15.2, D1.1 (K), D2.2 (A)
unnamed: C16.1, C19.1, D2.1 (K), D3.2 (A), R16.1, R18.1
unnamed: C4.2, C11.2, J2.1
unnamed: J3.1, R8.2
unnamed: J4.3, R15.2
unnamed: J5.1, R18.2
unnamed: C23.2, C26.1, J6.1
unnamed: C24.2, C25.1, J6.2
unnamed: C4.1, Q1.1 (B), R1.2, R2.1
unnamed: C9.1, Q1.3 (C), R6.2
unnamed: C7.1, Q1.2 (E), R7.1
unnamed: C12.2, Q2.3 (D), R14.1
unnamed: C13.1, Q2.1 (G), Q3.1 (G), R11.1
unnamed: Q2.2 (S), Q3.2 (S), R13.1
unnamed: Q3.3 (D), R14.2, R15.1
unnamed: C6.1, R3.2, R4.1, U2.3 (+)
unnamed: C14.1, R12.2, U2.1, U2.2 (-)
unnamed: C11.1, R9.2, R10.1, U2.5 (+)
unnamed: R12.1, RV2.3, U2.6 (-)
unnamed: C17.2, U3.1 (+)
unnamed: C18.1, R17.1, U3.2 (-)

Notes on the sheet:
gain control
"RX.12V"
VGND
In order to bypass mute circuit connect pins 3 of 2N7002s.
This resistor ensures that gain control of the driver has no effect on CW_TONE volume.
The blue LED ensures the voltage will not exceed 3V.
"VOL"
"S.MT"
see /CW Tone/
"EAR"
"AF.IN"



Board: 2 copper layers, 45.0 x 85.0 mm, 96 parts (5 on the bottom side), 47 nets.

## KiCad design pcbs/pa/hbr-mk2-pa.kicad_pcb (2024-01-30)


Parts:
C1, C2, C3, C4, C6, C7, C8, C9, C10, C11, C16, C17: 0.1u; C_0805_2012Metric_Pad1.18x1.45mm_HandSolder
C5: 10u; CP_Elec_4x5.4
C12, C13: 220u; CP_Elec_8x10.5
C14, C15: 2.7p; C_0805_2012Metric_Pad1.18x1.45mm_HandSolder
D1, D2: 1N4148W; D_SOD-123
H1, H2, H3, H4: MountingHole_Pad; MountingHole_3.5mm_Pad_Via
HS1, HS2: Heatsink
J1: Conn_01x04; PinHeader_1x04_P2.54mm_Vertical
J2, J3: Conn_01x02; PinHeader_1x02_P2.54mm_Vertical
K1, K2: G6K-2F-Y; Relay_DPDT_Omron_G6K-2F-Y
L1, L2: FT37-43; L_Toroid_Vertical_L10.0mm_W5.0mm_P5.08mm
L3: FT50-43; DIP-4_W10.16mm
Q1, Q2, Q3, Q4, Q5, Q6: KT3142A; TO-18-3
Q7, Q8: RD15HVF1; TO-220-3_Horizontal_TabDown
R1, R6, R8: 1K; R_0805_2012Metric_Pad1.20x1.40mm_HandSolder
R2, R7, R9: 100; R_0805_2012Metric_Pad1.20x1.40mm_HandSolder
R3, R4, R10, R11, R12, R13: 47; R_0805_2012Metric_Pad1.20x1.40mm_HandSolder
R5, R14: 22; R_0805_2012Metric_Pad1.20x1.40mm_HandSolder
R15, R16, R17, R18: 220; R_0805_2012Metric_Pad1.20x1.40mm_HandSolder
RV1, RV2: 10K; Potentiometer_Bourns_3296W_Vertical
SYM1: Logo_Open_Hardware_Small; OSHW-Logo2_9.8x8mm_SilkScreen
SYM2: SYM_Radio_Waves_Large; KiCad-Logo2_5mm_SilkScreen
T1, T2: FT37-43; DIP-6_W7.62mm
U1: L78L05; TO-92_HandSolder

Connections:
GND: C2.2, C5.2, C6.2, C7.2, C8.2, C9.2, C12.2, C13.2, C16.2, C17.2, D1.2 (A), D2.2 (A), H1.1, H2.1, H3.1, H4.1, J1.4, J2.2, J3.2, K1.5, K1.6, K1.7, K1.8, K2.5, K2.6, K2.7, K2.8, L3.3, Q7.2 (S), Q8.2 (S), R2.2, R3.2, R4.2, R7.2, R9.2, R10.2, R11.2, R12.2, R13.2, RV1.3, RV2.3, U1.2 (GND)
unnamed: C2.1, R5.1, T1.4
unnamed: C3.1, T1.1
unnamed: C4.1, T1.6
unnamed: C8.1, R15.2, RV1.2
unnamed: C9.1, R16.2, RV2.2
unnamed: C10.1, T2.1
unnamed: C11.1, T2.6
unnamed: C14.1, R17.1
unnamed: C15.1, R18.1
unnamed: J2.1, K1.3
unnamed: J3.1, K2.3
unnamed: K1.2, K2.2
unnamed: C1.2, Q1.2 (B), Q2.2 (B), R1.2, R2.1
unnamed: Q1.3 (C), Q2.3 (C), R1.1, T1.2
unnamed: Q1.1 (E), R3.1
unnamed: Q2.1 (E), R4.1
unnamed: C3.2, Q3.2 (B), Q5.2 (B), R6.2, R7.1
unnamed: Q3.3 (C), Q5.3 (C), R6.1, T2.2
unnamed: Q3.1 (E), R10.1
unnamed: C4.2, Q4.2 (B), Q6.2 (B), R8.2, R9.1
unnamed: Q4.3 (C), Q6.3 (C), R8.1, T2.4
unnamed: Q4.1 (E), R11.1
unnamed: Q5.1 (E), R12.1
unnamed: Q6.1 (E), R13.1
unnamed: L1.2, L3.1, Q7.3 (D), R17.2
unnamed: C10.2, C14.2, Q7.1 (G), R15.1
unnamed: L2.2, L3.2, Q8.3 (D), R18.2
unnamed: C11.2, C15.2, Q8.1 (G), R16.1
unnamed: R14.2, T2.3, T2.5
unnamed: T1.3, T1.5
PA_5V_REF: C6.1, RV1.1, RV2.1, U1.1 (VO)
PA_IN: C1.1, K1.4
PA_OUT: K2.4, L3.4
TX_12V: C5.1, C7.1, C12.1, C13.1, C16.1, C17.1, D1.1 (K), D2.1 (K), J1.1, J1.2, J1.3, K1.1, K2.1, L1.1, L2.1, R5.2, R14.1, U1.3 (VI)

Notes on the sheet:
10T trifilar @ FT37-43
== General notes == - HFD4/12 relay is a full equivalent of G6K-2F-Y - KT3142A transistor is a full equvalent of 2N2369A - KT3142A can be replaced with another transistor with fT >= 500 Mhz
10T bifilar @ FT50-43
10T @ FT37-43
RX path, PA bypass
Class AB power amplifier is similar to the one used in uBITX For more details see https://eax.me/rd15hvf1-qrp-power-amplifier/


Board: 2 copper layers, 63.5 x 63.5 mm, 64 parts (0 on the bottom side), 35 nets.

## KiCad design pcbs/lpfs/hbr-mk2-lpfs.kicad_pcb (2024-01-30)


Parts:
C1, C2, C3, C4, C5: 0.1u; C_0805_2012Metric_Pad1.18x1.45mm_HandSolder
C41, C42: 0.01u; C_0805_2012Metric_Pad1.18x1.45mm_HandSolder
D11, D12: 1N34 / D311 (*); D_DO-34_SOD68_P2.54mm_Vertical_AnodeUp
H1, H2, H3, H4: MountingHole_Pad; MountingHole_3.5mm_Pad_Via
J1: Conn_01x03; PinSocket_1x03_P2.54mm_Vertical
J2: Conn_01x02; PinSocket_1x02_P2.54mm_Vertical
J3: Conn_01x06; PinSocket_1x06_P2.54mm_Vertical
J4: Conn_01x04; PinSocket_1x04_P2.54mm_Vertical
J5, J10: Conn_01x01; PinSocket_1x01_P2.54mm_Vertical
J6, J7, J8, J9: Conn_Coaxial; PinSocket_1x02_P2.54mm_Vertical
L16, L17: 1 mH; L_Axial_L7.0mm_D3.3mm_P2.54mm_Vertical_Fastron_MICC
L18, L19: 6T
Q1, Q2, Q3, Q4, Q5: 2N7002; SOT-23
R1, R2, R3, R4, R5: 22; R_0805_2012Metric_Pad1.20x1.40mm_HandSolder
R6, R7, R8, R9, R10: 10K; R_0805_2012Metric_Pad1.20x1.40mm_HandSolder
R11, R12: 1K; R_0805_2012Metric_Pad1.20x1.40mm_HandSolder
R13, R14: 220; R_0805_2012Metric_Pad1.20x1.40mm_HandSolder
R15, R16, R17, R18: 100; R_0805_2012Metric_Pad1.20x1.40mm_HandSolder
SYM1: Logo_Open_Hardware_Small; OSHW-Logo2_9.8x8mm_SilkScreen
SYM2: SYM_Radio_Waves_Large; KiCad-Logo2_5mm_SilkScreen

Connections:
+12V: J4.1, J4.2, J4.3; also elsewhere on the board
ANT: J8.1 (In), L19.1
GND: C1.2, C2.2, C3.2, C4.2, C5.2, C41.2, C42.2, H1.1, H2.1, H3.1, H4.1, J1.3, J2.2, J3.6, J4.4, J5.1, J6.2 (Ext), J9.2 (Ext), J10.1, L18.1, L19.2, Q1.2 (S), Q2.2 (S), Q3.2 (S), Q4.2 (S), Q5.2 (S), R6.2, R7.2, R8.2, R9.2, R10.2, R11.1, R12.1, R15.2, R16.2, R17.2, R18.2; also elsewhere on the board
LPFS_IN: J6.1 (In); also elsewhere on the board
LPFS_OUT: J2.1; also elsewhere on the board
LPF_10_12_GND: Q5.3 (D); also elsewhere on the board
LPF_15_17_GND: Q1.3 (D); also elsewhere on the board
LPF_20_30_GND: Q2.3 (D); also elsewhere on the board
LPF_40_GND: Q3.3 (D); also elsewhere on the board
LPF_80_GND: Q4.3 (D); also elsewhere on the board
LPF_SEL_10_12: J3.1, R3.1
LPF_SEL_15_17: J3.2, R1.1
LPF_SEL_20_30: J3.3, R5.1
LPF_SEL_40: J3.4, R4.1
LPF_SEL_80: J3.5, R2.1
unnamed: D11.2 (A), J7.1 (In), L18.2, R15.1, R17.1
unnamed: C41.1, D11.1 (K), L16.2
unnamed: D12.2 (A), J9.1 (In), R16.1, R18.1
unnamed: C42.1, D12.1 (K), L17.2
unnamed: L16.1, R13.2
unnamed: L17.1, R14.2
unnamed: C1.1, Q1.1 (G), R1.2, R6.1
unnamed: C2.1, Q2.1 (G), R5.2, R7.1
unnamed: C3.1, Q3.1 (G), R4.2, R8.1
unnamed: C4.1, Q4.1 (G), R2.2, R9.1
unnamed: C5.1, Q5.1 (G), R3.2, R10.1
PWR_FWD: J1.2, R12.2, R14.1
PWR_REF: J1.1, R11.2, R13.1

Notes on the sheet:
see /LPFs/
Tandem match / Stockton bridge @ BN61-202 Primary windings: RG-174 coax cables Secondary windings: 6T enameled copper wire
(*) Matched pair


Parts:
C6, C20: 680p; C_0805_2012Metric_Pad1.18x1.45mm_HandSolder
C7, C16, C18, C22, C25, C31: 220p; C_0805_2012Metric_Pad1.18x1.45mm_HandSolder
C8, C12, C23: 330p; C_0805_2012Metric_Pad1.18x1.45mm_HandSolder
C9, C21, C28, C33, C36, C39: 100p; C_0805_2012Metric_Pad1.18x1.45mm_HandSolder
C10: 33p; C_0805_2012Metric_Pad1.18x1.45mm_HandSolder
C11, C38: 47p; C_0805_2012Metric_Pad1.18x1.45mm_HandSolder
C13, C17, C19, C26: 470p; C_0805_2012Metric_Pad1.18x1.45mm_HandSolder
C14: 820p; C_0805_2012Metric_Pad1.18x1.45mm_HandSolder
C15, C24, C27, C32, C35: 150p; C_0805_2012Metric_Pad1.18x1.45mm_HandSolder
C29: 22p; C_0805_2012Metric_Pad1.18x1.45mm_HandSolder
C30: 18p; C_0805_2012Metric_Pad1.18x1.45mm_HandSolder
C34, C37, C40: 68p; C_0805_2012Metric_Pad1.18x1.45mm_HandSolder
D1, D2, D3, D4, D5, D6, D7, D8, D9, D10: 1N4148W; D_SOD-123
K1, K2, K3, K4, K5, K6, K7, K8, K9, K10: G6K-2F-Y; Relay_DPDT_Omron_G6K-2F-Y
L1, L2, L3, L4, L5, L6, L7, L8, L9, L10, L11, L12, L13, L14, L15: T50-6; L_Toroid_Vertical_L13.0mm_W6.5mm_P5.60mm

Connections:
+12V: D1.1 (K), D2.1 (K), D3.1 (K), D4.1 (K), D5.1 (K), D6.1 (K), D7.1 (K), D8.1 (K), D9.1 (K), D10.1 (K), K1.1, K2.1, K3.1, K4.1, K5.1, K6.1, K7.1, K8.1, K9.1, K10.1; also elsewhere on the board
GND: C6.2, C7.2, C8.2, C12.2, C13.2, C14.2, C18.2, C19.2, C20.2, C24.2, C25.2, C26.2, C27.2, C28.2, C31.2, C32.2, C35.2, C36.2, C39.2, C40.2, K1.2, K1.3, K1.4, K2.2, K2.3, K2.4, K3.2, K3.3, K3.4, K4.2, K4.3, K4.4, K5.2, K5.3, K5.4, K6.2, K6.3, K6.4, K7.2, K7.3, K7.4, K8.2, K8.3, K8.4, K9.2, K9.3, K9.4, K10.2, K10.3, K10.4; also elsewhere on the board
LPFS_IN: K4.6, K5.6, K6.6, K9.6, K10.6; also elsewhere on the board
LPFS_OUT: K1.6, K2.6, K3.6, K7.6, K8.6; also elsewhere on the board
LPF_10_12_GND: D8.2 (A), D10.2 (A), K8.8, K10.8; also elsewhere on the board
LPF_15_17_GND: D7.2 (A), D9.2 (A), K7.8, K9.8; also elsewhere on the board
LPF_20_30_GND: D3.2 (A), D6.2 (A), K3.8, K6.8; also elsewhere on the board
LPF_40_GND: D2.2 (A), D5.2 (A), K2.8, K5.8; also elsewhere on the board
LPF_80_GND: D1.2 (A), D4.2 (A), K1.8, K4.8; also elsewhere on the board
unnamed: C6.1, C9.1, K1.5, L1.1
unnamed: C7.1, C10.1, K3.5, L2.1
unnamed: C10.2, C12.1, C15.1, L2.2, L4.1
unnamed: C8.1, C11.1, K2.5, L3.1
unnamed: C11.2, C13.1, C16.1, L3.2, L5.1
unnamed: C9.2, C14.1, C17.1, L1.2, L6.1
unnamed: C15.2, C18.1, C21.1, L4.2, L7.1
unnamed: C16.2, C19.1, C22.1, L5.2, L8.1
unnamed: C17.2, C20.1, C23.1, L6.2, L9.1
unnamed: C21.2, C24.1, K6.5, L7.2
unnamed: C22.2, C25.1, K5.5, L8.2
unnamed: C23.2, C26.1, K4.5, L9.2
unnamed: C27.1, C29.1, K7.5, L10.1
unnamed: C28.1, C30.1, K8.5, L11.1
unnamed: C29.2, C31.1, C33.1, L10.2, L12.1
unnamed: C30.2, C32.1, C34.1, L11.2, L13.1
unnamed: C33.2, C35.1, C37.1, L12.2, L14.1
unnamed: C34.2, C36.1, C38.1, L13.2, L15.1
unnamed: C37.2, C39.1, K9.5, L14.2
unnamed: C38.2, C40.1, K10.5, L15.2

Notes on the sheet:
0.68u
0.40u
0.59u
1.00u
0.19u
0.28u
0.40u = 9T @ T50-6 0.26u = 6T @ T50-6 0.28u = 6T @ T50-6
0.38u
0.42u
2.05u = 23T @ T50-6 1.33u = 18T @ T50-6 1.40u = 19T @ T50-6
see /SWR Bridge/
0.59u = 11T @ T50-6 0.38u = 8T @ T50-6 0.42u = 9T @ T50-6
2.05u
1.00u = 16T @ T50-6 0.65u = 13T @ T50-6 0.68u = 13T @ T50-6
1.40u
0.65u
0.29u
1.33u
0.26u
0.29u = 6T @ T50-6 0.19u = 5T @ T50-6 0.20u = 5T @ T50-6
0.20u



Board: 2 copper layers, 84.0 x 69.0 mm, 120 parts (55 on the bottom side), 47 nets.

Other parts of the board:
J11: Conn_01x01; PinSocket_1x01_P2.54mm_Vertical

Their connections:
GND: J11.1; also elsewhere on the board

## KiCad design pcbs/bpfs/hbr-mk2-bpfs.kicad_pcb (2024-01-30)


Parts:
C1, C2, C3, C4: 0.1u; C_0805_2012Metric_Pad1.18x1.45mm_HandSolder
C5: 10u; CP_Elec_4x5.4
H1, H2, H3, H4: MountingHole_Pad; MountingHole_3.5mm_Pad_Via
J1: Conn_01x04; PinHeader_1x04_P2.54mm_Vertical
J2, J3, J4: Conn_01x02; PinHeader_1x02_P2.54mm_Vertical
Q1, Q2, Q3, Q4, Q5, Q6, Q7, Q8: 2N7002; SOT-23
R1, R2, R3: 22; R_0805_2012Metric_Pad1.20x1.40mm_HandSolder
R4, R5, R6: 10K; R_0805_2012Metric_Pad1.20x1.40mm_HandSolder
SYM1: Logo_Open_Hardware_Small; OSHW-Logo2_9.8x8mm_SilkScreen
SYM2: SYM_Radio_Waves_Large; KiCad-Logo2_5mm_SilkScreen
U1: 74HC238; SO-16_5.3x10.2mm_P1.27mm
U2: L78L33; TO-92_HandSolder

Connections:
+12V: C5.1, J2.1, U2.3 (VI); also elsewhere on the board
BPFS_IN: J3.1; also elsewhere on the board
BPFS_OUT: J4.1; also elsewhere on the board
BPF_10_GND: Q1.3 (D); also elsewhere on the board
BPF_12_GND: Q2.3 (D); also elsewhere on the board
BPF_15_GND: Q3.3 (D); also elsewhere on the board
BPF_17_GND: Q4.3 (D); also elsewhere on the board
BPF_20_GND: Q5.3 (D); also elsewhere on the board
BPF_30_GND: Q6.3 (D); also elsewhere on the board
BPF_40_GND: Q7.3 (D); also elsewhere on the board
BPF_80_GND: Q8.3 (D); also elsewhere on the board
BPF_SEL_A0: C3.2, R3.1, R6.2, U1.1 (A0)
BPF_SEL_A1: C1.2, R1.1, R4.2, U1.2 (A1)
BPF_SEL_A2: C2.2, R2.1, R5.2, U1.3 (A2)
GND: C1.1, C2.1, C3.1, C4.1, C5.2, H1.1, H2.1, H3.1, H4.1, J1.4, J2.2, J3.2, J4.2, Q1.2 (S), Q2.2 (S), Q3.2 (S), Q4.2 (S), Q5.2 (S), Q6.2 (S), Q7.2 (S), Q8.2 (S), R4.1, R5.1, R6.1, U1.4 (~E1), U1.5 (~E2), U1.8 (GND), U2.2 (GND); also elsewhere on the board
unnamed: J1.1, R3.2
unnamed: J1.2, R1.2
unnamed: J1.3, R2.2
unnamed: Q1.1 (G), U1.15 (Y0)
unnamed: Q2.1 (G), U1.14 (Y1)
unnamed: Q3.1 (G), U1.13 (Y2)
unnamed: Q4.1 (G), U1.12 (Y3)
unnamed: Q5.1 (G), U1.11 (Y4)
unnamed: Q6.1 (G), U1.10 (Y5)
unnamed: Q7.1 (G), U1.9 (Y6)
unnamed: Q8.1 (G), U1.7 (Y7)
unnamed: C4.2, U1.6 (E3), U1.16 (VCC), U2.1 (VO)

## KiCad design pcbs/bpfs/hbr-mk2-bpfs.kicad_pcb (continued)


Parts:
D1, D2, D3, D4, D5, D6, D7, D8, D9, D10, D11, D12, D13, D14, D15, D16: 1N4148W; D_SOD-123
K1, K2, K3, K4, K5, K6, K7, K8, K9, K10, K11, K12, K13, K14, K15, K16: G6K-2F-Y; Relay_DPDT_Omron_G6K-2F-Y

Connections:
+12V: D1.1 (K), D2.1 (K), D3.1 (K), D4.1 (K), D5.1 (K), D6.1 (K), D7.1 (K), D8.1 (K), D9.1 (K), D10.1 (K), D11.1 (K), D12.1 (K), D13.1 (K), D14.1 (K), D15.1 (K), D16.1 (K), K1.1, K2.1, K3.1, K4.1, K5.1, K6.1, K7.1, K8.1, K9.1, K10.1, K11.1, K12.1, K13.1, K14.1, K15.1, K16.1; also elsewhere on the board
BPFS_IN: K1.6, K2.6, K5.6, K6.6, K7.6, K11.6, K12.6, K13.6; also elsewhere on the board
BPFS_OUT: K3.3, K3.6, K4.3, K4.6, K8.3, K8.6, K9.3, K9.6, K10.3, K10.6, K14.3, K14.6, K15.3, K15.6, K16.3, K16.6; also elsewhere on the board
BPF_10_GND: D1.2 (A), D4.2 (A), K2.8, K4.8; also elsewhere on the board
BPF_10_IN: K2.5; also elsewhere on the board
BPF_10_OUT: K4.4, K4.5; also elsewhere on the board
BPF_12_GND: D2.2 (A), D3.2 (A), K1.8, K3.8; also elsewhere on the board
BPF_12_IN: K1.5; also elsewhere on the board
BPF_12_OUT: K3.4, K3.5; also elsewhere on the board
BPF_15_GND: D7.2 (A), D10.2 (A), K7.8, K10.8; also elsewhere on the board
BPF_15_IN: K7.5; also elsewhere on the board
BPF_15_OUT: K10.4, K10.5; also elsewhere on the board
BPF_17_GND: D6.2 (A), D9.2 (A), K6.8, K9.8; also elsewhere on the board
BPF_17_IN: K6.5; also elsewhere on the board
BPF_17_OUT: K9.4, K9.5; also elsewhere on the board
BPF_20_GND: D5.2 (A), D8.2 (A), K5.8, K8.8; also elsewhere on the board
BPF_20_IN: K5.5; also elsewhere on the board
BPF_20_OUT: K8.4, K8.5; also elsewhere on the board
BPF_30_GND: D12.2 (A), D16.2 (A), K12.8, K15.8; also elsewhere on the board
BPF_30_IN: K12.5; also elsewhere on the board
BPF_30_OUT: K15.4, K15.5; also elsewhere on the board
BPF_40_GND: D13.2 (A), D14.2 (A), K13.8, K16.8; also elsewhere on the board
BPF_40_IN: K13.5; also elsewhere on the board
BPF_40_OUT: K16.4, K16.5; also elsewhere on the board
BPF_80_GND: D11.2 (A), D15.2 (A), K11.8, K14.8; also elsewhere on the board
BPF_80_IN: K11.5; also elsewhere on the board
BPF_80_OUT: K14.4, K14.5; also elsewhere on the board
GND: K1.2, K1.3, K1.4, K2.2, K2.3, K2.4, K5.2, K5.3, K5.4, K6.2, K6.3, K6.4, K7.2, K7.3, K7.4, K11.2, K11.3, K11.4, K12.2, K12.3, K12.4, K13.2, K13.3, K13.4; also elsewhere on the board


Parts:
C6, C22: 470p; C_0805_2012Metric_Pad1.18x1.45mm_HandSolder
C7, C23: 150p; C_0805_2012Metric_Pad1.18x1.45mm_HandSolder
C8, C24: 100p; C_0805_2012Metric_Pad1.18x1.45mm_HandSolder
C9, C25: 68p; C_0805_2012Metric_Pad1.18x1.45mm_HandSolder
C10, C11, C12, C13, C18, C19, C20, C21, C30, C31, C32, C33, C38, C39, C40, C41: 30p; C_Trim_THD_L7.0mm_W6.5mm_P5.00mm
C14: 50p; C_Trim_THD_L7.0mm_W6.5mm_P5.00mm
C15: 20p; C_Trim_THD_L7.0mm_W6.5mm_P5.00mm
C16, C17, C34: 10p; C_Trim_THD_L7.0mm_W6.5mm_P5.00mm
C26, C42: 47p; C_0805_2012Metric_Pad1.18x1.45mm_HandSolder
C27, C43: 33p; C_0805_2012Metric_Pad1.18x1.45mm_HandSolder
C28, C45: 22p; C_0805_2012Metric_Pad1.18x1.45mm_HandSolder
C29, C44: DNP; C_0805_2012Metric_Pad1.18x1.45mm_HandSolder
C35, C36, C37: 5p; C_Trim_THD_L7.0mm_W6.5mm_P5.00mm
L1, L5: T37-2; DIP-4_W7.62mm
L2, L3, L4, L6, L7, L8, L9, L10, L11, L12, L13, L14, L15, L16: T37-6; DIP-4_W7.62mm

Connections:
BPF_10_IN: L12.1; also elsewhere on the board
BPF_10_OUT: L16.4; also elsewhere on the board
BPF_12_IN: L11.1; also elsewhere on the board
BPF_12_OUT: L15.4; also elsewhere on the board
BPF_15_IN: L10.1; also elsewhere on the board
BPF_15_OUT: L14.4; also elsewhere on the board
BPF_17_IN: L9.1; also elsewhere on the board
BPF_17_OUT: L13.4; also elsewhere on the board
BPF_20_IN: L4.1; also elsewhere on the board
BPF_20_OUT: L8.4; also elsewhere on the board
BPF_30_IN: L3.1; also elsewhere on the board
BPF_30_OUT: L7.4; also elsewhere on the board
BPF_40_IN: L2.1; also elsewhere on the board
BPF_40_OUT: L6.4; also elsewhere on the board
BPF_80_IN: L1.1; also elsewhere on the board
BPF_80_OUT: L5.4; also elsewhere on the board
GND: C6.2, C7.2, C8.2, C9.2, C10.2, C11.2, C12.2, C13.2, C18.2, C19.2, C20.2, C21.2, C22.2, C23.2, C24.2, C25.2, C26.2, C27.2, C28.2, C29.2, C30.2, C31.2, C32.2, C33.2, C38.2, C39.2, C40.2, C41.2, C42.2, C43.2, C44.2, C45.2, L1.2, L1.3, L2.2, L2.3, L3.2, L3.3, L4.2, L4.3, L5.2, L5.3, L6.2, L6.3, L7.2, L7.3, L8.2, L8.3, L9.2, L9.3, L10.2, L10.3, L11.2, L11.3, L12.2, L12.3, L13.2, L13.3, L14.2, L14.3, L15.2, L15.3, L16.2, L16.3; also elsewhere on the board
unnamed: C6.1, C10.1, C14.2, L1.4
unnamed: C7.1, C11.1, C15.2, L2.4
unnamed: C8.1, C12.1, C16.2, L3.4
unnamed: C9.1, C13.1, C17.2, L4.4
unnamed: C14.1, C18.1, C22.1, L5.1
unnamed: C15.1, C19.1, C23.1, L6.1
unnamed: C16.1, C20.1, C24.1, L7.1
unnamed: C17.1, C21.1, C25.1, L8.1
unnamed: C26.1, C30.1, C34.2, L9.4
unnamed: C27.1, C31.1, C35.2, L10.4
unnamed: C28.1, C32.1, C36.2, L11.4
unnamed: C29.1, C33.1, C37.2, L12.4
unnamed: C34.1, C38.1, C42.1, L13.1
unnamed: C35.1, C39.1, C43.1, L14.1
unnamed: C36.1, C40.1, C45.1, L15.1
unnamed: C37.1, C41.1, C44.1, L16.1

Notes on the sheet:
18:3T
3:18T
6:29T
5:25T
3:16T
4:20T
29:6T
16:3T
20:4T
6:30T
30:6T
17:3T
3:17T
25:5T



Board: 2 copper layers, 79.0 x 85.0 mm, 119 parts (34 on the bottom side), 59 nets.

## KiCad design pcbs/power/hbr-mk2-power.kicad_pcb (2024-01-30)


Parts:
C1: 1000u; CP_Radial_D13.0mm_P5.00mm
C2, C3, C4, C5, C6: 0.1u; C_0805_2012Metric_Pad1.18x1.45mm_HandSolder
D1: SS14; D_SMA_Handsoldering
D2, D3, D4, D5: LED; LED_0805_2012Metric_Pad1.15x1.40mm_HandSolder
H1, H2: MountingHole_Pad; MountingHole_3.5mm_Pad_Via
J1, J2, J3, J4: Conn_01x08; PinHeader_1x08_P2.54mm_Vertical
J5: Conn_01x03; PinSocket_1x03_P2.54mm_Vertical
Q1, Q3: 2N7002; SOT-23
Q2, Q4, Q5: IRF4905; TO-220-3_Vertical
R1, R5: 22; R_0805_2012Metric_Pad1.20x1.40mm_HandSolder
R2, R3, R7, R8, R13: 10K; R_0805_2012Metric_Pad1.20x1.40mm_HandSolder
R4, R12, R14: 100K; R_0805_2012Metric_Pad1.20x1.40mm_HandSolder
R6, R9, R11, R17: 4.7K; R_0805_2012Metric_Pad1.20x1.40mm_HandSolder
R10: DNP (10K); R_0805_2012Metric_Pad1.20x1.40mm_HandSolder
R15: 0; R_0805_2012Metric_Pad1.20x1.40mm_HandSolder
R16: DNP; R_0805_2012Metric_Pad1.20x1.40mm_HandSolder
SYM1: SYM_Radio_Waves_Large; KiCad-Logo2_5mm_SilkScreen
SYM2: Logo_Open_Hardware_Small; OSHW-Logo2_9.8x8mm_SilkScreen

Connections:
+12V: C1.1, D1.1 (K), D2.2 (A), J1.1, J1.2, J1.3, J1.4, J1.5, J1.6, J1.7, J1.8, Q2.3 (S), Q4.3 (S), Q5.3 (S), R3.1, R10.1, R13.1
ENABLE_SSB: J5.2, R5.1
ENABLE_TX_12V: J5.1, R1.1
GND: C1.2, C2.2, C3.2, C4.2, C5.2, C6.2, D1.2 (A), H1.1, H2.1, J2.1, J2.2, J2.3, J2.4, J2.5, J2.6, J2.7, J2.8, J5.3, Q1.2 (S), Q3.2 (S), R2.2, R4.2, R6.2, R7.2, R9.2, R11.2, R12.2, R14.2, R17.2
unnamed: D2.1 (K), R6.1
unnamed: D3.1 (K), R9.1
unnamed: D4.1 (K), R11.1
unnamed: D5.1 (K), R17.1
unnamed: C3.1, Q1.3 (D), Q2.1 (G), R3.2
unnamed: C2.1, Q1.1 (G), R1.2, R2.1
unnamed: Q3.3 (D), R15.1, R16.1
unnamed: C4.1, Q3.1 (G), R5.2, R7.1
unnamed: C5.1, Q4.1 (G), R8.2, R10.2, R16.2
unnamed: C6.1, Q5.1 (G), R13.2, R15.2
RX_12V: D3.2 (A), J4.1, J4.2, J4.3, J4.4, Q4.2 (D), R12.1
SSB_12V: D5.2 (A), J4.5, J4.6, J4.7, J4.8, Q5.2 (D), R14.1
TX_12V: D4.2 (A), J3.1, J3.2, J3.3, J3.4, J3.5, J3.6, J3.7, J3.8, Q2.2 (D), R4.1, R8.1

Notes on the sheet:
(was: ENABLE_RX_12V)



Board: 2 copper layers, 45.5 x 30.5 mm, 42 parts (9 on the bottom side), 17 nets.

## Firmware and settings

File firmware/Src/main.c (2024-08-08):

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

/* Includes ------------------------------------------------------------------*/
#include "main.h"

/* USER CODE BEGIN Includes */
#include <string.h>
#include <stdlib.h>
#include <stdbool.h>
#include <math.h>
#include "si5351.h"
#include "lcd.h"

/* USER CODE END Includes */

ADC_HandleTypeDef hadc1;

I2C_HandleTypeDef hi2c1;

TIM_HandleTypeDef htim1;
TIM_HandleTypeDef htim2;

/* USER CODE BEGIN PV */

/* USER CODE END PV */

void SystemClock_Config(void);
static void MX_GPIO_Init(void);
static void MX_TIM1_Init(void);
static void MX_I2C1_Init(void);
static void MX_ADC1_Init(void);
static void MX_TIM2_Init(void);
/* USER CODE BEGIN PFP */

/* USER CODE END PFP */

/* USER CODE BEGIN 0 */

#define CH_CW   0
#define CH_CAL  1
#define CH_VFO  2

#define LOOP_DELAY 5

const int32_t CWFilterCenterFrequency = 8998300;
const int32_t SSBFilterLowFrequency  = 8997600;
const int32_t SSBFilterHighFrequency = 9000670;

const int32_t si5351_correction = 11014;
const si5351DriveStrength_t VFODriveStrength = SI5351_DRIVE_STRENGTH_4MA;

/* Adjust for used rotary encoders */
#define MAIN_DELTA_DIV 20
#define MAIN_DELTA_MULT 1
#define CLAR_DELTA_DIV 1
#define CLAR_DELTA_MULT -1

int32_t Fvfo = 1000000; // dummy value, will be changed below

const uint8_t eeprom_i2c_addr = (0x50 << 1);
#define EEPROM_PAGE_SIZE 32
#define KEYER_CONFIG_EEPROM_ADDR        0x0000
#define KEYER_MESSAGE_EEPROM_ADDR       0x0400

typedef enum {
    CLAR_MODE_DISABLED = 0,
    CLAR_MODE_RIT = 1,
    CLAR_MODE_XIT = 2,
} ClarMode_t;

bool lockMode = false;
bool fastMode = false;
ClarMode_t clarMode = CLAR_MODE_DISABLED;

int32_t clarOffset = 0;

typedef enum {
    CW_SEND_NONE = 0,
    CW_SEND_DIT = 1,
    CW_SEND_DAH = 2,
} CwSend_t;

CwSend_t lastSent = CW_SEND_NONE;
CwSend_t nextSend = CW_SEND_NONE;

typedef enum {
    KEYER_SETINGS_PAGE_SPEED = 0,
    KEYER_SETINGS_PAGE_SAVE = 1,
    KEYER_SETINGS_PAGE_PLAY = 2,
} KeyerSettingsPage_t;

typedef struct {
    uint16_t checksum;
    bool straightKey;
    int32_t speedWPM;
    int32_t ditTimeMs;
    KeyerSettingsPage_t settingsPage;
} KeyerConfig_t;

KeyerConfig_t keyerConfig = {
    .checksum = 0,
    .straightKey = false,
    .speedWPM = 19,

    // ditTimeMs = 60*1000/(50*WPM)
    // where 50 is the length in dits of "PARIS "
    // see https://morsecode.world/international/timing.html
    .ditTimeMs = 63,
    .settingsPage = KEYER_SETINGS_PAGE_SPEED,
};

#define MAX_KEYER_MESSAGE_LENGTH 500

typedef struct {
    uint16_t checksum;
    uint16_t length;
    char message[MAX_KEYER_MESSAGE_LENGTH];
} KeyerMessage_t;

KeyerMessage_t keyerMessage = {
    .checksum = 0,
    .length = 0,
};

bool inTransmitMode = false;
bool transmittingSSB = false;

#define BUTTON_DEBOUNCE_TIME_MS 200
typedef enum {
    BUTTON_STATUS_PRESSED = 0,
    BUTTON_STATUS_RELEASED = 1,
    BUTTON_STATUS_DEBOUNCE = 2,
} ButtonStatus_t;

typedef enum {
    USE_LPF_80 = 0,
    USE_LPF_40 = 1,
    USE_LPF_20_30 = 2,
    USE_LPF_15_17 = 3,
    USE_LPF_10_12 = 4,
} UseLPF_t;

typedef enum {
    USE_BPF_80 = 0,
    USE_BPF_40 = 1,
    USE_BPF_30 = 2,
    USE_BPF_20 = 3,
    USE_BPF_17 = 4,
    USE_BPF_15 = 5,
    USE_BPF_12 = 6,
    USE_BPF_10 = 7,
} UseBPF_t;

#define FAST_FREQUENCIES_NUMBER 5

typedef struct {
    int32_t minFreq;
    int32_t maxFreq;
    int32_t lastFreq;
    /* The array of FAST frequencies should be sorted */
    int32_t fastFreqs[FAST_FREQUENCIES_NUMBER];
    UseLPF_t lpf;
    UseBPF_t bpf;
    /*
     * Compensate for losses in RG-174, frequency response of the given
     * PA depending on the used transistor, imperfections of the LPFs, etc.
     * This works only for CW.
     */
    si5351DriveStrength_t txDriveStrength;
} BandInfo_t;

int32_t currentBand = 3; // default: 20m

BandInfo_t bands[] = {
    {
        .minFreq  = 3500000,
        .maxFreq  = 3800000,
        .lastFreq = 3560000,
        .fastFreqs = { 3500000, 3560000, 3570000, 3600000, 3800000 },
        .lpf = USE_LPF_80,
        .bpf = USE_BPF_80,
        .txDriveStrength = SI5351_DRIVE_STRENGTH_2MA,
    },
    {
        .minFreq  = 7000000,
        .maxFreq  = 7200000,
        .lastFreq = 7030000,
        .fastFreqs = { 7000000, 7030000, 7040000, 7050000, 7200000 },
        .lpf = USE_LPF_40,
        .bpf = USE_BPF_40,
        .txDriveStrength = SI5351_DRIVE_STRENGTH_2MA,
    },
    {
        .minFreq  = 10100000,
        .maxFreq  = 10150000,
        .lastFreq = 10116000,
        .fastFreqs = { 10100000, 10116000, 10130000, -1, -1 },
        .lpf = USE_LPF_20_30,
        .bpf = USE_BPF_30,
        .txDriveStrength = SI5351_DRIVE_STRENGTH_2MA,
    },
    {
        .minFreq  = 14000000,
        .maxFreq  = 14350000,
        .lastFreq = 14060000,
        .fastFreqs = { 14000000, 14060000, 14070000, 14101000, 14350000 },
        .lpf = USE_LPF_20_30,
        .bpf = USE_BPF_20,
        .txDriveStrength = SI5351_DRIVE_STRENGTH_2MA,
    },
    {
        .minFreq  = 18068000,
        .maxFreq  = 18168000,
        .lastFreq = 18086000,
        .fastFreqs = { 18068000, 18086000, 18095000, 18111000, 18168000 },
        .lpf = USE_LPF_15_17,
        .bpf = USE_BPF_17,
        .txDriveStrength = SI5351_DRIVE_STRENGTH_4MA,
    },
    {
        .minFreq  = 21000000,
        .maxFreq  = 21450000,
        .lastFreq = 21060000,
        .fastFreqs = { 21000000, 21060000, 21070000, 21151000, 21450000 },
        .lpf = USE_LPF_15_17,
        .bpf = USE_BPF_15,
        .txDriveStrength = SI5351_DRIVE_STRENGTH_8MA,
    },
    {
        .minFreq  = 24890000,
        .maxFreq  = 24990000,
        .lastFreq = 24906000,
        .fastFreqs = { 24890000, 24906000, 24915000, 24931000, 24990000 },
        .lpf = USE_LPF_10_12,
        .bpf = USE_BPF_12,
        .txDriveStrength = SI5351_DRIVE_STRENGTH_8MA,
    },
    {
        .minFreq  = 28000000,
        .maxFreq  = 29700000,
        .lastFreq = 28060000,
        .fastFreqs = { 28000000, 28060000, 28070000, 28225000, 29000000 },
        .lpf = USE_LPF_10_12,
        .bpf = USE_BPF_10,
        .txDriveStrength = SI5351_DRIVE_STRENGTH_8MA,
    },
};

void ADC_Select_Channel(uint32_t ch) {
    ADC_ChannelConfTypeDef conf = {
        .Channel = ch,
        .Rank = 1,
        .SamplingTime = ADC_SAMPLETIME_28CYCLES_5,
    };
    if (HAL_ADC_ConfigChannel(&hadc1, &conf) != HAL_OK) {
        Error_Handler();
    }

    /*
     * Without this delay the next call of ADC_ReadVoltage()
     * may get a value from the previously used channel.
     * As a result updateSWRMeter() will see equal v_fwd
     * and v_ref, which results in a false high SWR value.
     * So keep the delay!
     */
    HAL_Delay(1);
} 

double ADC_ReadVoltage(uint32_t ch) {
    ADC_Select_Channel(ch);
    HAL_ADC_PollForConversion(&hadc1, HAL_MAX_DELAY);
    return ((double)HAL_ADC_GetValue(&hadc1))*3.3/4096.0;
}

// http://en.wikipedia.org/wiki/Jenkins_hash_function
uint32_t jenkinsHash(const uint8_t *data, const size_t len) {
    uint32_t hash, i;
    for(hash = i = 0; i < len; ++i) {
        hash += data[i];
        hash += (hash << 10);
        hash ^= (hash >> 6);
    }
    hash += (hash << 3);
    hash ^= (hash >> 11);
    hash += (hash << 15);
    return hash;
}

void loadKeyerMessage() {
    HAL_StatusTypeDef status;
    uint16_t savedChecksum;
    KeyerMessage_t savedKeyerMessage;

    for(;;) {
        status = HAL_I2C_IsDeviceReady(&hi2c1, eeprom_i2c_addr, 3, HAL_MAX_DELAY);
        if(status == HAL_OK)
            break;
    }

    HAL_I2C_Mem_Read(&hi2c1, eeprom_i2c_addr, KEYER_MESSAGE_EEPROM_ADDR, I2C_MEMADD_SIZE_16BIT,
            (uint8_t*)&savedKeyerMessage, sizeof(savedKeyerMessage), HAL_MAX_DELAY);

    savedChecksum = savedKeyerMessage.checksum;
    savedKeyerMessage.checksum = 0;

    if((jenkinsHash((const uint8_t*)&savedKeyerMessage, sizeof(savedKeyerMessage)) & 0xFFFF) == savedChecksum) {
        keyerMessage = savedKeyerMessage;
    } else {
        LCD_Goto(0, 0);
        LCD_SendString("MSG HASH");
        LCD_Goto(1, 0);
        LCD_SendString(" ERROR! ");
        HAL_Delay(2000);
        LCD_Clear();
    }
}

void saveKeyerMessage() {
    HAL_StatusTypeDef status;
    uint16_t checksum;
    size_t bytes_to_write = sizeof(keyerMessage);
    uint8_t* struct_offset = (uint8_t*)&keyerMessage;
    uint16_t eeprom_addr = KEYER_MESSAGE_EEPROM_ADDR;

    keyerMessage.checksum = 0;
    checksum = (jenkinsHash((const uint8_t*)&keyerMessage, sizeof(keyerMessage)) & 0xFFFF);
    keyerMessage.checksum = checksum;

    // sizeof(keyerMessage) exceeds EEPROM_PAGE_SIZE
    // so we have to write it in batches
    while(bytes_to_write > 0) {
        size_t batch_size = bytes_to_write;
        if(batch_size > EEPROM_PAGE_SIZE) {
            batch_size = EEPROM_PAGE_SIZE;
        }

        for(;;) {
            status = HAL_I2C_IsDeviceReady(&hi2c1, eeprom_i2c_addr, 3, HAL_MAX_DELAY);
            if(status == HAL_OK)
                break;
        }

        HAL_I2C_Mem_Write(&hi2c1, eeprom_i2c_addr, eeprom_addr, I2C_MEMADD_SIZE_16BIT,
            struct_offset, batch_size, HAL_MAX_DELAY);

        bytes_to_write -= batch_size;
        struct_offset += batch_size;
        eeprom_addr += batch_size;
    }
}

void loadKeyerConfig() {
    HAL_StatusTypeDef status;
    uint16_t savedChecksum;
    KeyerConfig_t savedKeyerConfig;

    for(;;) {
        status = HAL_I2C_IsDeviceReady(&hi2c1, eeprom_i2c_addr, 3, HAL_MAX_DELAY);
        if(status == HAL_OK)
            break;
    }

    HAL_I2C_Mem_Read(&hi2c1, eeprom_i2c_addr, KEYER_CONFIG_EEPROM_ADDR, I2C_MEMADD_SIZE_16BIT,
        (uint8_t*)&savedKeyerConfig, sizeof(savedKeyerConfig), HAL_MAX_DELAY);

    savedChecksum = savedKeyerConfig.checksum;
    savedKeyerConfig.checksum = 0;

    if((jenkinsHash((const uint8_t*)&savedKeyerConfig, sizeof(savedKeyerConfig)) & 0xFFFF) == savedChecksum) {
        keyerConfig = savedKeyerConfig;
    } else {
        LCD_Goto(0, 0);
        LCD_SendString("CFG HASH");
        LCD_Goto(1, 0);
        LCD_SendString(" ERROR! ");
        HAL_Delay(2000);
        LCD_Clear();
    }
}

void saveKeyerConfig() {
    HAL_StatusTypeDef status;
    uint16_t checksum;
    keyerConfig.checksum = 0;

    checksum = (jenkinsHash((const uint8_t*)&keyerConfig, sizeof(keyerConfig)) & 0xFFFF);
    keyerConfig.checksum = checksum;

    for(;;) {
        status = HAL_I2C_IsDeviceReady(&hi2c1, eeprom_i2c_addr, 3, HAL_MAX_DELAY);
        if(status == HAL_OK)
            break;
    }

    HAL_I2C_Mem_Write(&hi2c1, eeprom_i2c_addr, KEYER_CONFIG_EEPROM_ADDR, I2C_MEMADD_SIZE_16BIT,
        (uint8_t*)&keyerConfig, sizeof(keyerConfig), HAL_MAX_DELAY);
}

void changeKeyerSpeed(int32_t delta) {
    keyerConfig.speedWPM += delta;
    if(keyerConfig.speedWPM < 10) {
        keyerConfig.speedWPM = 10;
        keyerConfig.straightKey = true;
        keyerConfig.ditTimeMs = 60*1000/(50*(17+1)); // as for 17 WPM, for XMIT
    } else {
        keyerConfig.straightKey = false;
        if(keyerConfig.speedWPM > 30) {
            keyerConfig.speedWPM = 30;
        }

        /* +1 compensates the signal rise/fall time */
        keyerConfig.ditTimeMs = 60*1000/(50*(keyerConfig.speedWPM + 1));
    }
}

void SetupCLK(uint8_t output, int32_t Fclk, si5351DriveStrength_t driveStrength) {
    static bool pllSetupDone = false;
    si5351PLLConfig_t pll_conf;
    si5351OutputConfig_t out_conf;

    si5351_Calc(Fclk, &pll_conf, &out_conf);
    if(!pllSetupDone) {
        si5351_SetupPLL(SI5351_PLL_A, &pll_conf);
        pllSetupDone = true;
    }
    si5351_SetupOutput(output, SI5351_PLL_A, driveStrength, &out_conf);
}

void enableTx(bool enable) {
    // ENABLE_TX_12V
    HAL_GPIO_WritePin(GPIOB, GPIO_PIN_15, enable ? GPIO_PIN_SET : GPIO_PIN_RESET);
}

void switchBFO(bool enable) {
    /*
     *  enable - use high frequency BFO, e.g. 9_000_633
     * !enable - use  low frequency BFO, e.g. 8_997_600
     */
    HAL_GPIO_WritePin(GPIOA, GPIO_PIN_7, enable ? GPIO_PIN_SET : GPIO_PIN_RESET);
}

bool enabledSSBMode() {
    /*
     * B4 is low  - SSB mode
     * B4 is high -  CW mode
     */
    return (HAL_GPIO_ReadPin(GPIOB, GPIO_PIN_4) == GPIO_PIN_RESET);
}

void changeFrequency(int32_t delta, bool tx, bool force) {
    static int32_t prevFvfo = 0;

    if((!force) && lockMode) {
        return;
    }

    if(fastMode) {
        delta *= 10;
    }
    bands[currentBand].lastFreq += 100*delta;
    if(fastMode && (delta != 0)) {
        bands[currentBand].lastFreq -= bands[currentBand].lastFreq % 1000;
    }

    if(bands[currentBand].lastFreq < bands[currentBand].minFreq) {
        bands[currentBand].lastFreq = bands[currentBand].minFreq;
    } else if(bands[currentBand].lastFreq > bands[currentBand].maxFreq) {
        bands[currentBand].lastFreq = bands[currentBand].maxFreq;
    }

    if(enabledSSBMode()) {
        if((currentBand == 0) || (currentBand == 1)) {
            /* Low frequency BFO is used on 80 and 40 meters */
            Fvfo = bands[currentBand].lastFreq + SSBFilterLowFrequency;
        } else {
            Fvfo = bands[currentBand].lastFreq + SSBFilterHighFrequency;
        }
    } else {
        // this path is executed only when receiving CW
        Fvfo = bands[currentBand].lastFreq + CWFilterCenterFrequency;
    }

    if(tx) {
        // this path is executed only when transmitting SSB
        if(clarMode == CLAR_MODE_XIT) {
            Fvfo += clarOffset;
        }
    } else {
        if(clarMode == CLAR_MODE_RIT) {
            Fvfo += clarOffset;
        }
    }

    if(force || (Fvfo != prevFvfo)) {
        SetupCLK(CH_VFO, Fvfo, VFODriveStrength);
    }

    prevFvfo = Fvfo;
}

void checkIfRxModeHasChanged() {
    static bool firstCall = true;
    static bool prevBFOSwitch = false;
    static bool prevSSBMode = false;
    
    bool ssbMode = enabledSSBMode();

    /*
     * use high frequency BFO (i.e. spectrum inversion)
     * for SSB on bands other than 80 and 40 meters
     */
    bool bfoSwitch = ssbMode && (currentBand != 0) && (currentBand != 1);

    if((prevBFOSwitch != bfoSwitch) || firstCall) {
        switchBFO(bfoSwitch);
        prevBFOSwitch = bfoSwitch;
    }

    if((prevSSBMode != ssbMode) || firstCall) {
        changeFrequency(0, false, true);
        // ENABLE_SSB_12V
        HAL_GPIO_WritePin(GPIOB, GPIO_PIN_14, ssbMode ? GPIO_PIN_SET : GPIO_PIN_RESET);
        prevSSBMode = ssbMode;
    }

    firstCall = false;
}

void displayFrequency() {
    char buff[16];
    snprintf(buff, sizeof(buff), "%02ld.%03ld.%01ld",
        bands[currentBand].lastFreq / 1000000,
        (bands[currentBand].lastFreq % 1000000) / 1000,
        (bands[currentBand].lastFreq % 1000) / 100);

    LCD_Goto(0, 0);
    LCD_SendString(buff);
}

bool buttonDitPressed() {
    return (HAL_GPIO_ReadPin(GPIOB, GPIO_PIN_12) == GPIO_PIN_RESET);
}

bool buttonDahPressed() {
    return (HAL_GPIO_ReadPin(GPIOB, GPIO_PIN_13) == GPIO_PIN_RESET);
}

void displaySMeterOrMode(bool force) {
    static const char* prevSValue = NULL;
    static uint32_t lastSMeterUpdateTime = 0;
    // don't forget to add '-u _printf_float' to LDFLAGS
    char buff[16];

    if(force) {
        LCD_Goto(1, 0);
        if(fastMode) {
            LCD_SendString("= FAST =");
            return;
        } else if(lockMode) {
            LCD_SendString("= LOCK =");
            return;
        } else if(clarMode != CLAR_MODE_DISABLED) {
            snprintf(buff, sizeof(buff), "%s%s%04d",
                clarMode == CLAR_MODE_RIT ? "RIT" : "XIT",
                clarOffset < 0 ? "-" : "+",
                abs(clarOffset));
            LCD_SendString(buff);
            return;
        }
    }

    uint32_t tstamp = HAL_GetTick();
    if(force || (tstamp - lastSMeterUpdateTime > 500)) {
        const char* sValue = NULL;
        double voltage = ADC_ReadVoltage(ADC_CHANNEL_2);

        if(voltage <= 0.035) {
            sValue = "S0      ";
        } else if(voltage <= 0.038) {
            sValue = "S1      ";
        } else if(voltage <= 0.043) {
            sValue = "S2\x02     ";
        } else if(voltage <= 0.048) {
            sValue = "S3\x02     ";
        } else if(voltage <= 0.080) {
            sValue = "S4\x02\x03    ";
        } else if(voltage <= 0.240) {
            sValue = "S5\x02\x03    ";
        } else if(voltage <= 0.700) {
            sValue = "S6\x02\x03\x04   ";
        } else if(voltage <= 1.750) {
            sValue = "S7\x02\x03\x04\x05  ";
        } else if(voltage <= 2.400) {
            sValue = "S8\x02\x03\x04\x05\x06 ";
        } else if(voltage <= 2.500) {
            sValue = "S9\x02\x03\x04\x05\x06\x07";
        } else {
            sValue = "S+\x02\x03\x04\x05\x06\x07";
        }

        if(force || (prevSValue != sValue)) {
            // Don't re-render the S-meter if we are about to transmit
            if(!buttonDitPressed() && !buttonDahPressed()) {
                LCD_Goto(1, 0);
                LCD_SendString(sValue);
            }
        }

        prevSValue = sValue;
        lastSMeterUpdateTime = tstamp;
    }
}

void keyDown() {
    if(inTransmitMode) {
        // enable CH_CW
        si5351_EnableOutputs(1 << CH_CW);

        // ENABLE_KEYED_VCC
        HAL_GPIO_WritePin(GPIOC, GPIO_PIN_14, GPIO_PIN_SET);
    }

    // CW tone ON
    HAL_GPIO_WritePin(GPIOC, GPIO_PIN_13, GPIO_PIN_SET);
}

void keyUp() {
    if(inTransmitMode) {
        // disable CH_CW, but only during actual TX
        // e.g. not during playbackSavedMessage()
        si5351_EnableOutputs(0);
    }

    // make sure ENABLE_KEYED_VCC is low regardless of inTransmitMode value
    HAL_GPIO_WritePin(GPIOC, GPIO_PIN_14, GPIO_PIN_RESET);

    // CW tone OFF
    HAL_GPIO_WritePin(GPIOC, GPIO_PIN_13, GPIO_PIN_RESET);
}

void switchLPFs(UseLPF_t lpf) {
    HAL_GPIO_WritePin(GPIOC, GPIO_PIN_15, lpf == USE_LPF_10_12 ? GPIO_PIN_SET : GPIO_PIN_RESET);
    HAL_GPIO_WritePin(GPIOA, GPIO_PIN_3, lpf == USE_LPF_15_17 ? GPIO_PIN_SET : GPIO_PIN_RESET);
    HAL_GPIO_WritePin(GPIOA, GPIO_PIN_4, lpf == USE_LPF_20_30 ? GPIO_PIN_SET : GPIO_PIN_RESET);
    HAL_GPIO_WritePin(GPIOA, GPIO_PIN_5, lpf == USE_LPF_40 ? GPIO_PIN_SET : GPIO_PIN_RESET);
    HAL_GPIO_WritePin(GPIOA, GPIO_PIN_6, lpf == USE_LPF_80 ? GPIO_PIN_SET : GPIO_PIN_RESET);
}

void switchBPFs(UseBPF_t bpf) {
    switch(bpf) {
    case USE_BPF_10:
        HAL_GPIO_WritePin(GPIOB, GPIO_PIN_5, GPIO_PIN_RESET);
        HAL_GPIO_WritePin(GPIOB, GPIO_PIN_6, GPIO_PIN_RESET);
        HAL_GPIO_WritePin(GPIOB, GPIO_PIN_7, GPIO_PIN_RESET);
        break;
    case USE_BPF_12:
        HAL_GPIO_WritePin(GPIOB, GPIO_PIN_5, GPIO_PIN_SET);
        HAL_GPIO_WritePin(GPIOB, GPIO_PIN_6, GPIO_PIN_RESET);
        HAL_GPIO_WritePin(GPIOB, GPIO_PIN_7, GPIO_PIN_RESET);
        break;
    case USE_BPF_15:
        HAL_GPIO_WritePin(GPIOB, GPIO_PIN_5, GPIO_PIN_RESET);
        HAL_GPIO_WritePin(GPIOB, GPIO_PIN_6, GPIO_PIN_SET);
        HAL_GPIO_WritePin(GPIOB, GPIO_PIN_7, GPIO_PIN_RESET);
        break;
    case USE_BPF_17:
        HAL_GPIO_WritePin(GPIOB, GPIO_PIN_5, GPIO_PIN_SET);
        HAL_GPIO_WritePin(GPIOB, GPIO_PIN_6, GPIO_PIN_SET);
        HAL_GPIO_WritePin(GPIOB, GPIO_PIN_7, GPIO_PIN_RESET);
        break;
    case USE_BPF_20:
        HAL_GPIO_WritePin(GPIOB, GPIO_PIN_5, GPIO_PIN_RESET);
        HAL_GPIO_WritePin(GPIOB, GPIO_PIN_6, GPIO_PIN_RESET);
        HAL_GPIO_WritePin(GPIOB, GPIO_PIN_7, GPIO_PIN_SET);
        break;
    case USE_BPF_30:
        HAL_GPIO_WritePin(GPIOB, GPIO_PIN_5, GPIO_PIN_SET);
        HAL_GPIO_WritePin(GPIOB, GPIO_PIN_6, GPIO_PIN_RESET);
        HAL_GPIO_WritePin(GPIOB, GPIO_PIN_7, GPIO_PIN_SET);
        break;
    case USE_BPF_40:
        HAL_GPIO_WritePin(GPIOB, GPIO_PIN_5, GPIO_PIN_RESET);
        HAL_GPIO_WritePin(GPIOB, GPIO_PIN_6, GPIO_PIN_SET);
        HAL_GPIO_WritePin(GPIOB, GPIO_PIN_7, GPIO_PIN_SET);
        break;
    default: // USE_BPF_80
        HAL_GPIO_WritePin(GPIOB, GPIO_PIN_5, GPIO_PIN_SET);
        HAL_GPIO_WritePin(GPIOB, GPIO_PIN_6, GPIO_PIN_SET);
        HAL_GPIO_WritePin(GPIOB, GPIO_PIN_7, GPIO_PIN_SET);
        break;
    }
}

void changeBand(int32_t delta) {
    currentBand += delta;
    while(currentBand < 0) {
        currentBand += sizeof(bands)/sizeof(bands[0]);
    }
    currentBand %= sizeof(bands)/sizeof(bands[0]);

    switchBPFs(bands[currentBand].bpf);
    switchLPFs(bands[currentBand].lpf);

    changeFrequency(0, false, false);
    si5351_EnableOutputs(1 << CH_VFO);
    displayFrequency();
}

void ensureTransmitMode() {
    if(inTransmitMode) {
        return;
    }

    if(transmittingSSB) {
        // changes VFO frequency accordingly
        changeFrequency(0, true, true);

        // ENABLE_KEYED_VCC
        HAL_GPIO_WritePin(GPIOC, GPIO_PIN_14, GPIO_PIN_SET);
    } else {
        int32_t targetFrequency = bands[currentBand].lastFreq;
        if(clarMode == CLAR_MODE_XIT) {
            targetFrequency += clarOffset;
        }

        SetupCLK(CH_CW, targetFrequency, bands[currentBand].txDriveStrength);
        keyUp(); // calls si5351_EnableOutputs()
    }

    enableTx(true);

    LCD_Goto(1, 0);
    LCD_SendString("SWR  ---");

    inTransmitMode = true;
}
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
int main(void)
{
  /* MCU Configuration--------------------------------------------------------*/

  /* Reset of all peripherals, Initializes the Flash interface and the Systick. */
  HAL_Init();

  /* Configure the system clock */
  SystemClock_Config();

  /* Initialize all configured peripherals */
  MX_GPIO_Init();
  MX_TIM1_Init();
  MX_I2C1_Init();
  MX_ADC1_Init();
  MX_TIM2_Init();
  /* USER CODE BEGIN 2 */
  init();
  /* USER CODE END 2 */

  /* Infinite loop */
  /* USER CODE BEGIN WHILE */
  while (1)
  {
    loopMain();
    /* USER CODE END WHILE */

    /* USER CODE BEGIN 3 */

  }
  /* USER CODE END 3 */
}

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


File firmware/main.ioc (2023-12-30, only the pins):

Mcu.UserName=STM32F103C8Tx
PA0-WKUP.Signal=ADCx_IN0
PA1.Signal=ADCx_IN1
PA10.Signal=GPIO_Input
PA11.Signal=GPIO_Input
PA12.Signal=GPIO_Input
PA13.Signal=SYS_JTMS-SWDIO
PA14.Signal=SYS_JTCK-SWCLK
PA15.Signal=S_TIM2_CH1_ETR
PA2.Signal=ADCx_IN2
PA3.Signal=GPIO_Output
PA4.Signal=GPIO_Output
PA5.Signal=GPIO_Output
PA6.Signal=GPIO_Output
PA7.Signal=GPIO_Output
PA8.Signal=S_TIM1_CH1
PA9.Signal=S_TIM1_CH2
PB0.Signal=GPIO_Input
PB1.Signal=GPIO_Input
PB10.Signal=GPIO_Input
PB11.Signal=GPIO_Input
PB12.Signal=GPIO_Input
PB13.Signal=GPIO_Input
PB14.Signal=GPIO_Output
PB15.Signal=GPIO_Output
PB3.Signal=S_TIM2_CH2
PB4.Signal=GPIO_Input
PB5.Signal=GPIO_Output
PB6.Signal=GPIO_Output
PB7.Signal=GPIO_Output
PB8.Signal=I2C1_SCL
PB9.Signal=I2C1_SDA
PC13-TAMPER-RTC.Signal=GPIO_Output
PC14-OSC32_IN.Signal=GPIO_Output
PC15-OSC32_OUT.Signal=GPIO_Output
PD0-OSC_IN.Signal=RCC_OSC_IN
PD1-OSC_OUT.Signal=RCC_OSC_OUT

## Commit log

2023-12-09 Add OpenSCAD & STL enclosure files
    [back.stl, bottom.stl, enclosure.scad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]
2023-12-09 Add KiCAD project
    [af-amplifier.kicad_sch, agc.kicad_sch, bfo.kicad_sch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]
2023-12-11 Correct VFO frequencies + fix typo
    [main.c]
2023-12-11 Calibrate the S-meter
2023-12-11 Schematic: add S-meter
    [af-amplifier.kicad_sch, hbr-mk2.kicad_sch]
2023-12-11 Fix typo
    [af-amplifier.kicad_sch]
2023-12-15 Add CW tone generator + other changes
    [af-amplifier.kicad_sch, cw-tone.kicad_sch, hbr-mk2.kicad_sch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]
2023-12-15 Minor changes
    [cw-tone.kicad_sch]
2023-12-15 Make CW tone frequency adjustable
    [cw-tone.kicad_sch]
2023-12-15 Power S-meter from 8V
    [af-amplifier.kicad_sch]
2023-12-18 Stop transmitting when user switches the mode
2023-12-18 Checking if mode has changed while transmitting is not very useful in practice, so revert this
    [main.c]
2023-12-18 Add /TX Common/ schematic sheet
    [bpf-relays.kicad_sch, cw-tx.kicad_sch, hbr-mk2.kicad_sch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]
2023-12-18 Schematic: minor changes
    [hbr-mk2.kicad_sch, rx.kicad_sch, tx-common.kicad_sch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]
2023-12-18 Use 4 dB attenuator for CLK_CW instead of 3 dB one + minor changes
    [xtal-filters.kicad_sch]
2023-12-18 Use 6 dB attenuator for CLK_CW
    [xtal-filters.kicad_sch]
2023-12-21 Update schematic + minor changes
    [tx-common.kicad_sch, xtal-filters.kicad_sch]
2023-12-21 Update schematic
    [tx-common.kicad_sch]
2023-12-21 Add 1.3K resistor before the volume control pot
    [af-amplifier.kicad_sch]
2023-12-23 Connect relay contact groups in parallel where appropriate
    [bfo.kicad_sch, bpf-relays.kicad_sch, rx.kicad_sch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]
2023-12-23 Add PA schematic + some minor changes
    [agc.kicad_sch, hbr-mk2.kicad_sch, power-amplifier.kicad_sch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]
2023-12-23 Schematic: minor fixes
    [agc.kicad_sch, bfo.kicad_sch, power-amplifier.kicad_sch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]
2023-12-23 Add diodes for BPF relays
    [bpf-relays.kicad_sch]
2023-12-24 Schematic: add low pass filters
    [hbr-mk2.kicad_sch, lpfs.kicad_sch]
2023-12-24 Schematic: add relays to /LPFs/ sheet
    [hbr-mk2.kicad_sch, lpfs.kicad_sch, power-amplifier.kicad_sch]
2023-12-25 Schematic: simplify 80M LPF
    [lpfs.kicad_sch]
2023-12-26 Schematic: correct number of turns for LPF inductors
    [lpfs.kicad_sch]
2023-12-27 Firmware: correct LPF switching
    [main.c]
2023-12-28 Add lpfs/*.png, power/cw/*.png
2023-12-30 Firmware: use lower clock speed to reduce digital noise
    [main.c, main.ioc]
2023-12-30 Use standard I2C speed + tweak LOOP_DELAY
2023-12-30 Revert "Firmware: further reduce clock speed"
    This reverts commit 10d4aec0e390a78ca015cad832a2514f9e4502a8.
    [main.c, main.ioc]
2023-12-30 Schematic: add a bit more 0.1u capacitors
    [bpf-relays.kicad_sch, xtal-filters.kicad_sch]
2024-01-02 Schematic: add SWR bridge
    [hbr-mk2.kicad_sch, lpfs.kicad_sch, swr-bridge.kicad_sch]
2024-01-03 Update enclosure
    [back.stl, enclosure.scad, front.stl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]
2024-01-10 Add /TX SSB/ sheet
    [hbr-mk2.kicad_sch, tx-ssb.kicad_sch, xtal-filters.kicad_sch]
2024-01-22 Remove /CW TX/ sheet
    [cw-tx.kicad_sch]
2024-01-30 Move PCB KiCad projects and gerber files from a sandbox repository
    [af-amplifier.kicad_sch, agc.kicad_sch, bfo.kicad_sch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]
2024-04-24 Update firmware according to the recent PCB changes
2024-04-25 Digital board: correct the silkscreen
    [hbr-mk2-digital.kicad_pcb]
2024-04-25 AF PCB: fix typo
    [hbr-mk2-af.kicad_sch]
2024-04-26 Mark C3,C4,C7,C8 as DNP
    [hbr-mk2-digital.kicad_sch]
2024-04-26 Bump Digital PCB revision
    [hbr-mk2-digital.kicad_pcb, hbr-mk2-digital.kicad_sch]
2024-04-30 Update firmware according to the recent changes in the schematic
2024-04-30 Add a little hint to RXTX PCB schematic
    [tx-ssb.kicad_sch]
2024-04-30 Allow using NEXT/PREV buttons in FAST mode
2024-05-06 LPFs: update R11,R12 values
    [hbr-mk2-lpfs.kicad_sch]
2024-05-06 Update images/power/cw/*
2024-05-06 Add images/power/ssb/*
2024-05-06 Rename images/power/ssb/*.png files
2024-05-12 Add images/enclosure/*.jpg
2024-05-20 Various minor improvements
    [hbr-mk2-af-bom.csv, hbr-mk2-bfo-bom.csv, hbr-mk2-bfo.kicad_sch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]
2024-05-23 Add a few comments about the compression to the schematic
    [tx-ssb.kicad_sch]
2024-05-24 Add a warning about crappy ADE-1-24 mixers
    [hbr-mk2-rxtx.kicad_sch]
2024-05-26 Fix page 15 of the schematic

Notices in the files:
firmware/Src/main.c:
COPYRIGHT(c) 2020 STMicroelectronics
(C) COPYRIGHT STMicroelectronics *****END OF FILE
